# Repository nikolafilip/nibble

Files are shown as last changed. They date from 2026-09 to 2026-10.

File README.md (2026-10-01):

# Nibble

A 4-bit computer built from individual transistors, in public.

No integrated circuits anywhere. Transistors, resistors, diodes, capacitors,
LEDs, switches, connectors and wire. Every board is designed in KiCad,
simulated in ngspice, fabricated as a through-hole PCB and hand-soldered.

An AI (Claude) does the schematic generation, simulation and layout.
Nikola sets the constraints, reviews, orders, solders and measures.
The commit trailers say which is which.

## Layout

| Path | What |
|---|---|
| `docs/` | Architecture, instruction set, bus header, gate cell, build plan, decision ledger, known issues |
| `boards/00-origin-calculator/` | The hand-made 3-bit add/subtract calculator this started from, untouched |
| `boards/01-alu/` | 4-bit ALU: add, subtract, and, or, xor, increment, decrement, with flags |
| `boards/02-registers/` | A, B and OUT registers |
| `boards/03-sequencer/` | Step counter, instruction and operand registers, flags, decoders and the diode control matrix |
| `boards/04-program/` | Program memory: 16 words on DIP switches, one page of 256; build more for longer programs |
| `boards/05-clock/` | Clock with a speed knob, RUN/STEP, halt and power-on reset |
| `boards/06-panel/` | Front panel: switches for every line, LEDs on every line, the input port |
| `boards/07-hub/` | Bus hub: power, pull-ups, eight slots |
| `boards/08-memory/` | Data memory: 16 slots of 4 bits, every cell with an LED |
| `boards/09-counter/` | 8-bit program counter and return register |
| `coupon/` | Gate-cell test board: measure the real cell before trusting anything |
| `lib/` | Shared SPICE models and KiCad libraries |
| `sim/` | Generators, testbenches, the emulator and the whole-machine simulation |
| `experiments/muldiv/` | A multiplier/divider designed on the original RTL calculator. Simulated, not built |

## Start here

1. `docs/architecture.md` — what the machine is and how the boards fit together.
2. `docs/isa.md` — the instruction set (31 instructions in 16 opcodes) and a worked program.
3. `docs/bus-header.md` — the 64-pin ribbon header every board shares.
4. `docs/gate-cell.md` — the one logic cell everything is made of.
5. `docs/plan.md` — the gates every board passes before copper exists, and the whole-machine simulation.
6. `docs/cards.md` — the machine as 100 x 100 mm cards on one crimped ribbon (2026-09-10 evening), and the order of work from here.
7. `docs/mounting.md` — the panel it stands on.
8. `docs/DECISIONS.md` — why things are the way they are, in order.

## Status

See `docs/DECISIONS.md` for the latest entry and `docs/KNOWN-ISSUES.md` for what is wrong.

## Licence

CERN-OHL-P-2.0 for the hardware, MIT-equivalent terms for the scripts. See `LICENSE`.

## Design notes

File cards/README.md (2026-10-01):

# Cards

The machine as 100 x 100 mm boards on one crimped ribbon (docs/cards.md, D042
to D045). Every card has the 64-pin bus header along its top edge, soldered on the
back (D059; pin 1 top left as the front sees the holes, `docs/bus-header.md`),
two M3 holes mid-height on the sides, 100 nF + 10 uF at the top
right, and its logic on the dense tile: 7.68 mm columns, one TO-92 per 5.08
mm row, the pull-up lying along the row above its stack, GND and +5V rails
alternating between the columns on the back. Generated by `sim/build_*_card.py`
from the gate lists in `sim/`; laid out and routed by `sim/pcb.py`. Do not
hand-edit the schematics. Each card's `fab/` folder has the gerbers and their
zip, two renders, the assembly drawing (`<card>-assembly.svg`: which value
goes where, the boards print none) and the parts list. The Nibble logo
(`lib/logo/nibble.png` traced by `sim/logo.py`) is on the sequencer's
front silkscreen alone, one maker's mark on the machine; the cards carry
their name.

| Card | Directory | Transistors | Bus signals | Neighbour link |
|---|---|---|---|---|
| Register bit 0..3 | `reg0` .. `reg3` | 99 each | in: BUS<i>#, CLK, AI, AO, BI, BO, BA, AB, OI. out: A<i>, B<i>. BUS<i># driven open-drain when AO or BO | none |
| ALU bit 0..3 | `alu0` .. `alu3` | 66, 68, 68, 73 | in: A<i>, B<i>, SUB, ONE, F1, F0, EO. out: BUS<i># (open drain); bit 3 also CF, ZF | 2x3: carry C<i+1> and zero-so-far ZS<i> to bit i+1 |
| Counter bit 0..7 | `ctr0` .. `ctr7` | 62 (59 for bit 7) | in: PCL, CLK, RST (bit 0 also PCE). out: PC<i> | 2x3: count carry TC<i+1> to bit i+1; 2x6 chained ribbon from the sequencer: OPR<i>, PCR, RAI |
| Memory control | `memctl` | 57 | in: BUS3..0#, MAI, MI, MO, CLK | 2x6 chained ribbon to the slot cards: MAR3..0 and complements, MIN, MON |
| Memory slot pair | `memslot` (x8) | 91 | BUS3..0# in (MI) and out (MO, open drain) | the ribbon from memory control; jumpers A3 A2 A1 pick the pair |
| Program, four words | `prog` (one per four words) | 41 + 32 diodes | in: PC7..0. out: M7..0 through diodes | none; jumpers P7 P6 P5 P4 G3 G2 pick the addresses 4c..4c+3 |
| Clock | `clock` | 15 + the Schmitt pair | in: HLT. out: CLK, RST | none |
| Hub | `hub` | 0 | every line, on two headers | none |
| Panel A, B, C | `panela`, `panelb`, `panelc` | 28, 20, 32 | A: A3..B0, SUB..AB switched and shown, D3..0 CF ZF CLK RST shown. B: OI..MAI, MI..INP switched and shown, CLK and RST buttons. C: PC7..0, M7..0 shown, DATA switches driven onto BUS# while INP | none |
| Coupon | `coupon` | 57 | power only (a 2-pin header for the bench supply) | none |

## Register bit cards (`reg0` .. `reg3`)

Bit i of the three registers on the bus: A and B (the ALU's operands) and
OUT (the display), as three master-slave D flip-flops with their input muxes
(A takes the bus when AI, B when AB, else holds; B takes the bus when BI, A
when BA, else holds; OUT takes the bus when OI, else holds), the bus driver,
and the card's own two-phase clock (PH1, PH2 from CLK, D033) and hold
decoders. Four designs, the bit baked in, because a bit is three bus lines
and two cards jumpered alike would fight over them. `sim/registers.build_bit`
is the same logic as board 02 sliced per bit; the boards' testbench and the
machine deck take the four cards as the group `regc`.

Verification (2026-09-10), from the kicad-cli exports of the four routed cards
on one bus (`sim/tb_registers.py cards`), the 113-step register script: every
value through A and B, A and B driven back, MOV, XCH, OUT, holds:

| Netlist | Corner | Result |
|---|---|---|
| kicad-cli exports, four cards | TYP, LO, HI | 113 / 113 each |
| kicad-cli exports, four cards | MIX seeds 1, 2, 3 | 113 / 113 each |
| gate list (`cards@dev`) | TYP, LO, HI, MIX 1, 2, 3 | 113 / 113 each |

Machine gate (2026-09-11): `sim/gate.py --boards alu,hub,regc`, all twelve
programs at TYP with the four cards in the deck, 0 mismatches each (fib 127
ticks, calc 616, lfsr 1497, sort 974, mul 314, the rest between).

Layout: each card routes DRC-clean in one freerouting pass (0 unconnected),
ERC clean, 10.3 of 11 tile columns used.

Reproduce from `sim/`:

```
python3 build_reg_card.py 0                    # and 1, 2, 3
<kicad python> pcb.py ../cards/reg0 reg0
python3 tb_registers.py cards out/tb_regcards --corner MIX --seed 2
python3 machine.py programs/fib.asm --boards alu,hub,regc --corner TYP
```

## ALU bit cards (`alu0` .. `alu3`)

Bit i of the ALU: the full adder/subtractor bit (B xor SUB, carry in from
bit i-1), AND, OR, XOR selected by F1 F0, and the open-drain bus driver
while EO. Bit 0 starts the carry with SUB and the zero chain; bit 3 ends
them in CF and ZF on the bus. The carry and zero-so-far run over a 2x3 IDC
link between neighbouring cards (`frame.card_links`: IN at the bottom left,
OUT at the bottom right). `sim/alu.build_bit` is board 01 sliced per bit;
the group `aluc` stands for the four cards in the machine deck.

Verification, from the kicad-cli exports of the four routed cards chained by
their links (`sim/tb_alu.py cards --cases exhaustive`): every A, B, SUB, ONE,
F1 F0 combination, 2304 cases.

| Netlist | Corner | Result |
|---|---|---|
| kicad-cli exports, four cards | TYP | 2304 / 2304, worst settle 54 us |
| kicad-cli exports, four cards | LO | 2304 / 2304, worst settle 28 us |
| kicad-cli exports, four cards | HI | 2304 / 2304, worst settle 90 us |
| kicad-cli exports, four cards | MIX seed 1 | 2304 / 2304, worst settle 69 us |
| gate list (`cards@dev`) | TYP | 2304 / 2304 |

Layout: alu0 and alu3 route in one freerouting pass; alu1 and alu2 needed
the 300-pass cap and the 0.6 mm via (their last net drops from the bus
header into the first column). All four DRC clean, 0 unconnected.

## Counter bit cards (`ctr0` .. `ctr7`)

Bit i of the program counter (count when PCE, load the jump target OPR<i>
when PCL, load the return address RA<i> when PCR, clear on RST) and of the
return register RA (a transparent latch open while RAI and PH1). The count
carry TC<i+1> = TC<i> and PC<i> runs over the 2x3 links; the sequencer's
operand and load lines come down a chained 2x6 ribbon (`frame.card_ribbon`),
each card taking its own OPR line. Group `ctrc`.

Verification: `call.asm` on the eight cards from the gate lists, 0
mismatches; the exports carry every program of the step 9 gate
(`sim/results/gate25_*.md`).

## Memory control and slot cards (`memctl`, `memslot`)

Control: the four-bit address register MAR (transparent latches open while
MAI and MPH) and the write and read gates MIN (low while MI and MPH) and
MON (low while MO), sent to the slot cards over a chained 2x6 ribbon with
MAR and its complements. MPH is a pulse in the middle of the tick (D054):
CLKD is CLK through 100k into 2.2 nF on the sheet, and MPH = NOR(CLK, NOT
CLKD) is high from the falling edge of CLK until CLKD decays past a
threshold, 60 to 350 us, so the address latch closes and the write ends
hundreds of microseconds before the next rising edge. The first card gated
both with PH1, the low half of CLK, which ends at the rising edge: with the
clock card's 35 us edge and the threshold spread between cards, the
sequencer stepped and the next tick's data reached the bus 10 us before this
card saw the edge, and the address latch took the data as the address (gcd,
list and logic at mixed seed 2 wrote slots 12, 9 and 15 instead of 0). Slot pair:
two 4-bit slots (even: MAR0 = 0, odd: MAR0 = 1) of the pair the three
jumpers select (A3 A2 A1: the centre pin to '1' where the address bit is 1),
eight cross-coupled cells with their write and read pull-downs, and an LED
per cell. One design, eight cards, jumpered 0 to 7. Group `memc`.

The jumpers bring MAR1..3 (or their complements) onto the card, so in the
deck they are ports of the slot subcircuit (`machine.ports_of`); left
inside they float, and every read came from slot pair 7.

Verification, `sim/tb_memory.py cards`: three fills of all sixteen slots
and reads back, single writes between reads, bus noise while nothing loads,
217 steps. `--race` is the edge as the memory card saw it in the machine:
CLK rises over 35 us, the bus switches 10 us into the rise and the control
lines 100 us after it (they lag every edge by 60 to 170 us).

| Netlist | Corner | Result |
|---|---|---|
| PH1-gated card (before D054), gate list, `--race` | TYP, HI, MIX 1, MIX 2 | 121, 121, 121, 170 / 217 (`sim/out/tb_memory_oldD054_race.log`) |
| PH1-gated card (before D054), gate list, `--race` | LO | 217 / 217 (the card sees the edge at 0.8 V, before the bus moves) |
| D054 card, gate list (`dev`) | TYP, LO, HI, MIX 1..4 | 217 / 217 each (`sim/out/tbmem54_dev.log`, `tbmem54_mix.log`) |
| D054 card, gate list (`dev`), `--race` | TYP, LO, HI, MIX 1..4 | 217 / 217 each |
| D054 card, kicad-cli exports, control + eight slot cards | TYP; `--race` TYP, LO, HI, MIX 1, MIX 2 | 217 / 217 each (`sim/out/tbmem54_cards.log`) |

Layout: both cards route DRC clean in one pass, 0 unconnected.

## Program card (`prog`)

Four words of eight DIP switches; a closed switch pulls its M line high
through a diode while the word's row is selected (3.3k row pull-ups, so a
row of eight ones still reads 3.8 V against the hub's 220k, D048). Six 1x3 jumpers strap the
card to its addresses: P7..P4 the page (PC7..4), G3 G2 the word group
(PC3..2), the centre pin to '1' where the address bit is 1; PC1..0 pick the
word. A program of n words takes ceil(n/4) cards (`list` 6, `sort` 20). In
the deck (`progc`) one copy per four words is instantiated with its jumpers
and switches set from the assembled program; `prog.map.json` says which
diode is word w bit i.

Verification: `fib.asm` on the card gate lists with the ALU and hub, 0
mismatches; the exports carry every program of the step 9 gate
(`sim/results/gate25_*.md`).

## Clock card (`clock`)

Board 05's circuit on a card: the source-coupled Schmitt RC oscillator with
the speed pot and SLOW jumper, the RUN/STEP switch, the halt gate, the
power-on reset, and the hold-off (`sim/clock.py`, drawn by
`build_clock_card.py`). The hold-off (D064): a 2N7000 from the oscillator's
timing node X to ground through 100 ohm, its gate on the RST line. While
RST is high the timing capacitor is held empty, the Schmitt trigger reads
low and the clock gate holds CLK low; when RST lets go, the card's own
reset or the panel's button, X charges from 0 V and the first clock edge
comes 1.3 to 5.7 ms later at the fastest setting (`sim/results/reset_release.md`,
`starts_hold.md`), never in the 45 us in which the cards leave their
resets, which had started the machine wrong once in a hundred times
(`sweep_por.md`). HLT
reaches the halt gate through 100k into 2.2 nF (0.22 ms, D050), so the
clock pulse that started the halt step completes before the clock stops.
CLK's pull-up in RUN is 1k and RST comes from a 1k inverter stage (RD = NOT
PB) through 100 ohm and a diode, against the panel's 10k pull-downs (D053):
into the machine's 3 nF CLK rises 0.5 to 3.5 V in about 6 us (the first card
took 35 to 43 us, and the cards, each reading the edge with its own
transistors, saw it up to 25 us apart) and RST releases in 45 us (the first
card's drifted for 8 ms and more, so cards left reset on different edges).
`sim/tb_clock.py` measures both under that load and requires them
(TYP, LO, HI, MIX 1..2 pass: `sim/out/tb_clock_cards54_*.log`; the first
card under the same bench: CLK rise 43 us, RST never released cleanly,
`sim/out/tb_clock_cards_oldD053_TYP.log`).
Deck name `clkc`. The step 9 gate runs with this card driving CLK and RST
and no testbench clock or reset, every deck a power-up from 0 V: all
thirteen programs at TYP and the 24 corners, 0 mismatches
(`sim/results/gate25_TYP.md`, `gate25_corners.md`). The first card, in the
same deck, passed all thirteen at TYP and lost gcd, list and logic at MIX
seed 2 to the address-latch race its slow edge opened
(`sim/results/gate_clk_corners_oldclock.md`, D053, D054).

## Hub card (`hub`)

Two bus headers, one along the top edge and one along the bottom, one per
column face's ribbon (D043), the 64 lines routed between them. Ground is
wired, not poured: a ring above the top header's pads, down the right edge
and below the bottom header's, with bars for the capacitors, the LED and
the M pull-downs (the lines cut a pour to islands). The bench supply's
banana leads into two 4 mm sockets standing on the front face (Cal Test
CT3151V1, soldered in on four pins, D063), 19.05 mm apart so a dual plug
fits (no USB, D057), through a 1.5 A polyfuse (D052) and past a crowbar
(D061: above 6.3 to 7.8 V a zener fires an SCR that holds the rail near
1 V; a 3 A diode takes crossed leads; `sim/results/crowbar.md`), the four bus pull-ups, the eight M-line pull-downs (220k, D048:
with 1 Meg an M line released by a jump took 0.6 ms to fall), a power LED,
100 uF, test loops on BUS3..0, CLK and RST, and an empty spot (C-RST,
do not populate) for a 2.2 nF from RST to ground should the scope show
more pickup on RST than the simulation says (bring-up section 9). Deck
name `hubc`.

## Panel cards (`panela`, `panelb`, `panelc`)

A: DIP-8 level switches for A3..A0 B3..B0 and SUB EO AI AO BI BO BA AB
(10k to +5V: a switch left on never fights a card pulling low), LEDs for
those lines, for the bus data (an inverter per BUS<i>#), CF, ZF, CLK and
RST. B: switches and LEDs for OI IO II PCE PCL FI HLT MAI and MI MO WRL
WRH ONE F0 F1 INP, and the CLK and RST buttons with their RC debounce and
Schmitt triggers (the second inverter has a 1k pull-up and drives the line
through 100 ohm and a diode, D053). C, the operator's card: PC7..0 and M7..0
LEDs, the four DATA switches and the input port (driven onto BUS# while
INP). Every switched or observed line has a 1Meg pull-down on the tile
(`PD` cells) except M, pulled down on the hub, and CLK and RST, whose
pull-downs on card A are 10k (D053: they set the falling edges of both
lines, 30 us into 3 nF). The LEDs read row by row like the old
panel: a tile column holds one panel column (three LEDs on A, two on B and
C). Group `pnl`.

## Coupon card (`coupon`)

Every cell in copper, each with a test loop, powered from a 2-pin header
on the bench supply or from the bus header (D056, `sim/coupon.py`,
`sim/build_coupon_card.py`): the 5-inverter ring (a buffered loop and a raw
one on the ring node), fan-out 1 and 10, 3-input NAND and NOR, a bus driver
with the hub-style 10k pull-up, the clock card's oscillator (the Schmitt
pair and its 100k + 47 nF, drawn on the sheet as on `clock`), a master-slave
flip-flop wired as a toggle with its asynchronous reset (RST on the input
header), the D053 line driver (1k inverter, 100 ohm, diode, 10k pull-down;
the bench clips 3.3 nF on its loop), a diode-connected transistor on 4.7k
that reads its own threshold, a program row (3.3k, 1N4148, 220k), an LED.
Inputs IN, N1..N3, RST on a 1x6 header with 1 Meg pull-downs (PD tiles);
fifteen loops including GND and +5V. 57 transistors on six tile columns,
routed in one freerouting pass, DRC clean.

`sim/tb_coupon.py kicad` simulates the routed card's export at TYP, LO, HI
and MIX seeds 1..3 with a x10 probe on every loop and writes the bands
the bench must land in: `sim/results/coupon_expected.md` (ring 5.9 to
23.6 us, fan-out-10 rise 67 to 77 us, oscillator 1.64 to 2.55 ms, Q at
half that, DRV rise 6.6 us and fall 49 us into 3.3 nF, VTO 0.88 to 3.02 V,
5 to 14 mA). `dev` runs the gate list plus the sheet-drawn parts and gives
the same numbers at the uniform corners, so the sheet matches the design.
Two things the testbench found that the bench should know: with
low-threshold transistors the ring swings only to about 2 V and a
high-threshold buffer never switches (hence the raw RING0 loop), and while
RST holds the flip-flop a pulse of up to 4 V and 10 us can appear on Q at a
rising clock edge at some threshold mixes (the master's release racing the
slave's copy; the machine's masters are closed then, and every MIX run of
the machine gate passed with it). Its own testbench sheet is excluded from
the board.

Reproduce from `sim/`:

```
python3 build_coupon_card.py
<kicad python> pcb.py ../cards/coupon coupon
python3 tb_coupon.py kicad out/tb_coupon --all
```

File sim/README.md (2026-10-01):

# sim: generators and testbenches

| File | What |
|---|---|
| `nmos.py` | The cell family: INV/NAND/NOR/BUS/LED cells, XOR and D flip-flop macros, fan-out, floating-input and node-name checks, SPICE emitter |
| `ksch.py`, `frame.py`, `knet.py` | KiCad 10 schematic writer (gate lists as cells, header, decoupling, indicators, testbench sources), the common board frame, netlist parser |
| `bus.py` | The 64-pin header pinout (docs/bus-header.md): `PINS` is what the header's pins carry, soldered on the back (D059, D062); `HOLES` is the table the copper was routed to |
| `alu.py`, `build_alu.py`, `tb_alu.py` | Board 01: logic, generator for `boards/01-alu/`, testbench (demo or exhaustive cases, TYP/LO/HI/MIX corners, dev netlist or kicad-cli export) |
| `registers.py`, `build_registers.py`, `tb_registers.py` | Board 02: logic, generator, testbench (a clocked script through every register path; `cards` runs it on the four bit cards) |
| `build_reg_card.py` | Register bit cards `cards/reg<i>/` (docs/cards.md) from `registers.build_bit`, on the dense tile (`ksch.DenseWriter`) in the 100 x 100 card frame (`frame.card_frame`) |
| `panel.py`, `build_panel.py` | Board 06: switches, buttons, LEDs, input port |
| `build_hub.py`, `coupon.py`, `build_coupon.py` | Board 07 (hub) and the gate coupon (`build_coupon_card.py`, `tb_coupon.py`: the coupon card and its expected readings, D056) |
| `plots_alu.py` | Transient plots from a testbench run |
| `emu.py` | Tick-accurate ISA emulator; the reference for the whole-machine simulation |
| `asm.py` | Assembler; `programs/*.asm` are the reference programs, `test_emu.py` runs them on the emulator |
| `machine.py` | The whole-machine deck: every existing board's export plus emulator stand-ins for the rest, one program, compared tick for tick |
| `gate.py` | The machine gate: every program, every corner, one summary table (`out/gate_<boards>.md`) |
| `pcb.py` | Placement, power rails, freerouting, DRC, fab outputs (run with KiCad's python). On a routed board, in place and without a re-route: `--silk` (the labels again from the plan, then `place_logo` where the plan asks for the logo (the sequencer's): icon and word where 27 x 8 mm is free and the icon alone otherwise, nearest the board's name; then `fit_silk`: every label to 1.0 mm where it has room, off pads, vias, outlines and the logo, out from under the parts), `--patch`, `--back-header` (the bus headers onto the back in the holes they have) |
| `bom.py` | The order's tables (boards to have made, parts to need and to buy with the spares rule, the pilot's parts) from the routed boards; the schematics' count and the boards' count must agree; `--write` puts them into `docs/order-1.md`, `--check` fails when the document is stale |
| `sweep_por.py` | The reset-release sweep: fib for 12 ticks on the whole card deck with the clock card's power-on reset released at 13 phases against the clock (`POR_V0`, `RESET_S` in `machine.py`), TYP and MIX seeds 1, 2; writes `out/sweep_por.md` |
| `tb_reset_release.py` | The hold-off (D064) on the clock card alone: power-on and 20 presses of the panel's RST button walked across the clock period, at six corners and four speeds, with the two parts and without. `HOLD=1` puts the same two parts into the machine deck, `RST_PRESS=down,up` a finger on the panel's RST button |
| `starts_hold.py` | The machine's starts with the hold-off in the deck (`HOLD=1`): every start of the reset sweep again at the `POR_V0` it had, a start at four more corners, and the panel's RST button pressed while the machine runs (`RST_PRESS`). fib for 12 ticks each; `END_AFTER_RELEASE=1` ends such a run 47 ms after RST fell for the last time. Writes `results/starts_hold.md` |
| `mix_order.json` | The order in which each board's transistors draw their models at a mixed corner (`machine.py --mix-order` wrote it from the schematics of 2026-09-29): kicad-cli lists symbols in the order of their ids, the builders draw ids at random, so a card built again would otherwise get another threshold on every transistor |
| `assembly.py` | The assembly drawing, `cards/<card>/fab/<card>-assembly.svg`: the front as the silk shows it, every part that is not the card's commonest resistor or a 2N7000 coloured and labelled with its value (the cards print none); written by `pcb.py` with the fab outputs (plain python3) |
| `order_check.py` | The order gate on a board's committed files (the 25 cards and the sequencer): clean tree, routed rules in the project file, ERC, DRC with parity, JLCPCB minimums (`jlcpcb.kicad_dru`), fab files and zip equal the board, outline and holes, every part's pads and polarity, the silkscreen (nothing clipped, the bus header on the back and the back says so, the logo where the plan asks), the assembly drawing is the board's, no copper of another net where a socket's nut or a standoff clamps. `--machine`: every bus header against `bus.py` and every link against its far end, pin by pin. `--selftest`: the rules against faults planted on purpose (plain python3) |
| `board_diff.py` | What changed on a routed board since a commit, measured: netlist, tracks, vias, holes, and every copper and mask gerber as what it draws (`gerber_diff.py`). The proof that goes with a change made in place |
| `rebuild_check.py` | Runs every builder into a scratch directory and compares its plan and netlist with the committed ones: a change made in place must be in the builder too |
| `logo.py` | `lib/logo/nibble.png` traced into `lib/nibble.pretty/Logo_Nibble.kicad_mod` (icon and word, 27 x 8 mm) and `Logo_Nibble_Icon.kicad_mod` (8 x 8): filled silkscreen polygons, holes slit in; the ribbon's lines print 0.39 mm wide, 0.24 mm apart, over the fab's 0.15 mm minimum (plain python3 with Pillow, numpy and potracer) |
| `silk_proof.py` | The print as the fab gets it, pads, mask and silkscreen without the parts, front and back, to `out/proof/`: for the eyes |
| `tb_rst_neighbour.py`, `tb_crowbar.py` | Benches outside the machine's logic: the reset line beside BUS1# on the ribbon (D062); the hub's crowbar and reverse diode (D061, models in `lib/power.lib`). Each writes its table to `results/` |
| `spicedat.py` | Fast reader for ngspice `wrdata` files |
| `out/` | Scratch (ignored by git). `out/cell.cir` characterises one cell |

Needs ngspice (`brew install ngspice`), numpy, matplotlib, and KiCad 10 for
`kicad-cli` and the shared symbol libraries.

Rules that the generator enforces are in `docs/gate-cell.md`. ngspice node
names are case-insensitive, so never create two nets that differ only by case.

## PCB flow

`pcb.py` (run with KiCad's bundled python, see the docstring) takes a project's
schematic and its `<name>.plan.json` (placements, silkscreen labels, power
rails; written by the `build_*.py` generators) and produces the `.kicad_pcb`:
footprints placed, power pre-routed, signals routed by freerouting (headless,
retried until DRC reports zero unconnected), a ground pour on the back, DRC, and
`fab/` outputs (gerbers, drill, BOM, position file, renders).

    <kicad>/python3 pcb.py ../boards/01-alu alu

The `fab/` outputs (gerbers, drill, BOM, position file, renders) are committed with the board, as built.

## Whole-machine simulation

    python3 machine.py programs/fib.asm --boards alu,hub,reg,panel [--corner MIX --seed 2] [--ticks 40]
    python3 gate.py --boards alu,hub,reg,panel -j 2          # all programs, all corners (two decks at a time on a 36 GB machine)
    python3 gate.py --boards aluc,hubc,regc,seq,ctrc,memc,progc,pnl --corners TYP -j 2     # the machine as cards
    python3 gate.py --boards aluc,hubc,regc,seq,ctrc,memc,progc,pnl,clkc --corners TYP -j 2 --ticks 12     # the smoke gate: first twelve ticks of every program, about three hours; run it before every long queue and after every harness change
    python3 gate.py --boards aluc,hubc,regc,seq,ctrc,memc,progc,pnl,clkc --corners LO,HI,MIX --seeds 1,2 -j 2 --resume out/ledger.jsonl     # a long gate keeps a ledger of finished runs: cut short, the same line picks up at the first run without a passing row

Board names: the nine boards (`alu`, `hub`, `reg`, `seq`, `ctr`, `mem`,
`prog`, `panel`, `clk`) and the cards (`reg0..3` or the group `regc`,
`alu0..3` / `aluc`, `ctr0..7` / `ctrc`, `memctl` + `memslot` / `memc`
(eight slot copies with their jumpers), `progc` (one program card per
four words, jumpered and switched from the program), `panela..c` / `pnl`,
`clkc`, `hubc`). A board named `x@dev` is taken from its gate list instead
of the schematic export, for trying a design before drawing it. The deck runs the clock at
1 ms per tick; a 130-tick program with three boards takes two to three
minutes per corner. Registers that have no reset (A, B, OUT) are compared only
from the tick after the program first writes them.

Things ngspice taught us, so nobody learns them twice: `pwl()` in a B-source
extrapolates outside its points; a B-source with a `?:` step inside it fails
with "timestep too small" sooner or later, use the `SW` switch model for an
ideal driver; a net named `PWL` cannot be probed.

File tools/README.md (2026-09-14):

# tools

`freerouting-1.9.0.jar` (5 MB) is not in git. Download it from
https://github.com/freerouting/freerouting/releases/tag/v1.9.0 and run it
with Java 21 (it needs a display session even in batch mode; no `-Djava.awt.headless`):

    java -jar tools/freerouting-1.9.0.jar -de board.dsn -do board.ses -mp 40

`sim/pcb.py` calls it for the cards. `freerouting-2.1.0.jar` (also not in
git, same releases page) is what the sequencer board needs: on that board
1.9 takes hours for a single pass (a thread dump shows it deep in the maze
search), while 2.1.0 does a pass in five to ten minutes. Tested 2026-09-11:
2.1.0 honours `-mp N`, stops after N passes and writes the SES with what it
has, and logs the unrouted count after every pass. A plan picks it with
`extra.router.jar = "freerouting-2.1.0.jar"` (the sequencer's does).
Neither version logs an unrouted count when it gives up early in the way
1.9 does on the cards, so KiCad's DRC is the gate in `pcb.py`.

`freerouting-2.4.1.jar` (same releases page) is what the sequencer uses now
(2026-09-13), and the hub since D052 (1.9 dropped a via inside the bundle of
64 bus lines there and shorted three nets; 2.4.1 routes it clean). It needs Java 25 (`sdk install java 25-tem`); `sim/pcb.py` takes
the JVM from `NIBBLE_JAVA`. Headless it honours `-mp N` and stops on its own
when the score has not improved for ten passes. Its optimizer stage can start
from an older, worse snapshot than the router's last pass and save that, so set
`router.optimizer.max_passes` to 0 in
`~/Library/Application Support/freerouting/freerouting.json`. Findings that
`pcb.py` encodes (plan `extra.router`): a layer marked `(type power)` in the
DSN breaks routing altogether (the ground layer stays a signal layer);
`exclude_nets` takes the power nets out of the router's network and leaves their
pre-routed copper as obstacles; `layer_order` lists the DSN layers so that the
even-indexed ones are the vertical ones (freerouting prefers vertical on even
indexes, horizontal on odd); `route_in1` lets the router use the ground layer,
the pour fills the rest; `attempts` retries from the routed state. The
autoroute settings block freerouting's parser accepts stops 2.1.0 dead (score
NaN), so `pcb.py` writes none.

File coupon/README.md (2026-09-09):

# Gate coupon

26 transistors on a small board: the cell in copper, measured before any other
board is trusted. Power on J1 (5 V), inputs on J2, scope probes on the test loops.

| Test point | What it measures |
|---|---|
| TP_RING | 5-inverter ring oscillator, buffered. Gate delay = period / 10 (simulated period 14 µs) |
| TP_FO1 | Inverter output driving 1 gate. Rise time at fan-out 1 (simulated 4 µs to 2.5 V) |
| TP_FO10 | Inverter output driving 10 gates. Rise time at fan-out 10 (simulated 28 µs) |
| TP_NAND | 3-input NAND, three transistors in series. Output low with N1=N2=N3=1 (simulated 0.9 mV) |
| TP_NOR | 3-input NOR. Output low (simulated 0.1 mV) |
| TP_BUS | Open-drain driver on IN with the hub's 10k pull-up |

Also: supply current with everything low, and the LED cell on IN.
Fill the measured column in `docs/gate-cell.md`. Generated by `sim/build_coupon.py`.

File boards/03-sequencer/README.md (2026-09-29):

# Board 03: sequencer

The control unit: step counter, instruction and operand registers, flags, two
decoders and the diode control matrix. 592 transistors, 354 resistors, 87
matrix diodes on 1035 crossings, 19 LEDs (counted on the routed board). The
program counter and the return register are on the counter cards (D035).

| | |
|---|---|
| Bus signals used | in: M0..M7, CF, ZF, CLK, RST. out: II, PCE, SUB, EO, AI, AO, BI, BO, BA, AB, OI, IO, PCL, FI, HLT, MAI, MI, MO, ONE, F0, F1, INP |
| Bus driven | BUS0#..BUS3# open-drain with OPR3..0 while IO (LDI, LOAD n, STORE n) |
| Link header (2x6) | to board 09: OPR0..OPR7, PCR, RAI, GND, GND |

How it runs an instruction (docs/isa.md):

- **Steps** are a one-hot ring of five flip-flops with asynchronous reset. S0
  loads IR and the operand's low nibble (`II`); S1 counts (`PCE`); S2, only for
  a two-word instruction, loads the second word (`OPI`, `PCE`); S3 and S4 drive
  the matrix rows. The `DONE` column returns the ring to S0.
- **IR and OPR** are transparent latches open while their load line and PH1
  are both high: they follow the memory word during the low half of the clock
  and are closed before the rising edge on which everything else changes.
- **Decoders**: IR3..0 to OP0#..OP15#, OPR3..0 to F0#..F15#, each through a
  pair of 2-to-4 predecoders so no NAND has more than two transistors in series.
- **Rows**: `NOR(OPn#, T3N)` for every opcode, `NOR(OP0#, Fn#, T3N)` for every
  family member, an S4 row for the four memory accesses, and for JC and JZ a
  second row that includes the latched flag; JNZ and JNC the same. 45 rows,
  10k pull-ups.
- **The matrix**: a diode from a row to a column pulls that control line high
  while the row is active. 23 columns with 1 Meg pull-downs: 19 go to the bus
  header, `PCL` too, `PCR` and `RAI` to the link, `DONE` back to the step ring.
  New instructions are diodes; rows OP8..OP15 are free.
- **Flags**: CFQ and ZFQ latched from the ALU while `FI` and PH1.

## Files

- `sequencer.kicad_sch`: generated by `sim/build_sequencer.py` from `sim/sequencer.py`. Do not hand-edit.
- `fab/sequencer-assembly.svg`: which crossing takes a diode and which resistor is not 47k (`sim/assembly.py sequencer`). On the board a crossing that takes a diode has a printed circle; the other 948 are bare pads.
- `fab/sequencer-gerbers.zip`: the eleven files the fab takes (four copper layers). `python3 sim/order_check.py sequencer` is the gate.
- `sequencer.kicad_pcb`, `fab/`: layout by `sim/pcb.py`. The matrix is laid out transposed: rows are vertical tracks at 3.81 mm pitch on the back, columns horizontal tracks at 10.16 mm on the front, a diode standing on each populated crossing.

## Verification

The machine gate (`sim/gate.py`): the reference programs on the kicad-cli
exports of ALU, registers, sequencer and counter with the hub, compared tick
for tick with `sim/emu.py`. Results are recorded in the commit that adds the
routed board.

D041 proof (2026-09-11): list.asm on alu, hub, registers, sequencer, counter and memory at the MIX corner, seed 3, the run that failed before the column buffers: 210 ticks, 0 mismatches (`sim/out/d041_list_MIX3.log`). Seeds 1 and 2 and the other programs are in the card gate.

Layout (D051, 2026-09-11, amended 2026-09-13): 245 x 255 mm on four layers, the tiles at the card pitch; layer 2 is a ground pour with a few routed tracks, layer 3 a third routing layer (two layers left the router about 100 nets short at this pitch and about 70 at 10.16 mm, D049). Routed with freerouting 2.4.1 (Java 25) with the layers ordered so that layers 3 and 4 route vertically and 1 and 2 horizontally, the power nets out of its network (the rails, stubs and vias are fixed copper) and the optimizer off. The matrix rows and columns are hidden from the router on the outer layers and a keepout fences the matrix, but the matrix diodes stay in the DSN with their pins off the nets, so layer 3 threads between their pads across it. Each matrix column tail ends on a fixed via 4.5 mm before the keepout with a short stub on layer 3, where the router picks it up on its vertical layer. The 45 row drivers stand under their matrix columns (three per tile column, left to right). The left field, 12 columns, is split: its right five columns start one tile row lower, leaving an 8 mm strip under the header's right half for the fan-out to pins 42 to 64, and the output buffers stand in the column under their own header pin; the 23 column buffers fill the columns beside the matrix, where the tails come out. The +5V feed runs along the top edge and down the right side of the board, never through the corridor between the left field and the matrix.

Routed board (2026-09-14, route v9): 0 unconnected, 0 DRC errors on the rules it was routed with (0.2 mm track, 0.15 mm clearance). The 132 warnings, read one by one on 2026-09-28: 59 dangling fixed stubs, by design (the 45 matrix column tails and the In2 stubs of the row tails the router did not need); 67 silkscreen overlaps (the printed circles of diodes on neighbouring crossings touch at 2.54 mm; two LED names touch a transistor's outline); 6 LED names clipped by a pad's mask opening (OPR0, OPR1, OPR3, OPR5, OPR6, ZFQ), which move in the silkscreen pass. One hand patch after the router, recorded in the plan (`extra.patches`) and applied by `pcb.py`: freerouting had hooked ENF across CFQ_m1 on layer 3 beside Q380. The SPICE export of this schematic is line for line the one the machine gate ran (resistor pin order aside): the tile mirroring of the re-placement is the only difference. Gate results on the card deck with this sequencer: all twelve programs at TYP, 0 mismatches (lfsr 1497 ticks, rerun with the virtual reset fixed in machine.py, `sim/out/cards_lfsr_TYP.log`); fib, alu, gcd, list, logic, call at LO, HI, MIX1 and MIX2: 24 of 24 runs, 0 mismatches (`sim/out/gate_cards_corners.log`); fib, list, logic, calc at TYP and LO with 500 pF per bus line: 8 of 8; fib and call with the clock card driving CLK: 0 mismatches (docs/cards.md step 9).

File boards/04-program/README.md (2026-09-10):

# Board 04: program memory

16 words of 8 bits on DIP switches: one page of the 256-word program space.
112 transistors, 69 resistors, 17 LEDs, 16 DIP-8 switches, 128 diodes.

| | |
|---|---|
| Bus signals used | in: PC0..PC7. out: M0..M7 through diodes (the hub holds M low; several pages OR together) |
| Headers | two 64-way, wired pin for pin in parallel (D039): the hub's ribbon on the left one, the next page's on the right one. Every line is carried, not only PC and M |
| Size | 216 x 250 mm (12 mm wider than the switch array needs, so both shrouded headers and the corner hole fit along the top edge) |

- **Word select**: PC3..0 through a 4-to-16 decoder.
- **Page compare**: four jumpers, one per bit of PC7..4. Pins 1-2 mean "this
  page has a 1 in that bit", pins 2-3 a 0. All four on 2-3 is page 0
  (addresses 0 to 15). PAGE = all four match.
- **Rows**: ROWn = word n selected and PAGE, 10k pull-ups. An LED per row
  shows the word being fetched.
- **Switches**: word n's DIP-8 has the row on one side and a diode from each
  switch to its M line on the other. Closed = 1. Bit 7 is the top switch (the
  top bit of the opcode); blank memory reads 0000 0000 = NOP.

More program space is more copies of this board, each strapped to its page
(D019), daisy-chained with 10 cm ribbons from one page's right header to the
next page's left header; only the first page runs a cable to the hub (D039).
`python3 sim/asm.py programs/<name>.asm` prints the switch pattern per word.

Generated by `sim/build_program.py` from `sim/program.py`; it also writes
`program.map.json` (which diode is which word and bit) so the machine
simulation can close the switches for a program. Machine gate: every program,
with the behavioural memory model replaced by one copy of this board per page.

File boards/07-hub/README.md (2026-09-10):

# Board 07: bus hub

No logic. USB-B power entry through a 750 mA polyfuse, a power LED, bulk
capacitance, the four 10k pull-ups for BUS0#..BUS3# (the only pull-ups on the
bus in the whole machine), test loops on the bus, clock and reset lines, and
eight identical 64-pin headers. Every board plugs in with a straight 64-way
ribbon cable. The USB plug is the power switch.

Generated by `sim/build_hub.py`. ERC clean.

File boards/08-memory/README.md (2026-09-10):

# Board 08: data memory

16 slots of 4 bits with its own address register. 747 transistors, 287
resistors, 68 LEDs: one per cell, so the memory is visible.

| | |
|---|---|
| Bus signals used | in: BUS0#..BUS3# (an address while MAI, data while MI), MAI, MI, MO, CLK |
| Bus driven | BUS0#..BUS3# open-drain with the addressed slot while MO |

- **Address register**: four transparent latches open while `MAI` and PH1. A
  memory instruction puts the address on the bus for its whole S3 tick (B for
  `LOAD [B]`, the operand for `LOAD n`), so the latch closes on it before the
  edge.
- **Decoder**: MAR3..0 to W0#..W15# through 2-to-4 predecoders. Per slot a
  write line WR = slot and `MI` and PH1, a read line RD = slot and `MO`.
  The write is gated by PH1 so it ends at the clock edge, before `MI` and
  the bus change (D037): the first design let the write line outlast the
  data by a few microseconds, and at the mixed-threshold corner the write
  stacks flipped cells with the next tick's bus data. The shared MI line has
  a 4.7k pull-up so the sixteen write lines drop within microseconds.
- **Cell**: two cross-coupled inverters. While WR, the bus data forces it:
  D pulls QN low (a 1), BUS# itself pulls Q low (a 0). While RD and Q, a
  two-transistor stack pulls the bus line low (reads a 1). Eight transistors,
  two resistors, one LED per bit; 512 transistors in the array.
- **No reset**: memory keeps its contents through RST and powers up random.
  Programs write before they read.

Generated by `sim/build_memory.py` from `sim/memory.py`.

Schematic gate: `sim/tb_memory.py` writes every slot three times (slot
number, its complement, a scrambled pattern), reads everything back, and
interleaves single writes with reads of untouched slots: 217 steps, the bus
and the control lines changing at the same instant, which is the worst case
the machine only approaches at some corners. The kicad-cli export passes
217/217 at TYP, LO, HI and mixed-threshold seeds 1 to 3. The board as first
drawn failed 47 steps at every corner.

```
kicad-cli sch export netlist --format spice -o out/mem/memory_kicad.cir ../boards/08-memory/memory.kicad_sch
python3 tb_memory.py out/mem/memory_kicad.cir out/mem --corner MIX --seed 2
```

Machine gate: `list.asm`, `mul.asm`, `sort.asm`, `lfsr.asm`, `calc.asm`,
`logic.asm`, `call.asm` (see `sim/gate.py`).

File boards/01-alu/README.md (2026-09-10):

# Board 01: ALU

4-bit ALU: two's-complement adder/subtractor, AND, OR and XOR, with carry and
zero flags. The redesign of the origin calculator's arithmetic (issues #1 to
#4), extended for design v2 (D031) with ONE (B replaced by 0001 for INC and
DEC) and the function lines F1 F0.

| | |
|---|---|
| Transistors | 233 × 2N7000 |
| Resistors | 133 (127 × 47k pull-ups, 6 × 1k for LEDs) |
| LEDs | 6 (R3..R0, CF, ZF) |
| Other | 64-pin bus header, 100 nF + 10 µF decoupling, 4 × M3 holes |
| Bus signals used | in: A0..3, B0..3, SUB, ONE, F0, F1, EO. out: CF, ZF, BUS0#..BUS3# |

With F1 F0 = 00 the result is `R = A + (B xor SUB) + SUB` and `CF` is the carry
out of bit 3 (for a subtraction, 1 means no borrow). F1 F0 = 01, 10, 11 give
A and B, A or B, A xor B, with `CF` = 0. `ONE` replaces B by 0001 first. `ZF`
is 1 when the result is zero. When `EO` is 1 the result is pulled onto the bus
(active-low, open-drain). The logic functions fall out of the adder: the NAND
that makes the generate term is NOT(A and B), the propagate XOR is A xor B, and
A or B is one more NAND of those two.

## Files

- `alu.kicad_sch` — the board, generated by `sim/build_alu.py` from `sim/alu.py`. Do not hand-edit; change `alu.py` and regenerate.
- `alu-testbench.kicad_sch` — stimulus sources, 5 V supply and hub pull-ups so the KiCad simulator runs out of the box. Excluded from the board and BOM.
- `sim_results/` — proof, produced from the kicad-cli export of this exact schematic:
  - `tran_alu_demo.png` — 13 operations, every input and output.
  - `tran_alu_zoom.png` — the carry rippling through all four bits, and 7 − 5.
  - `kicad_exhaustive_{TYP,LO,HI,MIX1}.json` — all 2304 cases at typical, 0.8 V, 3.0 V and mixed threshold corners.
  - `alu_kicad.cir` — the exported netlist that was simulated.

## Verification (2026-09-10, design v2)

| Netlist | Cases | Corner | Result | Worst settle |
|---|---|---|---|---|
| kicad-cli export | 2304 | typical Vth 2.0 V | 2304 / 2304 | 54 µs |
| kicad-cli export | 2304 | Vth 0.8 V | 2304 / 2304 | 28 µs |
| kicad-cli export | 2304 | Vth 3.0 V | 2304 / 2304 | 89 µs |
| kicad-cli export | 2304 | MIX (random threshold per transistor, seed 1) | 2304 / 2304 | 67 µs |

The 2304 cases are every A, B, SUB and function (2048) plus every A with ONE
for both SUB values and all four functions with B = 0 and 15 (256). ERC: 0
violations. Logic levels: high 5.00 V, low under 1 mV on every output.
`sim_results/kicad_exhaustive_*.json` hold the runs; `alu_kicad.cir` is the
netlist that was simulated.

Reproduce from `sim/`:

```
python3 build_alu.py
kicad-cli sch export netlist --format spice -o out/alu_kicad.cir ../boards/01-alu/alu.kicad_sch
python3 tb_alu.py out/alu_kicad.cir out --cases exhaustive --corner HI
python3 tb_alu.py out/alu_kicad.cir out --cases exhaustive --corner MIX --seed 1
python3 tb_alu.py out/alu_kicad.cir out --cases demo && python3 plots_alu.py out/kicad_demo_TYP.dat ../boards/01-alu/sim_results
```

## Not yet done

- PCB re-route for the v2 schematic (the routed `alu.kicad_pcb` in this
  commit is the 137-transistor v1 board).

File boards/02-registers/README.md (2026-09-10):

# Board 02: registers

The three 4-bit registers on the bus: A and B (the ALU's operands) and OUT
(the display). 366 transistors, 198 resistors, 12 LEDs.

| | |
|---|---|
| Bus signals used | in: BUS0#..BUS3#, CLK, AI, AO, BI, BO, BA, AB, OI. out: A0..A3, B0..B3 (register contents, for the ALU and the panel) |
| Bus driven | BUS0#..BUS3# open-drain when AO (A) or BO (B) |

Every register is four master-slave D flip-flops. A two-phase non-overlapping
clock derived from CLK (D033) makes the masters transparent while CLK is low
and copies them to the slaves on the rising edge. In front of each bit an
AND-OR mux chooses what the flip-flop captures:

- A takes the bus when AI, B when AB, otherwise holds.
- B takes the bus when BI, A when BA, otherwise holds.
- OUT takes the bus when OI, otherwise holds.

AB and BA together exchange A and B in one clock (XCH): both masters capture
the old values before the edge, both slaves change after it. A, B and OUT are
not on the reset line; they power up in whatever state the latches fall into,
and programs must write a register before reading it.

## Files

- `registers.kicad_sch`: the board, generated by `sim/build_registers.py` from `sim/registers.py`. Do not hand-edit.
- `registers-testbench.kicad_sch`: clock, control stimulus, diode bus drivers, 5 V supply and hub pull-ups so the KiCad simulator runs out of the box. Excluded from the board and BOM.
- `registers.kicad_pcb`, `fab/`: layout by `sim/pcb.py`.

## Verification (2026-09-10)

Schematic gate: `sim/tb_registers.py` runs a 113-step clocked script on the
kicad-cli export: every value through A and B from the bus, A and B driven back
onto the bus, MOV, XCH, OUT, and holds while the bus changes.

| Netlist | Corner | Result |
|---|---|---|
| kicad-cli export | TYP, LO, HI | 113 / 113 each |
| gate list | MIX seeds 1, 2, 3 | 113 / 113 each |

Machine gate: `fib.asm` on ALU + hub + registers, 127 ticks, 0 mismatches at
TYP, LO, HI and MIX (see `sim/gate.py` output in the commit that added this board).

Reproduce from `sim/`:

```
python3 build_registers.py
kicad-cli sch export netlist --format spice -o out/reg/registers_kicad.cir ../boards/02-registers/registers.kicad_sch
python3 tb_registers.py out/reg/registers_kicad.cir out/reg --corner HI
python3 machine.py programs/fib.asm --boards alu,hub,reg --corner MIX --seed 2
```

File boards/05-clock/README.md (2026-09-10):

# Board 05: clock

The clock, the speed knob, the RUN/STEP switch, the halt gate and the
power-on reset. 14 transistors in cells plus the two of the Schmitt trigger,
one pot, one DIP switch, one jumper.

| | |
|---|---|
| Bus signals used | in: HLT. out: CLK, RST |

- **Oscillator**: a source-coupled Schmitt trigger (Q1 and Q2 share a 1k
  source resistor; Q2's 10k load and Q1's 47k load put the source at 0.45 V
  and 0.1 V) reads the RC node X and trips at Vth + 0.55 V going up, Vth +
  0.15 V going down. Both trip points move with the same transistor's
  threshold, so the hysteresis survives any threshold spread. Its output is
  Q2's drain, inverted by SA (4.7k pull-up), which charges X through 100k plus
  the 1M pot. 47 nF on X gives roughly 500 Hz down to 40 Hz; the SLOW jumper
  adds 2.2 uF for 10 Hz down to 0.8 Hz.
- **RUN**: the switch puts +5 V through a diode and 10k onto CLK, and the
  oscillator's transistor pulls CLK low for half of each cycle. **STEP**: the
  switch is open, the transistor is held off, and the panel's CLK button owns
  the line. The diode keeps the 10k from loading the button in STEP.
- **HLT** high holds CLK low.
- **Power-on reset**: 2.2 uF charging through 100k into a Schmitt trigger
  holds RST high for about a tenth of a second after power-up.

Three oscillators failed in simulation before this one (D036): two plain
inverters with an RC settle at a stable operating point; a MOSFET astable
falls into its both-on state; and reading the Schmitt trigger at the wrong
node let the outer loop settle half way. The mixed-threshold corner found
every one of them.

Generated by `sim/build_clock.py` from `sim/clock.py`; `sim/tb_clock.py`
measures period, duty, halt, step and the reset pulse at every corner.

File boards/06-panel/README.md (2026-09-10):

# Board 06: front panel

The test fixture and the face of the machine. 80 transistors, 56 LEDs, 72 resistors.

- **Level switches** (four DIP-8): A3..A0, B3..B0, and the 24 control lines. A closed switch connects the line to +5 V through 10k, so a switch left on can never fight a board that pulls the line low; it only supplies a 1 where nothing else drives.
- **Data switches** (DIP-4): the input port. A closed switch is a 1; while `INP` is high the four bits are driven onto the bus through the usual NAND and open-drain transistor, which is how the IN instruction reads them. To force the bus by hand, close the INP switch too.
- **CLK and RST buttons**: RC debounce, an NMOS Schmitt trigger (two inverters, 1 Meg feedback), 10k and a diode onto the line. One press = one clean edge at every threshold corner (simulated with contact bounce). The clock board can drive the same lines later.
- **1 Meg pull-down** on every switched or observed line, so a line reads 0 when no board drives it.
- **An LED on every line**: 52 bus lines directly, plus the four data bits through inverters so the LED shows the data, not the active-low wire.

First test with hub + panel + ALU: set A, B, SUB, EO on the switches; read the result on the data LEDs and CF/ZF.
Generated by `sim/build_panel.py`. ERC clean; export simulated (`sim/out/panel_sim.cir`).

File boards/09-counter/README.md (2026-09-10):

# Board 09: counter

The 8-bit program counter and the 8-bit return register. 416 transistors, 221
resistors, 16 LEDs. Split off the sequencer for board size (D035).

| | |
|---|---|
| Bus signals used | in: PCE, PCL, CLK, RST. out: PC0..PC7 |
| Link header (2x6) | from board 03: OPR0..OPR7 (jump target), PCR (load the return address), RAI (save the return address) |

- **PC**: eight master-slave flip-flops with asynchronous reset. Each bit's
  input is PC xor carry (count when `PCE`, hold otherwise), OPR when `PCL`
  (JMP, JC, JZ, CALL) or RA when `PCR` (RET). The count carry ripples through
  seven AND gates.
- **RA**: eight transparent latches open while `RAI` and PH1. CALL asserts
  `RAI` and `PCL` in the same tick: RA captures the old PC during the low half
  of the clock, PC loads the target on the rising edge that follows.

Generated by `sim/build_counter.py` from `sim/counter.py`; verified with the
machine gate together with board 03 (see its README).

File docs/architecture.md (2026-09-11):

# Architecture

Nibble is a 4-bit accumulator machine. It runs one loop forever: read the
instruction at the address held in the program counter, decode it, execute it,
add one to the program counter. Jumps overwrite the program counter instead.

## Parts, and the board each one becomes

| Part | What it does | Board |
|---|---|---|
| ALU | Adds or subtracts A and B in two's complement, or ands, ors, xors them; can use 1 in place of B. Produces a 4-bit result, a carry flag and a zero flag. | `01-alu` |
| Registers A, B, OUT | A is the accumulator: every result lands here. B is the second operand and can drive the bus (BO) so it can serve as a memory pointer. OUT drives the display LEDs. | `02-registers` |
| Program counter, return register | 8-bit counter, loaded from the operand register for jumps and calls, or from the 8-bit return register for RET. Takes the operand and its load lines from the sequencer over a 12-pin link cable (D035). | `09-counter` |
| Instruction register, operand register, control | Holds the current instruction and its 8-bit operand; a five-state step counter, two decoders (opcode, and the operand nibble for the 0000 family) and a diode matrix (45 rows: every instruction's first execute step, the second step of the four memory accesses and of the six free opcodes, the four conditional jumps) turn them into control-line pulses. New instructions are diodes. | `03-sequencer` |
| Program memory | 16 words of 8 bits per board as DIP switches with a diode per bit, selected by PC0..3; PC4..7 select the board (page jumpers). Build more copies for longer programs. | `04-program` |
| Data memory | 16 slots of 4 bits with its own address register (MAI) and MI/MO lines, addressed by an instruction operand or by B. Gives programs variables, lists and tables. | `08-memory` |
| Clock and reset | Schmitt-trigger RC oscillator with a speed pot, RUN/STEP switch, halt gate, power-on reset; single-step comes from the panel button. | `05-clock` |
| Front panel | Switches to force A, B and control lines by hand; LEDs on every bus line; the data switches double as the machine's input port (IN). Test fixture for every other board. | `06-panel` |
| Bus hub | Pull-ups for the bus, pull-downs for the M lines, power distribution, one 64-way header per board. | `07-hub` |

Boards connect to the hub with ribbon cables and sit in a rack. The hub is the
only place the bus pull-ups live, so a board can be unplugged without changing
the logic levels anywhere else.

## The bus

Four data lines, active-low, open-drain. Any board pulls a line low to put a
`1` on it; a resistor on the hub pulls it back to 5 V. Several sources may sit
on the bus at once because only the enabled one pulls. Sources: A (`AO`), B
(`BO`), the ALU result (`EO`), the instruction operand (`IO`), data memory
(`MO`), the panel switches (`INP`). Sinks: A (`AI`), B (`BI`), OUT (`OI`), the data memory address register
(`MAI`), data memory (`MI`), writable program memory (`WRL`, `WRH`). The
program counter loads from the operand register directly, not from the bus.

A and B also cross the header as plain 4-bit values, because the ALU reads them
continuously, and because `XCH` needs both registers to read each other in the
same clock without going through the bus.

## Levels and speed

Logic 0 is below 0.5 V, logic 1 is above 4 V, supply is 5 V. A gate output
rises through its pull-up resistor and falls through its transistor, so rising
edges are slow (microseconds) and falling edges are fast. The clock is expected
to run up to a few hundred hertz and be watched at a few hertz. The gate coupon
board measures the real numbers before anything else is ordered.

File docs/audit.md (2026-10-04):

# Audit of every board (2026-09-28)

Until this date the order gate had run on the three pilot cards only. This
is the record of running every check on all 26 designs (25 cards and the
sequencer), what each check can and cannot see, what was found, and what is
still open. Nothing here has been built: every line is a check on files.

Commit checked: `5b2a0bd`. Since then the bus headers went to the back of
every board and the silkscreen was refitted (no track moved: `sim/board_diff.py`);
the findings' states below are as of that change.

## 1. What was run, on what

| Check | How | Boards | Result |
|---|---|---|---|
| The order gate, eleven checks per board (clean, rules, erc, drc, jlc, fab, zip, outline, pins, asm, clamp) | `python3 sim/order_check.py <26 names>`, log `sim/out/gate_all.log` | all 26 | 286 of 286 pass |
| What joins the boards: bus pins and link pins | `python3 sim/order_check.py --machine` | all 26 | 27 bus headers, 19 links: all pass |
| The checks themselves, against faults planted on purpose | `python3 sim/order_check.py --selftest` | | 17 of 17 part cases, 5 of 5 planted bus and link faults caught |
| Every DRC warning read | kicad-cli, by hand | the 5 boards that have any | section 3 |
| Every assembly drawing looked at | rendered with Chrome, one by one | all 26 | section 2, F2 |
| Other parts' leads under the bus header's body | script over the pads inside each header's courtyard | all 26 (27 headers) | none |
| Every footprint has a courtyard, and courtyard overlap is an error | project files and boards | all 26 | yes; 0 overlaps |
| Hole against lead, per footprint | section 4 | all 22 footprint types | fits on paper; three parts must be the exact family |
| Silkscreen text sizes | script | all 26 | 364 labels under 1.0 mm (F4); 2 after the refit |

## 1a. The header move and the machine gate (2026-09-29)

The machine gate simulated the boards as they were before the headers went
to the back. Two comparisons say its results stand for the boards as they
are now:

- every board's SPICE export is the same, element for element
  (`sim/board_diff.py 992a90f <26 boards>`: "no copper moved", and the
  netlist column);
- the whole-machine deck (fib, all cards, the clock card) written from the
  old tree and from the new one has the same 4957 elements on the same
  nets. The 54 cable capacitors are numbered in another order, one on each
  bus line as before.

One stage does not carry over: the crosstalk stage (`CROSS_PF=100`,
`sim/results/gate25_cross.md`) coupled the lines that were neighbours on
the ribbon then. The neighbours are other lines now (RST and BUS1#, BUS1#
and BUS0#, BUS0# and BUS3#, ...), so that stage is owed again on the new
order: six programs at TYP and HI. Paid 2026-09-30: `sim/results/gate26_cross.md`,
12 of 12 pass (with the clock card's hold-off, D064, in the deck; the card
with it on carries the same deck). The hold-off itself then went through the
whole gate again (gate 26, 2026-09-30 to 10-04): smoke, all programs at TYP,
the corners, nop, 500 pF at HI, 4.5 V, 4.25 V, MIX seeds 3 and 4, then 800 pF
at HI for the panel's ribbon; 91 of 91 pass, `sim/results/gate26_*.md`.

## 2. Findings

| # | Finding | Where | State |
|---|---|---|---|
| F1 | The gate's `pins` rule called four correct timing capacitors reversed and a potentiometer's mounting lugs unconnected | clock, panel B | Fixed in the rule (`5b2a0bd`); the rule now has a self-test |
| F2 | The assembly drawings hid what they were for on the cards with arrays: 32 diode labels covered the 32 diodes of a program card, the panels' switch names ran across the resistors beside them | prog, panel A, B, C, clock | Fixed (`5b2a0bd`), all 26 redrawn and looked at |
| F3 | The sequencer had never been through the gate, had no assembly drawing and no zip; its README gave the part counts of an older board | sequencer | Gate extended: passes. Drawing shows which 87 of the 1035 matrix crossings take a diode. README corrected |
| F4 | 364 silkscreen labels are 0.8 or 0.9 mm high; JLCPCB states 1.0 mm. 8 labels are clipped by a pad's mask opening | every board; the 8: panel B `INP`, panel C `PC0`, sequencer `OPR0 OPR1 OPR3 OPR5 OPR6 ZFQ` | Closed with the headers' move: `pcb.fit_silk` grows every label to 1.0 mm where it has room and moves it off pads, vias, outlines and out from under parts; none is clipped. Two labels stayed 0.8 mm at first (`WRH` on panel B, `RUN` on the clock): the fitter tried a label's own small size lying down before it tried 1.0 mm standing upright. It now tries every place at 1.0 mm first, and both stand upright beside their LEDs at 1.0 mm: no label on any board is under 1.0 mm. The sequencer's row names stand upright over their rows. The gate's `silk` check holds it; `sim/silk_proof.py` plots the print for the eyes |
| F5 | Nothing checked that the bus header of every board has every signal on the same pin. The simulation joins the cards by net name, so a header wired to the wrong pin passes every deck | all | Closed: `--machine` compares every pad of all 27 headers with `sim/bus.py`. They agree |
| F6 | The link ribbons between neighbours have the fault the bus ribbon had: the headers lie along the bottom edge, so a ribbon leaves them up or down, never sideways to the neighbour | ALU, counter, memory cards, sequencer (30 link headers) | Open, section 5. No board changes; it is a matter of where the cards stand and how each ribbon is folded |
| F7 | A ribbon that goes down one column and up the next arrives mirrored (pin 1 where pin 64 should be) unless it is folded an odd number of times on the way. Pins 1 and 64 are +5V and GND | the bus ribbon behind the cards (D059) | Open, section 5: goes into the mounting document with a continuity test before first power |
| F8 | The schematic calls the level switches "switch up = 1". The switches lie on their side: the sliders move left and right. The boards print nothing about it | panel A, B, C, prog, clock | Closed: the boards print `ON >` at every switch, the assembly drawings and `bring-up.md` say closed (ON, to the right) is 1 |
| F9 | The sequencer's bus header is 12.5 mm left of the header line of the card column below it (the board is centred on the face) | mounting | Open, section 5: the rails are slotted, the board can stand 12.5 mm to the right |

## 3. The DRC warnings, all of them

| Board | Warnings | What they are |
|---|---|---|
| prog | 28 | The printed circles of upright diodes 2.54 mm apart touch each other. Print only |
| panel B, panel C | 1 each | A name clipped by a pad (F4) |
| coupon | 1 | The known 0.5 mm stub at the end of the +5V trunk |
| sequencer | 132 | 59 fixed stubs the router did not need, by design; 67 printed circles and outlines touching; 6 names clipped (F4) |
| the other 21 | 0 | |

## 4. Does the part fit the hole

From the boards' drill sizes and the parts' usual drawings. "Usual" is not
"measured": the coupon is the card that finds out, which is why it is
ordered first. The counts are the whole machine's: 52 boards, 7129 parts.

| Part | Footprint: hole, pitch | The part must be | Risk |
|---|---|---|---|
| 2N7000 (3516) | 0.8 mm, three holes 2.54 mm apart | TO-92; leads 0.4 to 0.55 mm | A straight TO-92 has its leads 1.27 mm apart: every one is spread by hand, or bought with formed leads. Which order code is formed to 2.54 mm has not been read from a datasheet yet |
| Resistor, upright (2138) | 0.8 mm, 5.08 mm | 1/4 W axial, body to 6.3 x 2.5 mm, lead 0.6 mm | none |
| 1N4148, upright (727) | 0.8 mm, 2.54 mm | DO-35 glass, body under 2 mm across | At 2.54 mm between neighbours two 1.85 mm bodies leave 0.7 mm |
| LED (281) | 0.9 mm, 2.54 mm | 3 mm round | none |
| Electrolytic (56) | 0.8 mm, 2.0 mm | 5 mm can. 10 uF, 2.2 uF, 1 uF, and 100 uF 16 V on the hub | A 100 uF 25 V can is 6.3 mm: buy 16 V |
| Ceramic capacitor (56) | 0.8 mm, 2.5 mm | 2.5 mm lead pitch, not 5 mm | none |
| Box header 2x32 (53), 2x6 (18), 2x3 (20) | 1.0 mm | 0.64 mm square pins | none |
| Pin header 1x3 (144), 1x2 (2), 1x6 (1) | 1.0 mm | 0.64 mm square pins, a jumper cap on each 1x3 and on the clock's 1x2 | none |
| DIP switch 8-way (84), 4-way (1), 1-way (1) | 0.8 mm, 7.62 mm rows | the common slide type, 9.8 mm wide | none |
| Push button (2) | 1.1 mm, 6.5 x 4.5 mm | 6 mm tactile switch; fits two ways round, both right | none |
| Potentiometer (1) | 1.0 mm pins 2.5 mm apart, two 2.2 mm leg holes 8.8 mm apart, 7.0 mm from the pins | Bourns PTV09A-4, 9 mm, 1 M linear (`lib/nibble.pretty`, from the maker's layout) | Another maker's 9 mm pot only after its drawing has been laid on these numbers; the Alpha RD901F-40 the card was first drawn for has slotted lugs 9.6 mm apart and does not fit |
| Polyfuse (1) | 1.0 mm, 10.2 mm with a 1.9 mm offset | Bel 0ZRE0150FF | The offset is this family's kinked leads |
| Test loop (21) | 1.0 mm | the miniature size | The larger sizes want 1.6 mm |
| Banana socket (2) | four 1.6 mm holes on a 4.76 mm diamond | Cal Test CT3151V1 (D063); footprint drawn from the maker's drawing, `lib/nibble.pretty` | It stands on four solder joints without the panel its drawing has in front of it |
| Crowbar: SCR, zener, 3 A diode (1 each) | TO-220 1.1 mm holes; DO-41 1.1 mm, 10.16 mm; DO-201AD 1.6 mm, 15.24 mm | BT151-500R (pin 1 cathode, 2 anode, 3 gate: read in its datasheet), 1N4735A, 1N5408 | none |

## 5. Open: how the ribbons run

(2026-10-01: settled in `docs/mounting.md` and drawn in `docs/mounting/panel.html`,
D065: the two-sided panel, the slot plan, the routes and lengths of every
ribbon. The 800 pF run is paid, 2026-10-04 (`sim/results/gate26_800pF_HI.md`,
6 of 6). Open: the standoff length, measured on the pilot.
The points below are kept as the reasoning.)

An IDC socket lies across its ribbon. Every header on every board lies
along a top or bottom edge, so every ribbon leaves its header upward or
downward. D059 settled the bus ribbon (headers on the back, the ribbon down
each column behind the cards). What follows from that and is not yet
written into `mounting.md` or drawn in the model:

1. **Turning the bus ribbon.** The ribbon goes down one column and must come
   up the next. Two 45 degree folds turn it round and leave it mirrored:
   pin 1 of the sockets would meet pin 64 of the headers. A third fold (the
   ribbon doubled back on itself once) puts it right. The same rule holds
   for every turn: a ribbon that reverses direction needs an odd number of
   folds. Before first power every socket is tested for continuity from its
   pin 1 to the hub's pin 1.
2. **Link ribbons, 6-way (ALU and counter chains).** `OUT` is at x = 80 and
   `IN` at x = 14 on the bottom edge; between two cards side by side they
   are 44 mm apart. The ribbon leaves `OUT` downward into the 10 mm gap
   under the row, folds toward the neighbour, folds down, and doubles back
   up into `IN`: three folds, 6-way ribbon, about 80 mm.
3. **Link ribbons, 12-way, chained (sequencer to eight counter cards, memory
   control to eight slots).** Every card has the header at the same place
   (x = 40, bottom edge), so the ribbon that needs no folds runs straight
   down a column of cards, over their fronts, 15 mm wide, across the
   transistors between x = 32 and 48 (no LED stands there). Along a row it
   needs four folds per card. This decides where the counter and memory
   cards stand: in columns, not in rows as `mounting.md` has them.
4. **The sequencer** stands 12.5 mm to the right of centre so that its bus
   header is in line with the column under it. Its link header is on its
   top edge, the counter cards are below it: that ribbon goes over the top
   of the board and down behind it, or the counter cards' chain starts at
   the far end.
5. **Behind the card.** A box header is 9 mm high and the socket on it
   reaches about 15 mm; the rail is 12 mm behind the card, 40 mm below the
   header. The ribbon leaves the socket 13 mm behind the card and has to
   come forward to pass between card and rail. On the sequencer the top
   rail's edge is 0.6 mm from the socket's. Both want drawing to scale
   before the frame is bought.

## 6. What no file can show

| Risk | Why it is open | What settles it |
|---|---|---|
| A part that does not match its usual drawing | section 4 is from drawings | the coupon and register card of the pilot, built |
| Supply drop and ground offset along 7 m of ribbon (about 0.2 to 0.4 V at the far card with every LED lit) | the decks pass at 4.5 and 4.25 V on every card alike; they have never run with the ribbon's resistance between the cards | a deck with the ribbon's resistance in its supply lines; queued behind the reset sweep |
| Pushing a 64-way socket onto a card held by two screws on its mid-line (60 to 100 N) | mechanical | a hand behind the card; goes into `bring-up.md` |
| Static on the bus lines, which go straight to gates | no protection on any card | handling; goes into `bring-up.md` |
| Over-voltage and reversed leads at the bench supply | the crowbar is decided (D061), not built | the hub, with a test bench that chooses its values |

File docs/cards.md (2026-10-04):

# Cards: the machine as 100 x 100 mm boards on one ribbon

Decided 2026-09-10 evening (D042 to D045) after the first fab quotes: nine
boards of nine sizes came to about $1,300 for a machine we need one of. This
page is the plan that replaces the board list in `plan.md` step 1 to 7; the
three gates in `plan.md` still apply to every card.

## Why

JLCPCB (and every cheap fab) sells five of a design, and prices a board over
100 x 100 mm at three to six times more per square metre than the promo tier
under it ($2 to $4 for five). Cutting the boards along the bit and slot
structure the gate lists already have does two things at once: every card
lands on the cheap tier, and five-of stops being waste because a five-pack
is the four register bits plus a spare.

| | Nine boards (quoted) | Cards (estimated) |
|---|---|---|
| Boards | ~$700 for five of each | 12 designs on the promo tier plus the sequencer: $60 to $80 |
| Shipping | ~$300 in separate boxes | one package, $40 to $60 |
| Parts, cables, frame | ~$315 | ~$315 |
| **Machine** | **~$1,300** | **$400 to $450** |

## The cards

100 x 100 x 1.6 mm, 2-layer, one 2 x 32 shrouded header along the top edge,
soldered on the back of the card (D059, D062: the ribbon runs behind the cards)
(the header is 91 mm long, so the two M3 holes sit mid-height on the left and
right edges). LEDs on the front. Below the header and its two power trunks
there is room for 11 tile columns of 82 mm (`sim/frame.py`, `ksch.DenseWriter`).

The dense tile (D045): a column is 7.68 mm wide and holds one TO-92 per 5.08 mm
row; the pull-up lies along the row above its stack, one pad on the source
column and one on the drain column. A gate of n transistors is 3.175 + 5.08 n
mm tall (8.3, 13.3, 18.4 mm for one, two, three), an LED cell 15.2 mm. The
power rails run on the back between the columns, alternately GND and +5V, each
shared by the two columns beside it (odd columns are mirrored so their sources
face the GND rail). The register bit card, 99 transistors and 54 pull-ups,
fills 10.3 of the 11 columns: about 66 mm2 per transistor all in, and
freerouting closes it in one pass with DRC zero.

| Card | Count | Designs | Transistors | Neighbour link | Notes |
|---|---|---|---|---|---|
| Register bit i: A, B, OUT flip-flops and muxes for one bit | 4 | 4 (bit baked in) | 99 (89 for the bit, 10 for the card's clock phases and hold decoders) | none | LEDs A, B, OUT |
| ALU bit i | 4 | 4 | 66 to 73 (bit 3 adds CF and ZF) | carry and zero-so-far to bit i+1 (2 x 3) | bit 3 carries CF and ZF to the bus |
| Counter bit i: PC bit and RA bit | 8 | 8 | 62 (59 for bit 7, no carry out) | count carry to bit i+1 (2 x 3); OPR i from the sequencer's link ribbon (2 x 6, chained) | |
| Memory control: MAR, write gate, PH1 | 1 | 1 | 59 | MAR0..3 and WR/RD to the slot cards (2 x 6, chained) | |
| Memory slots: two 4-bit slots with their decode | 8 | 1, slot pair by jumper | 91 | from memory control | 8 cell LEDs |
| Program: four words, page and word-group jumpers | one per four words | 1 | 41 + 32 diodes | none | 4 DIP-8, six 1x3 jumpers (PC7..2); `list` takes 6 cards, `sort` 20 |
| Panel | 3 | 3 | 28 + 20 + 32 | none | A: A/B and SUB..AB switches, their LEDs, data, CF, ZF, CLK, RST LEDs. B: OI..INP switches and LEDs, CLK and RST buttons. C: PC and M LEDs, DATA switches and input port |
| Clock | 1 | 1 | 15 + the Schmitt pair | none | the clock board's circuit on a card; HLT delayed 0.22 ms into the halt gate (D050); the hold-off keeps the clock still while RST is high (D064) |
| Hub: two 4 mm banana sockets for the bench supply (D063; no USB, D057), 1.5 A polyfuse (D052), crowbar and reverse diode (D061), bus pull-ups, M pull-downs (220k, D048), test loops | 1 | 1 | 0 | none | two bus headers, top and bottom edge, one per face's ribbon; ground wired as a ring and bars, no pour |
| Coupon | 1 | 1 | 26 | | powered from the bus header; inputs on a 1x4 header, test loops |
| **Sequencer** | 1 | 1 | 592 + 87 diodes | link ribbon out to the counter cards | **the one big board, 245 x 255 mm, four layers (D051)** |

Why the bit cards are separate designs rather than one design with jumpers:
a bit is three lines (BUSi#, Ai, Bi), so selecting it is three 1 x 4 jumper
headers on a full card, and two cards jumpered alike fight over a bus line.
Four designs cost $6 more. Jumpers stay where the builder configures anyway:
memory slot pairs and program pages.

## The ribbon (D043)

One 64-way ribbon per column face, IDC sockets crimped along it every 110 mm,
one per card, all facing the same way, folded twice at each row end to run
back along the next row. Four cards per 460 mm row, seven rows per face. The
hub card joins the faces. About 6 m of ribbon and 45 sockets for the machine,
crimped in a bench vice. Pin 1 is the ribbon's red edge on every socket.

The links between neighbours (ALU carry, counter carry, memory address, the
sequencer's operand lines) are 6 cm pieces of 6-way or 12-way ribbon with
their own small IDC sockets, the same idiom as today's sequencer-counter link.

The machine deck carries 300 pF per bus line; rerun at 500 pF for margin
before the order (done, step 9: 8 of 8).

## The sequencer (D040, D041, D044, D045)

Stays one board because 45 rows and 23 columns would otherwise cross card
boundaries. Diodes standing up on a 2.54 x 5.08 mm grid make the matrix
114 x 117 mm with a pad pair at every crossing; the 600 transistors of steps,
registers, decoders, rows and column buffers around it at the card pitch on four layers (D051: on two layers the router
plateaued near 100 open nets at the card pitch and near 70 at a 10.16 mm pitch; layer 2 is a ground plane, layer 3 a
third routing layer). Two new gated rows for JNZ and JNC. 245 x 255 mm, about $65 for five.

## Order of work

Each step is a commit or a few; each card passes the three gates of
`plan.md` (ERC and exhaustive or scripted sim of the export at TYP/LO/HI/MIX;
routed with DRC zero; machine gate with the emulator) before the next.

1. **Card frame and dense tile.** Done: `frame.card_frame` (100 x 100 outline, header at the top, holes mid-side, decoupling), `ksch.DenseWriter` (the tile above), `build_reg_card.py`. Proved on `cards/reg0`: 99 transistors, routed DRC-clean in one freerouting pass, ERC clean. The rule stands for every later card: if one does not close, it is the tile pitch that moves, not the card size (a 100 x 150 card is $11.20 instead of $2).
2. **Register bit cards** (4). Done: `cards/reg0..3`, routed DRC-clean; `tb_registers.py cards` 113/113 at TYP, LO, HI, MIX 1..3 on the exports; machine gate with the four cards, all twelve programs at TYP.
3. **ISA: JNZ, JNC.** Done: `isa.md`, `emu.py` (the assembler follows it), `sequencer.py` (two more flag-gated rows, 45 rows and 87 diodes), `programs/loops.asm`; `test_emu.py` passes all twelve programs.
4. **Sequencer at the new pitch**: vertical diodes in `ksch.matrix`, dense tiles, JNZ/JNC rows (done: `boards/03-sequencer`, 245 x 255 on four layers at the card pitch, D051, ERC clean, the matrix hidden from the router), routed 2026-09-14 with freerouting 2.4.1 on the ninth attempt (0 unconnected, 0 DRC errors; the route rules are in D051's amendment and the board README), machine gate on its export: 24 of 24 corner runs and the TYP programs pass. Open item to close first: `sim/out/d041_list_MIX3.log`, list.asm at MIX seed 3 on the buffered sequencer, must show 0 mismatches. Closed 2026-09-11: 210 ticks, 0 mismatches (two earlier runs stalled in ngspice at tick 82 with "timestep too small"; the third retry option, gmin and more transient iterations, got through).
5. **ALU bit cards** (4) with the carry and zero chain. Done: `cards/alu0..3` routed DRC-clean; `tb_alu.py cards` exhaustive 2304/2304 at TYP, LO, HI on the exports (MIX running); machine gate with step 9.
6. **Counter bit cards** (8) with the count carry and the chained link ribbon. Built: `cards/ctr0..7` routed DRC-clean; call.asm on the gate lists 0 mismatches; the exports are proven by the step 9 gate.
7. **Memory control and slot cards** (1 + 8). Built: `cards/memctl`, `cards/memslot` routed DRC-clean; `tb_memory.py cards@dev` 217/217 (the slot jumpers make MAR1..3 ports of the slot subcircuit; left inside they floated and every read came from pair 7); the exports at four corners run in step 9's queue. Rebuilt 2026-09-23 (D054): the address latch and the write windows come from a mid-tick pulse (CLK through 100k into 2.2 nF, MPH = NOR(CLK, NOT CLKD)) instead of PH1, after gcd, list and logic at mixed seed 2 with the clock card in the deck wrote to the wrong slot (the sequencer stepped and the data reached the bus before this card had seen the 35 us edge, and the address latch took the data as the address); routed again DRC-clean, `tb_memory.py --race` (a 35 us CLK ramp, bus and controls switching 10 us into it) on the gate list and on the card export, see `cards/README.md`.
8. **Program cards** (one per four words), **panel cards** (3), **clock**, **hub**, **coupon** as cards. Built 2026-09-11: `cards/prog` (six jumpers PC7..2; fib on the gate lists 0 mismatches), `cards/clock`, `cards/hub` (two headers, the 64 lines pre-routed), `cards/panela..c` (a tile column is a panel column, so the LEDs read row by row), `cards/coupon`; all ERC clean and placement DRC clean, routes in progress. 2026-09-23 (D053): the clock card drives CLK through 1k and RST from a new 1k stage, and the panel's CLK and RST pull-downs are 10k with the buttons driven from 1k pull-ups (value changes on `panela`, `panelb`; the clock card re-routed with the extra inverter): CLK rises in 6 us instead of 35, RST releases in 45 us instead of 8 ms, `tb_clock` measures and requires both. 2026-09-28 (D056): the coupon respun before the pilot order with every cell on it (the oscillator, a flip-flop with reset, the D053 driver, a threshold fixture, a program row; 57 transistors, 15 loops, a bench-supply header), routed DRC clean; `sim/tb_coupon.py` on its export at TYP, LO, HI and MIX 1..3 writes the bands the bench must land in, `sim/results/coupon_expected.md`.
9. **Machine deck** instantiating cards with their links; the machine gate over all thirteen programs at TYP, then LO/HI/MIX on fib, alu, gcd, list, logic, call, with the clock card driving the machine; 500 pF rerun. **Closed 2026-09-26** on the whole card deck as it will be built (`aluc,hubc,regc,seq,ctrc,memc,progc,pnl,clkc`: the D053 clock card runs the clock and the reset, the D054 memory control card, the panel's switches worked by the machine's own IN instructions, every deck a power-up from 0 V, `.tran ... uic`, with the card's own power-on reset and no testbench reset or clock): the first 12 ticks of all thirteen programs at TYP (`sim/results/gate25_smoke_t12.md`); all thirteen programs to their halt at TYP, 0 mismatches (fib 127 ticks, calc 616, lfsr 1497, sort 974, logic 986, count 444, mul 314; `sim/results/gate25_TYP.md`); fib, alu, gcd, list, logic, call at LO, HI, MIX seed 1 and MIX seed 2: 24 of 24, 0 mismatches (`sim/results/gate25_corners.md`). Two earlier closings stand behind it. 2026-09-14, the testbench driving CLK and RST (`sim/out/gate_cards_TYP.log`, `gate_cards_corners.log`): twelve programs at TYP and the same 24 corners, 0 mismatches; 500 pF per bus line on fib, list, logic, calc at TYP and LO: 8 of 8 (`sim/out/gate_cards_500pF.log`; logic at LO aborted three times in ngspice with "timestep too small" inside an ALU transistor and passed on a fourth solver rung: a solver artefact, the circuit is the same one that passes at 300 pF); on the way this gate found D048 and D050 (calc ended one count short) and the lfsr reset bug in the testbench. Then the first clock card in the deck, 2026-09-21/23: all thirteen at TYP passed, but the corner gate failed gcd, list and logic at MIX seed 2 (`sim/results/gate_clk_corners_oldclock.md`): the card's 35 us clock edge, read by every card with its own transistors, reached the sequencer up to 25 us before the memory card, whose PH1 address latch then took the next word's data as an address. That is D053 (the edge, 6 us) and D054 (the mid-tick memory pulse), steps 7 and 8, and the gate above is the rerun on the rebuilt cards. Rerun once more as gate 26, 2026-09-30 to 10-04, on the clock card with the hold-off (D064): the same eight stages on the whole card deck, 85 of 85, 0 mismatches (`sim/results/gate26_smoke.md`, `_TYP`, `_corners`, `_nop`, `_500pF_HI`, `_vdd45`, `_vdd425`, `_mix34`; the crosstalk stage `_cross`), then the panel's ribbon length as a ninth stage, 800 pF per bus line at HI, 2026-10-04: 6 of 6, 0 mismatches (`_800pF_HI`); 91 of 91. The harness grew on the way: the switch counter (XSPICE digital, one input per IN), the power-up start, the halt stop, a ledger so a killed gate resumes, per-process card exports (two decks built at once had read each other's half-written netlist).
10. **Mounting**: `mounting.md` and the model redrawn for the cards. Done 2026-09-14 as a 4 x 7 grid per face of the column (28 slots per face); redrawn 2026-10-01 as the two-sided panel (D065, `docs/mounting/panel.html`: five columns by seven rows a face, the sequencer bottom left of the front, the ribbons behind the cards, the chained links down the columns). The 800 pF run is paid (step 9, `sim/results/gate26_800pF_HI.md`, 2026-10-04). Open: the standoff length (the pilot).
11. **Docs and order**: `bring-up.md` per card, `order-1.md` with the quotes from the calculator, `bom.py` over the cards, renders; then the order. Status 2026-09-14: `bring-up.md`, `order-1.md` and the parts table from `bom.py` over the routed cards are written, every card's `fab/` holds its gerbers and renders, and the gate of step 9 is closed. 2026-09-26: step 9 closed again on the rebuilt clock and memory control cards (D053, D054). 2026-09-28: the added corners on that deck are green, 47 of 47 runs, 0 mismatches: nop at LO and HI (`sim/results/gate25_nop.md`); the six corner programs at HI with 500 pF on every bus line (`gate25_500pF_HI.md`), at TYP and HI with the supply at 4.5 V (`gate25_vdd45.md`), at TYP and HI with 100 pF between neighbouring bus lines (`gate25_cross.md`), at MIX seeds 3 and 4 (`gate25_mix34.md`); fib, logic and call at HI with the supply at 4.25 V (`gate25_vdd425.md`). The 4.25 V stage failed once on the harness, not the machine: the scorer read CLK against a fixed 3.5 V and the card's CLK high is (VDD − a diode) × 10/11, 3.38 V at 4.25 V; every scorer and bridge level is a fraction of VDD since 1480db7 and the stage was rerun. Nothing found in the hardware. 2026-09-28: the coupon respun (D056) and its expected readings written (`sim/results/coupon_expected.md`, `bring-up.md` section 1), the pilot parts table regenerated (320 parts). Left: the board quotes read from JLCPCB's calculator with the actual gerbers (a cart, not a commit), then the order, the coupon, `reg0` and the hub first.

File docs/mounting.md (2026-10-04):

# Mounting: the two-sided panel

Redrawn 2026-10-01 (D065), replacing the four-faced column of D038. The
column's size came from the nine boards of nine sizes; the cards (D042)
are all 100 x 100 mm and the sequencer is the one exception, so the
machine fits on the two faces of one flat panel of aluminium extrusion
standing on a table. It lives in a New York apartment: 58 cm wide, 82 cm
tall, 30 cm of feet front to back, and you walk round it.

`docs/mounting/panel.html` is the model: open it in a browser (it loads
three.js from a CDN), drag to walk round it, slide the program-card count
to see the back fill. `docs/mounting/panel.js` holds the slot plan, the
rails and the ribbons' routes; the page draws from it and `node panel.js`
prints the numbers quoted here, so the document and the model agree.

## The frame

2020 aluminium extrusion, the 3D-printer profile. Two 800 mm uprights
580 mm apart outside to outside, each standing on a 300 mm foot of the
same extrusion laid flat across the panel. Fourteen 580 mm rails lie
across the uprights' faces, seven on the front face and seven on the
back, one corner bracket at each end. Nothing is drilled: an M3 T-nut
slides into a rail's slot, a standoff screws into the T-nut, the card
screws onto the standoff. About 13 cm deep with both faces' cards on.

## The grid

Both faces are five columns of cards at a 110 mm pitch (100 mm card,
10 mm gap), 20 mm inside the uprights' outer edges: columns at 20, 130,
240, 350 and 460 mm from the panel's left edge, as the face is seen. A
card's two M3 holes are mid-height on its left and right edges
(`cards.md`), so one rail per row carries every card of that row.

The front has four rows at the pitch and then a band of three rows for
the sequencer: the sequencer (245 x 255, four corner holes, the upper
pair 20 mm below its top edge, the pairs 231 mm apart) stands on two
rails of its own, 231 mm apart, with its left edge on column 1 so that
its bus header is in line with column 1's ribbon; a third rail between
them carries a row of cards beside it. The back has seven rows at the
pitch. Rail heights, table top to rail centre:

| Row | Front | Back |
|---|---|---|
| 1 | 760 | 760 |
| 2 | 650 | 650 |
| 3 | 540 | 540 |
| 4 | 430 | 430 |
| 5 | 320 (the sequencer's upper rail) | 320 |
| 6 | 210 | 210 |
| 7 | 89 (the sequencer's lower rail) | 100 |

The lowest cards' bottom edges are 4 cm above the table.

## The slots

Front, as the front sees it, left to right; the chains of neighbours run
down the columns (see the links below):

| Row | Column 1 | 2 | 3 | 4 | 5 |
|---|---|---|---|---|---|
| 1 | ALU bit 0 | counter bit 0 | counter bit 7 | register bit 0 | register bit 1 |
| 2 | ALU bit 1 | counter bit 1 | counter bit 6 | register bit 2 | register bit 3 |
| 3 | ALU bit 2 | counter bit 2 | counter bit 5 | – | – |
| 4 | ALU bit 3 | counter bit 3 | counter bit 4 | – | – |
| 5 | sequencer | (sequencer) | (sequencer) | clock | – |
| 6 | (sequencer) | (sequencer) | (sequencer) | panel A | panel B |
| 7 | (sequencer) | (sequencer) | (sequencer) | panel C | hub |

Back, as the back sees it (its column 1 stands behind the front's
column 5, so the hub is right behind it):

| Row | Column 1 | 2 | 3 | 4 | 5 |
|---|---|---|---|---|---|
| 1 | memory control | program 1 | program 12 | program 13 | – |
| 2 | memory slots 0 | program 2 | program 11 | program 14 | – |
| 3 | memory slots 1 | program 3 | program 10 | program 15 | – |
| 4 | memory slots 2 | program 4 | program 9 | program 16 | – |
| 5 | memory slots 3 | program 5 | program 8 | program 17 | – |
| 6 | memory slots 4 | memory slots 7 | program 7 | program 18 | – |
| 7 | memory slots 5 | memory slots 6 | program 6 | program 19 | program 20 |

The program cards are numbered along ribbon B, so a longer program is
more cards at the ribbon's end, up the back's column 5: 26 program cards
fit (104 words; `sort` takes 20). Which program card holds which page is its
jumpers, not its slot. 61 card slots in all (26 on the front beside the
sequencer, 35 on the back), 50 cards in them, 11 free.

The panel's switches and buttons are 4 to 26 cm above the table, the
hub's banana sockets about 9 cm, bottom right of the front. The memory's 64
cell LEDs and the program are on the back.

## The ribbons

An IDC socket lies across its ribbon and every bus header lies along its
card's top edge, on the back of the card (D059), so the bus ribbon runs
down a column of cards behind them, a socket every 110 mm, never along a
row. It is 81 mm wide (64 conductors at 1.27 mm) and passes between a
card's two standoffs, which are 92 mm apart, through the gap between card
and rail.

Every header sits the same way round (notch toward the card's top edge,
pin 1 at the top left as the front of the card sees the holes), so every
socket must arrive with conductor 1 (the red edge) on the left as that
face is seen. A 45 degree fold turns the ribbon by 90 degrees and moves
conductor 1 from one edge to the other; two of them making a U-turn leave
it mirrored (pin 1 would meet pin 64). **A turn is three folds**: a 45
degree fold sideways, a 45 degree fold back to the column's direction
(the sideways step), and one straight fold back on itself. The same three
folds serve at the top of a column, at the bottom, and where ribbon B
comes up the back after passing under the panel: there it arrives
mirrored because the back's viewer has turned round, and the three folds
put conductor 1 back on the left. The sideways band of a turn starts
just past the last socket and lies back over the column, behind the
cards. `bring-up.md` has the continuity test every ribbon gets before it
sees power.

Ribbon A, from the hub's top header: up column 5, down 4, up 3, down 2,
a sideways step over the sequencer's top edge, down column 1 through the
sequencer's socket, a straight fold, and back up column 1. 22 sockets,
four turns, 3.74 m with 300 mm of slack.

Ribbon B, from the hub's bottom header (along the hub's bottom edge, on
its back): down behind the hub, under the panel between the feet, up the
back's column 1, down 2, up 3, down 4, up 5 as far as the program goes.
30 sockets, five turns, 3.65 m with 300 mm of slack.

7.4 m of 64-way ribbon end to end; buy 10 m, the 6-way and 12-way pieces
are torn off the rest along a groove. The bus sees it all: a line's
capacitance is the whole 7.4 m. Flat ribbon is about 50 pF per metre
between neighbouring conductors and the bus pinout puts signal beside
signal, so a line sees 400 to 800 pF depending on what its neighbours
are doing. The machine deck is proven at 300, 500 and 800 pF per line
(`cards.md` step 9; the 800 pF run: `sim/results/gate26_800pF_HI.md`,
2026-10-04, six programs at HI, 6 of 6 pass).

### The links between neighbours

The link headers are on the front of the cards along the bottom edge:
`IN` at x = 14, `OUT` at x = 80, the chained 12-way `LINK` at x = 40.
Their ribbon leaves downward.

- **12-way chains, over the fronts.** Every counter card and every memory
  card has its `LINK` header at the same place, so a 12-way ribbon with a
  socket crimped on every 110 mm runs straight down a column of them,
  15 mm wide, over the transistors between x = 32 and 48 where no LED
  stands. That is why the counter stands in two columns and the memory in
  one: the sequencer's link header (on its top edge, x = 115 of the
  board, in column 2's width) sends its ribbon up column 2 over counter
  bits 3, 2, 1, 0, a U-turn in the top margin, and down column 3 over
  bits 7, 6, 5, 4: 9 sockets, about 1.0 m. Memory control at the top of
  the back's column 1 sends its ribbon down over slots 0 to 5, a U-turn
  under row 7, and up column 2 over slots 6 and 7: 9 sockets, about
  1.0 m. Visible wiring, by design.
- **6-way carry links.** `OUT` of one card to `IN` of the next. Side by
  side (counter bit 3 to bit 4, the only pair in a row) the ribbon leaves
  `OUT` downward into the gap under the row, a U with a half twist back
  up into `IN`: about 80 mm. One above the other (the three ALU pairs and
  the six other counter pairs) the ribbon leaves `OUT` into the gap under
  the card, runs to the column gap on the card's right, along it to the
  gap under the next card and back in to `IN`: about 230 mm, never over
  a card's face. Ten cables, 2.2 m of 6-way.

## Open until the pilot

- **The standoffs.** A box header is 9 mm high and the socket on it
  reaches about 15 mm behind the card; the rail is 40 mm below the
  header, so on a card the socket sits above its rail and 12 mm standoffs
  may do. On the sequencer the upper rail runs 12 mm below its header and
  the socket sits in front of the rail: its four standoffs must be longer
  than the socket is thick. Measure the pilot's hub with a socket crimped
  on, then buy.

## Parts

From `node panel.js`:

| Part | Qty | Note |
|---|---|---|
| 2020 extrusion, 800 mm | 2 | the uprights |
| 2020 extrusion, 580 mm | 14 | 7 rails on the front face, 7 on the back; 8.1 m |
| 2020 extrusion, 300 mm | 2 | the feet, flat under the uprights, across the panel |
| 2020 corner brackets with their screws and T-nuts | 32 | one at each rail end, two per foot |
| M3 T-nuts for the 6 mm slot | 114 | two per card, four for the sequencer, ten over |
| M3 male-female standoffs, 12 mm or what the pilot says | 114 | brass; the sequencer's may be longer |
| M3 x 6 mm screws | 228 | card to standoff, standoff to T-nut; no washers: the cards' mounting pads are 6.4 mm and tracks pass 0.2 mm outside them (the order gate holds copper of other nets 3.3 mm from the hole's centre, the reach of a hex standoff's corners) |
| Rubber feet, self-adhesive | 4 | under the feet |

About 10 m of extrusion, all stock lengths. Bought after the pilot's
standoff measurement, with the ribbon.

## What it does not do

It has a back: the memory and the program are behind what you stand in
front of, so it wants a table you can walk round, or it turns on its
feet. The 12-way chains lie over the fronts of the counter and memory
cards. A program longer than 104 words is more than the back holds; the
counter allows 256.

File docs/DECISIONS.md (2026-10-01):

# Decision ledger

Append-only. One row per decision, newest at the bottom. `Story` says what it
changes for the public log (the X account brain lives in a separate repo and
reads this file). IDs never change; a reversed decision gets a new row.

| ID | Date | Decision | Why | Story |
|---|---|---|---|---|
| D001 | 2026-08-17 | Hand-build a 3-bit sign-magnitude add/subtract calculator in RTL (2N3904, 10k/22k/4.7k) as a learning exercise. | Relearning electronics from nothing. | The origin. Posted as-is, bugs and all. |
| D002 | 2026-09-09 | Extend the calculator with a sequential multiplier/divider, simulation only. | Test whether an AI can work at schematic level. | 480 extra transistors, 256/256 exhaustive pass. Not built. See `experiments/muldiv/`. |
| D003 | 2026-09-09 | The goal is a 4-bit CPU, built as separate boards, in public. Multiply/divide dropped from the roadmap. | 4-bit CPUs multiply in software; the experiment served its purpose. | "Nibble". |
| D004 | 2026-09-09 | Logic family: NMOS with 2N7000 and one pull-up resistor per gate. The 2N3904 RTL cell is retired. | MOSFET gates draw no current: fan-out limited only by speed, no base resistors, 20x less supply current, rail-to-rail levels. RTL was limited to 3 loads and sagged to 1.2 V on the memory bits. | The 419-transistor count restarts. "I threw away 419 bipolar transistors" is the post. |
| D005 | 2026-09-09 | Through-hole parts, hand-soldered, board size unconstrained. | Nikola wants to solder every joint. | Joint count is a recurring number. |
| D006 | 2026-09-09 | Number representation: 4-bit two's complement. The sign-magnitude converter is gone. | Subtraction becomes "invert B, add 1". Both known bugs of the origin lived in the converter. | Educational post: why computers use two's complement. |
| D007 | 2026-09-09 | Accumulator architecture: registers A, B, OUT, IR, PC; flags C and Z; ten instructions (see `isa.md`). Program memory is 16 words of 8 bits. | Smallest design that can loop and branch. Same shape as SAP-1, scaled to 4 bits. | The Fibonacci program is the first-program milestone. |
| D008 | 2026-09-09 | Program memory is a grid of DIP switches with one diode per bit. The CPU cannot write it. | Zero transistors instead of about 1,500 for flip-flop RAM. Reprogrammed by flipping switches. Filmable. | Altair-style front panel. |
| D009 | 2026-09-09 | Boards connect with 50-way ribbon cables to a bus hub board and sit in a rack, not stacked on headers. | A stack of pass-through headers gets wobbly past 4 boards; a rack looks better on camera. | The rack shot. |
| D010 | 2026-09-09 | Bus lines are open-drain, active-low, pulled up on the hub. | NMOS gives a shared bus for free; no tri-state logic needed. | One sentence on wired-OR buses. |
| D011 | 2026-09-09 | Fab order 1 = gate coupon + ALU board + front panel board. Nothing is ordered before the whole board passes an exhaustive ngspice sweep at both 2N7000 threshold corners. | The coupon measures the cell; the front panel tests every later board too. | Two cliffhangers: order and power-on. |
| D012 | 2026-09-09 | Decision ledger lives here. The X repo's own ledger points at IDs from this table. | One source of truth for engineering; the story repo reads, never rewrites. | |
| D013 | 2026-09-09 | Fab order 1 grows to four boards: coupon, ALU, front panel, bus hub. | The ALU and panel need the hub's power entry and bus pull-ups; the hub is the cheapest board. | Four boards in one order. |
| D014 | 2026-09-09 | Panel switches drive lines through 10k to +5 V; buttons through a diode; every line has a 1 Meg pull-down. | A switch left on can never fight a board that pulls low (NMOS pulls low through a few ohms). No "manual mode" switch needed. | One sentence on wired-OR. |
| D015 | 2026-09-09 | No power switch on the hub; the USB plug is the switch. | No suitable through-hole switch in the standard library; fewer parts. | |
| D016 | 2026-09-09 | PCB style: one tile per cell (pull-up on top, transistors in a column), 10.16 to 15.24 mm column pitch, power pre-routed as rails on the back, signals autorouted (freerouting), ground pour on the back. Two layers, hand-soldering rules (0.25 mm tracks, 0.2 mm clearance). | Regular tiles make routing and soldering predictable; the board reads like the schematic. | The board renders. |
| D017 | 2026-09-10 | Bus header is 2x32 (64 pins). Adds PC4..7, BO, MAI, MI, MO, PWL, PWH and four spares over the 50-pin version. All boards regenerate before anything is ordered. | The header is the contract; every later board plugs into pins named now. Reversing it after hand-soldering is a respin of every board. | "The header is the contract" post. |
| D018 | 2026-09-10 | Program counter is 8 bits; jumps are two-word instructions (opcode word, then an 8-bit address word); an 8-bit operand register on the sequencer. | 4-bit data does not mean 4-bit addresses (the 4004 had 12-bit ones). 16 words is a demo ceiling; 256 words costs about 160 transistors once. | Educational post: data width vs address width. |
| D019 | 2026-09-10 | Program memory boards are pageable: PC0..3 select the row, PC4..7 are compared with four jumpers, M0..7 are diode-OR across boards. More program space = more copies of the same board. | The fab ships five copies of every board anyway. One design, 16 to 64 words. | The stack of switch boards. |
| D020 | 2026-09-10 | Data memory (scratch RAM) is a separate future board: 16 slots x 4 bits, its own address register loaded from the bus (MAI), MI/MO lines. Opcodes 1011 LOAD n and 1100 STORE n reserved. | The address coming from the bus lets a loop use B as a pointer (needs BO) so programs can walk lists. Fixed-address LOAD cannot. | Multiply, divide, sort become programs, not boards. |
| D021 | 2026-09-10 | Control board is a diode matrix: 16 opcodes x 2 execute steps = 32 rows, one column per control line plus DONE, 1 Meg pull-downs, holes at every crossing, ten instructions populated at assembly. | Adding an instruction is soldering diodes, not a new board. The instruction set is readable off the board. Same technology as the program memory. | The microcode-as-diodes post. |
| D022 | 2026-09-10 | Sequencer has five states (fetch, increment, optional second fetch, execute 1, execute 2) with early DONE. One-word instructions stay at 3 ticks. | Memory access needs two execute ticks; two-word jumps need a second fetch. | |
| D023 | 2026-09-10 | B register gets a bus output (BO). | Memory pointer for loops. Four transistors. | |
| D024 | 2026-09-10 | Whole-machine simulation against a Python emulator is the acceptance test for every board, before and after fab. Boards for order 2 are designed and pass it before order 1 is placed. | So that order 1 cannot be invalidated by something learned while designing the sequencer. | The "it ran Fibonacci in ngspice before copper existed" post. |
| D025 | 2026-09-10 | Parts are bought once, in whole-machine quantities, from LCSC (about 87 USD for 2,000 transistors and everything else) rather than per order from DigiKey (218 USD for one board set). Ribbon cables from Amazon. | Same parts on every board; bulk pricing; the user does not mind the wait. | The parts-cost post. |
| D026 | 2026-09-10 | Nothing is committed to this repo without Nikola's say-so. Drafts live in the working tree. | The public history is curated. | |
| D027 | 2026-09-10 | Design work is committed as it is built, in coherent units; shopping lists, vendor carts and their revisions are never committed (supersedes D026). | The git log feeds the public story; carts are noise in it. | |
| D028 | 2026-09-10 | Header pins 57/58 are named WRL/WRH, not PWL/PWH. | `pwl` is an ngspice keyword; a net called PWL cannot be probed in the machine simulation. Found the first time the whole-machine deck ran. | First bug found by the machine deck, before a single board existed. |
| D029 | 2026-09-10 | The sequencer's registers: IR holds the 4-bit opcode; an 8-bit operand register takes M3..0 at II and all of M at OPI; only ADD and SUB latch the flags; one-word instructions skip S2. | Writing the emulator forced the choices the ISA text left open. Fewer flip-flops than an 8-bit IR plus an 8-bit operand register. | "The emulator is the spec" post. |
| D030 | 2026-09-10 | Design v2, instruction set: opcode 0000 is a family whose operand nibble selects among 16 operand-free instructions (NOP, MOV, XCH, ADD, SUB, OUT, HLT, DEC, INC, LOAD [B], STORE [B], IN, RET, AND, OR, XOR); LDI, JMP, JC, JZ, LOAD n, STORE n, CALL keep their own opcodes; eight opcodes free. | Seven of the sixteen opcodes were spent on instructions that ignore their operand. The family costs one more 4-to-16 decoder and gives indirect memory access (what makes BO and the memory board worth building), loops that do not clobber B, an input port, one-level subroutines and bit operations. | "How 16 opcodes became 31" post. |
| D031 | 2026-09-10 | The four spare header pins become ONE (ALU uses 1 for B), F0/F1 (ALU function: add, and, or, xor) and INP (panel switches drive the bus). No spares remain. | Everything the ISA can ever ask of the ALU and the panel has to cross the header now; those two boards are not respun. | |
| D032 | 2026-09-10 | One fab order for every board, after all of them pass the machine gate; no separate order 1 and 2, and the data memory board is designed now, not after a working machine. | Nikola: nothing forces a two-stage build; the machine simulation is the gate, not a first fab. The coupon ships in the same order, so its measurements confirm rather than precede. | |
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

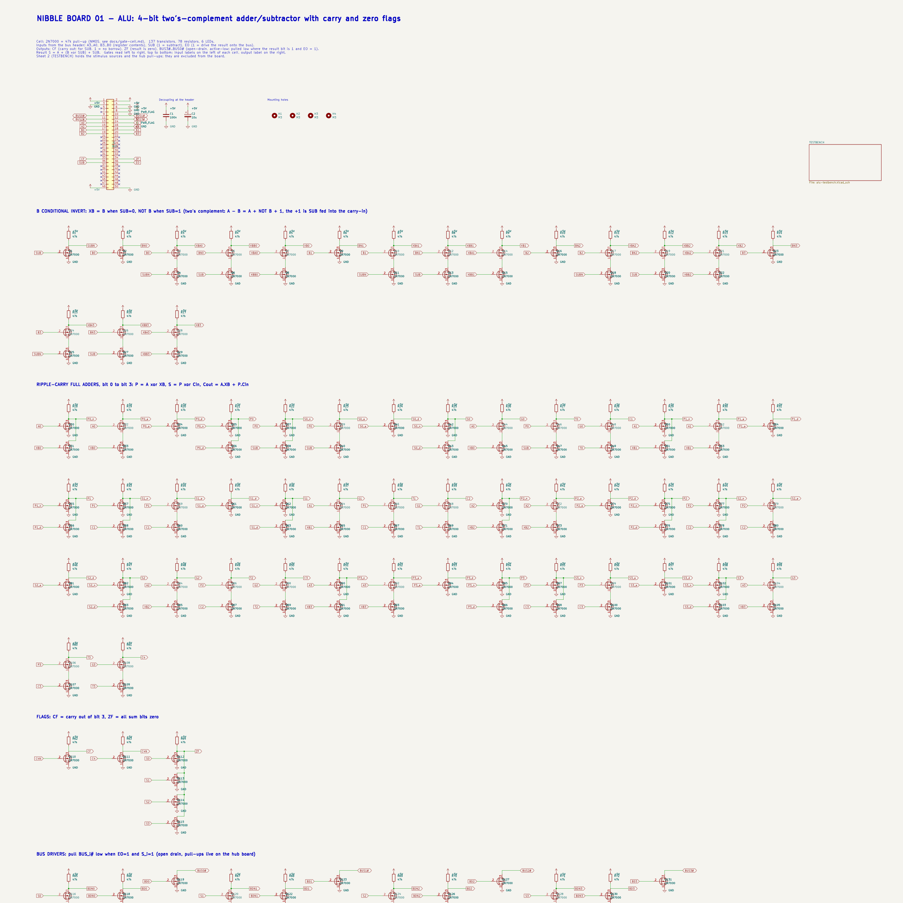
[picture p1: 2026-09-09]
boards/01-alu/sim_results/alu_schematic.png

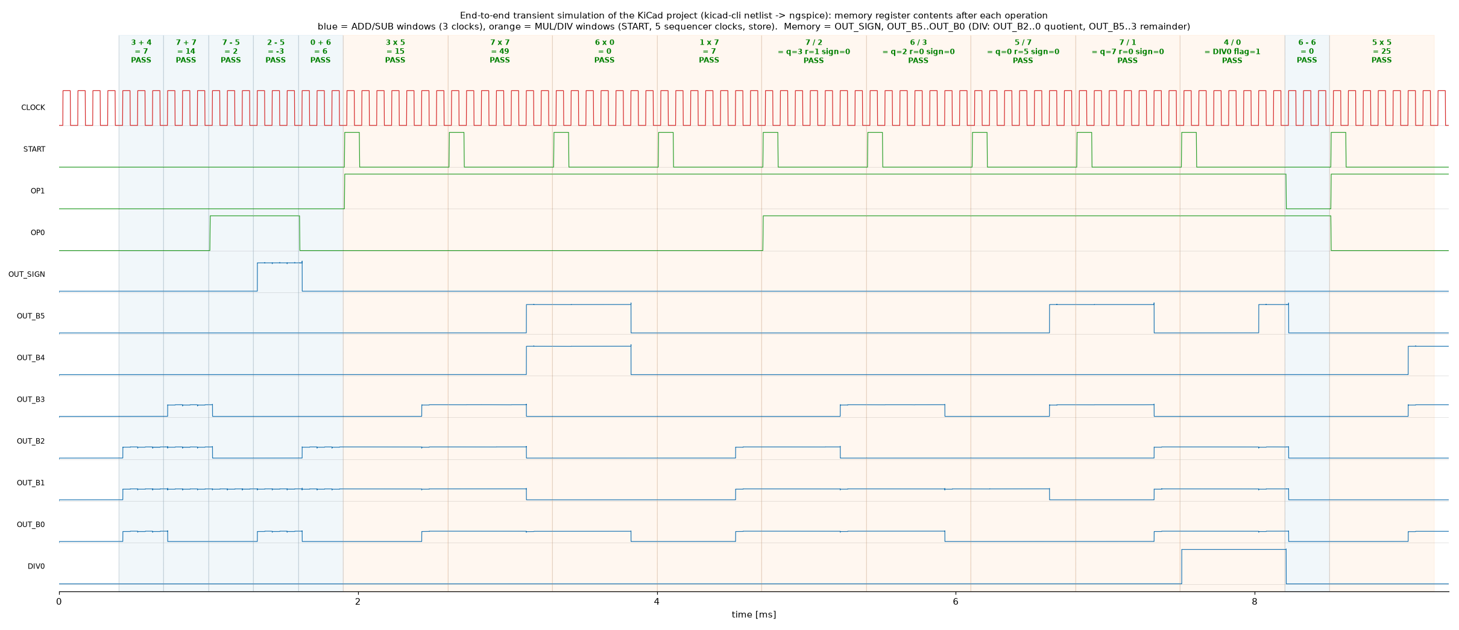
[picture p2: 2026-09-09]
experiments/muldiv/sim_results/tran_overview.png

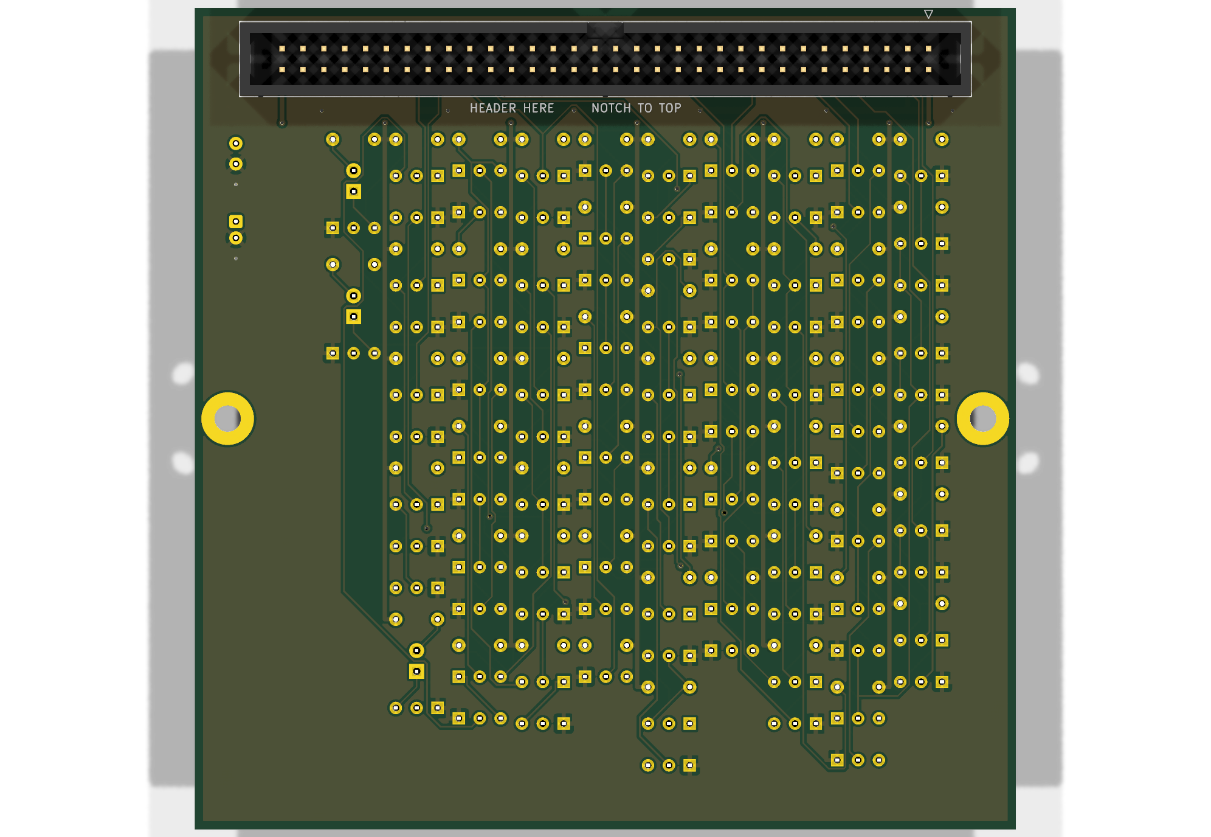
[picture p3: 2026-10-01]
cards/reg1/fab/reg1-bottom.png

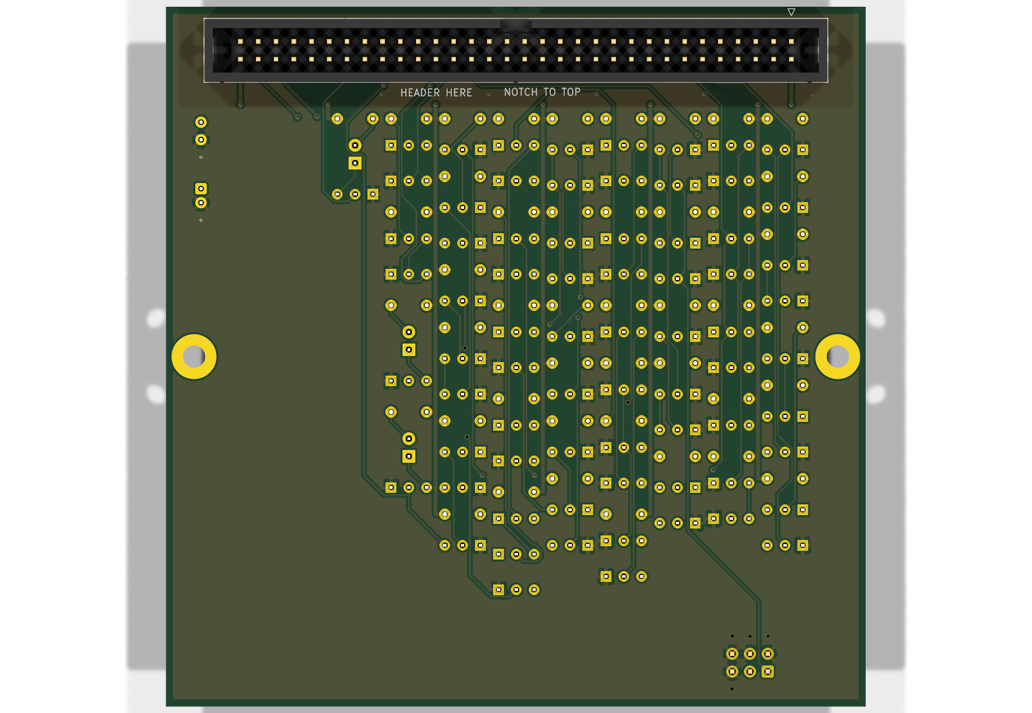
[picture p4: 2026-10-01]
cards/alu3/fab/alu3-bottom.png

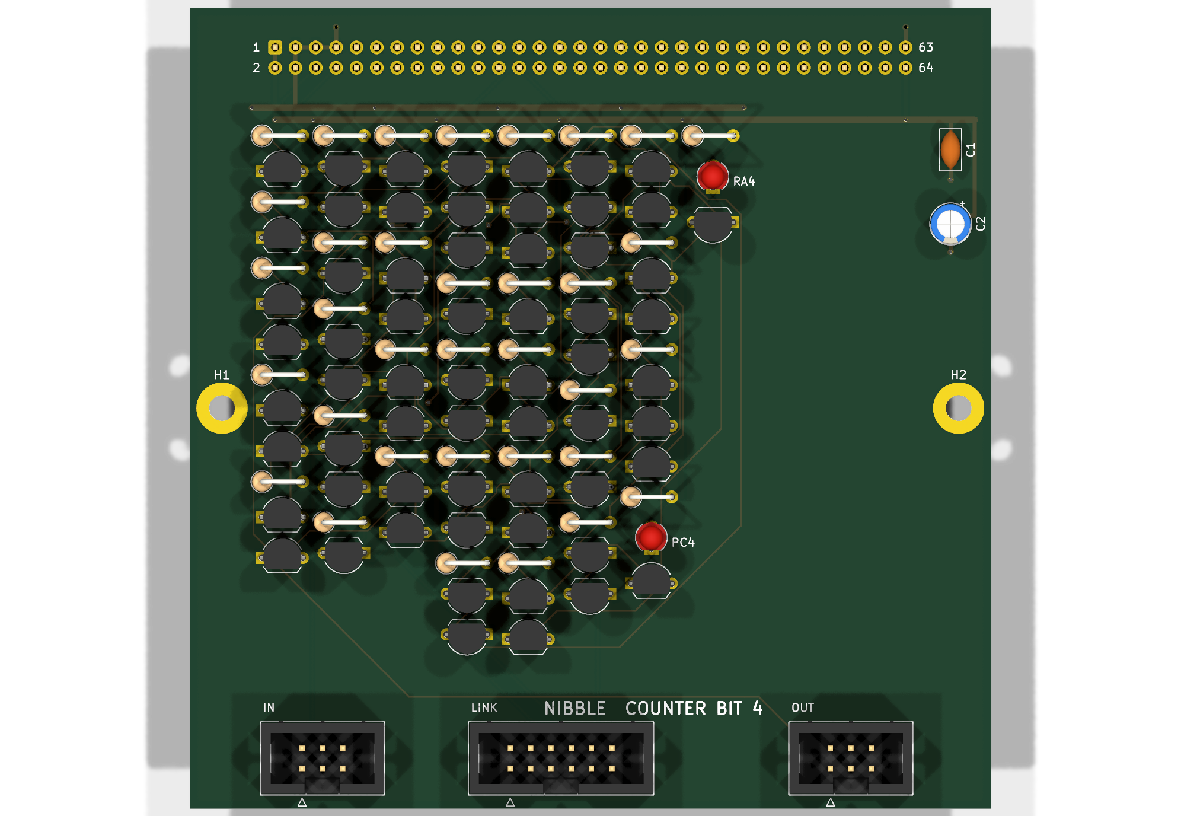
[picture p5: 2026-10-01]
cards/ctr4/fab/ctr4-top.png

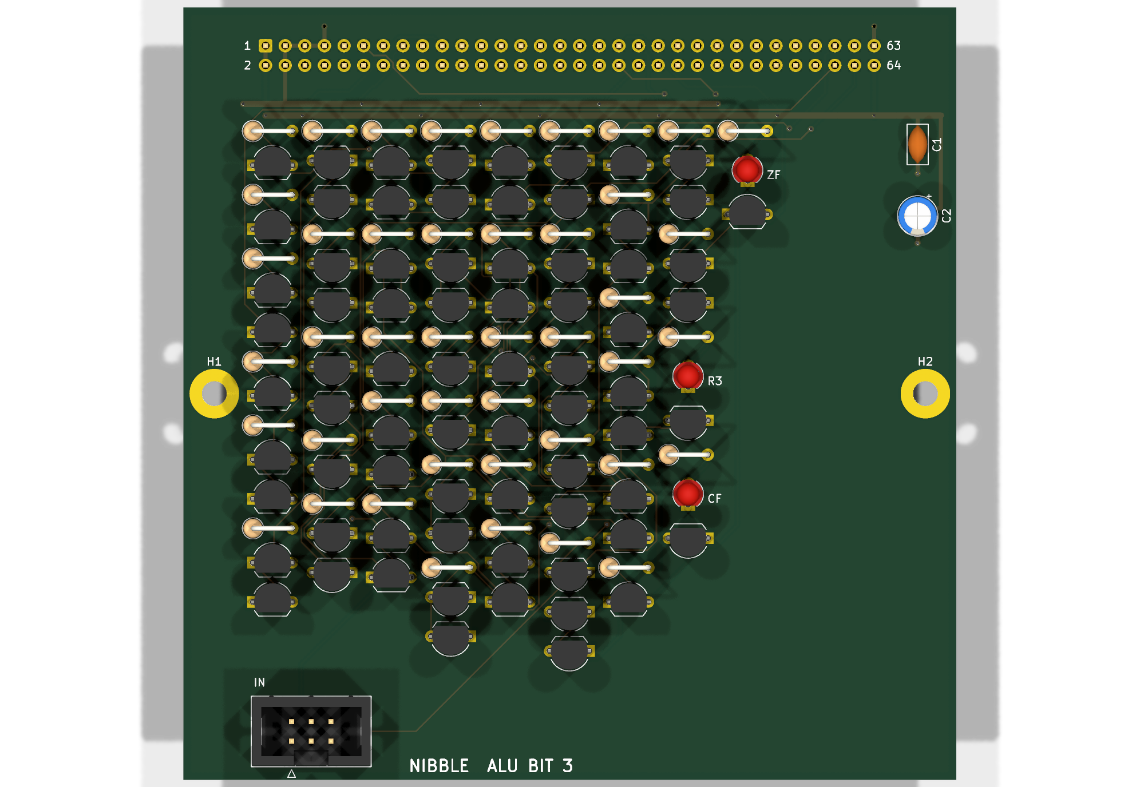
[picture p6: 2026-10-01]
cards/alu3/fab/alu3-top.png

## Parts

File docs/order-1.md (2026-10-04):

# The order: boards, parts, cables, frame

Rewritten 2026-09-29. The three tables between the `bom.py` markers are
written by `python3 sim/bom.py --write` from the routed boards and are not
edited by hand; `python3 sim/bom.py --check` fails when they are stale or
when the schematics and the boards disagree about a part. How this
document got here is in `docs/order-log.md`.

Two words, used strictly: a **design** is a set of files, a **board** is a
piece of fibreglass that is built. The machine is 26 designs and 52 boards.

## 1. What can be ordered today

| | State |
|---|---|
| Coupon, register bit 0, hub (the pilot) | Ready. `ORDER GATE: all pass` on all 26 boards at commit `3d7befc` (2026-10-01): the headers on the back, the hub with its sockets, its crowbar (D061, D063) and the empty C-RST spot, the front silk with the pin numbers only (the logo is on the sequencer alone). Every command of section 6 ended as written |
| Everything else | After the pilot is built and measured (D055) |
| Cables, frame | Drawn (`docs/mounting.md`, D065, 2026-10-01). Bought after the pilot's standoff measurement; the 800 pF run is paid (`sim/results/gate26_800pF_HI.md`, 2026-10-04) |

The pilot (D055) is the coupon, register bit 0 and the hub, five of each:
the fab, the parts and the hands are tried on three designs before thirty
are paid for. The coupon has every kind of cell with a test loop on it;
the register card is one full logic card; the hub is the power entry and
the first ribbon.

The three files to upload, as committed at `3d7befc` (the zip in each
design's `fab/` folder; the md5 is of that file):

| Zip | md5 |
|---|---|
| `cards/coupon/fab/coupon-gerbers.zip` | 80d2c4a4d107c5885c59909ef3b65807 |
| `cards/reg0/fab/reg0-gerbers.zip` | 95735a930bbdcb2e9361d42e02de0f2a |
| `cards/hub/fab/hub-gerbers.zip` | 40e0588b695449c76d9f7edc6b536248 |

In JLCPCB's preview: the outline is the square; the front has two rows of
32 holes along the top edge with 1, 2, 63, 64 at their corners; the back
has the header's outline there with HEADER HERE and NOTCH TO TOP. Leave
every option as it comes (2 layers, 1.6 mm, HASL, quantity 5).

## 2. Boards

<!-- bom.py: boards -->
| Design | Files | Boards built of each | Five-packs to order | Boards over |
|---|---|---|---|---|
| ALU bit | `cards/alu0` to `alu3`, 4 designs | 1 | 1 each | 4 each |
| clock | `cards/clock` | 1 | 1 | 4 |
| gate coupon (a test card, not in the machine) | `cards/coupon` | 1 | 1 | 4 |
| counter bit | `cards/ctr0` to `ctr7`, 8 designs | 1 | 1 each | 4 each |
| bus hub | `cards/hub` | 1 | 1 | 4 |
| memory control | `cards/memctl` | 1 | 1 | 4 |
| memory slots (one pair of slots a card) | `cards/memslot` | 8 | 2 | 2 |
| panel A | `cards/panela` | 1 | 1 | 4 |
| panel B | `cards/panelb` | 1 | 1 | 4 |
| panel C | `cards/panelc` | 1 | 1 | 4 |
| program (four words a card) | `cards/prog` | 20 | 5 | 5 |
| register bit | `cards/reg0` to `reg3`, 4 designs | 1 | 1 each | 4 each |
| sequencer (245 x 255 mm, four layers) | `boards/03-sequencer` | 1 | 1 | 4 |
| **26 designs** | | **52 boards** | **31 five-packs** | |
<!-- bom.py: end boards -->

The fab sells five of a design. "Boards over" are spares. Twenty program
cards are four five-packs to the last board, so a fifth is ordered (decided
2026-09-29): five over.

To order a design: upload `fab/<name>-gerbers.zip` from its folder at
JLCPCB's quote page, wait for the preview, leave the options as they come
(1.6 mm, HASL, any colour, quantity 5). The cards are two layers, 100 x
100 mm. The sequencer is four layers, 245 x 255 mm, and its zip has eleven
files (two inner layers). The price is what the calculator says for the
uploaded file; write it down here when it has been read. No price in this
document is a quote yet.

## 3. Parts for the pilot

One board of each of the three designs:

<!-- bom.py: pilot -->
| Part | coupon | reg0 | hub | Together |
|---|---|---|---|---|
| 2N7000 transistor, TO-92 | 57 | 99 |  | 156 |
| 1N4148 diode, DO-35 | 2 |  |  | 2 |
| Resistor 100 ohm, 1/4 W axial | 1 |  | 1 | 2 |
| Resistor 1 kohm, 1/4 W axial | 3 | 3 | 1 | 7 |
| Resistor 3.3 kohm, 1/4 W axial | 1 |  |  | 1 |
| Resistor 4.7 kohm, 1/4 W axial | 2 |  |  | 2 |
| Resistor 10 kohm, 1/4 W axial | 3 | 2 | 4 | 9 |
| Resistor 22 kohm, 1/4 W axial |  | 2 |  | 2 |
| Resistor 47 kohm, 1/4 W axial | 36 | 47 |  | 83 |
| Resistor 100 kohm, 1/4 W axial | 1 |  |  | 1 |
| Resistor 220 kohm, 1/4 W axial | 1 |  | 8 | 9 |
| Resistor 1 Mohm, 1/4 W axial | 5 |  |  | 5 |
| LED, 3 mm | 1 | 3 | 1 | 5 |
| Electrolytic capacitor 100 uF, 5 mm can, 2 mm pitch, 16 V or more |  |  | 1 | 1 |
| Electrolytic capacitor 10 uF, 5 mm can, 2 mm pitch, 16 V or more | 1 | 1 |  | 2 |
| Ceramic capacitor 100 nF, 2.5 mm pitch | 1 | 1 | 2 | 4 |
| Ceramic capacitor 47 nF, 2.5 mm pitch | 1 |  |  | 1 |
| Box header 2x32, 2.54 mm (the bus) | 1 | 1 | 2 | 4 |
| Pin header 1x2, 2.54 mm | 1 |  |  | 1 |
| Pin header 1x6, 2.54 mm | 1 |  |  | 1 |
| Test loop, 1.0 mm hole | 15 |  | 6 | 21 |
| SCR BT151-500R, TO-220 (the crowbar) |  |  | 1 | 1 |
| Zener diode 1N4735A, 6.2 V 1.3 W (the crowbar) |  |  | 1 | 1 |
| Rectifier diode 1N5408, 3 A (crossed leads) |  |  | 1 | 1 |
| Polyfuse 1.5 A (Bel 0ZRE0150FF) |  |  | 1 | 1 |
| Banana socket, 4 mm, for the board, upright: Cal Test CT3151V1-2 (red) and CT3151V1-0 (black), one of each |  |  | 2 | 2 |
| **325 parts on one board of each** | 134 | 159 | 32 | |
<!-- bom.py: end pilot -->

Every line here is a line of section 4, and section 4's Need counts
these three boards among its 52, so the machine's quantities cover the
pilot. The hub's empty C-RST spot (a 2.2 nF ceramic, fitted only if the
scope asks for it, `bring-up.md` section 9) is not in this table; section
4 has ten. The bench also wants: a 3.3 nF capacitor with clip leads and a
x10 scope probe for the coupon (`sim/results/coupon_expected.md`), a pair
of banana-to-banana leads, a short 64-way ribbon with three IDC sockets
crimped on (section 5), and a few jumper wires with a 1k resistor to
raise the register's control lines by hand (`bring-up.md`, top).

## 4. Parts for the machine

<!-- bom.py: parts -->
| Part | Need | Buy | Spares rule |
|---|---|---|---|
| 2N7000 transistor, TO-92 | 3516 | 3900 | a tenth over, to the next 100 |
| 1N4148 diode, DO-35 | 733 | 900 | a tenth over, to the next 100 |
| Resistor 100 ohm, 1/4 W axial | 6 | 100 | a tenth over, to the next 100 (they come in hundreds) |
| Resistor 1 kohm, 1/4 W axial | 288 | 400 | a tenth over, to the next 100 (they come in hundreds) |
| Resistor 3.3 kohm, 1/4 W axial | 81 | 100 | a tenth over, to the next 100 (they come in hundreds) |
| Resistor 4.7 kohm, 1/4 W axial | 4 | 100 | a tenth over, to the next 100 (they come in hundreds) |
| Resistor 10 kohm, 1/4 W axial | 133 | 200 | a tenth over, to the next 100 (they come in hundreds) |
| Resistor 22 kohm, 1/4 W axial | 87 | 100 | a tenth over, to the next 100 (they come in hundreds) |
| Resistor 47 kohm, 1/4 W axial | 1443 | 1600 | a tenth over, to the next 100 (they come in hundreds) |
| Resistor 100 kohm, 1/4 W axial | 8 | 100 | a tenth over, to the next 100 (they come in hundreds) |
| Resistor 220 kohm, 1/4 W axial | 11 | 100 | a tenth over, to the next 100 (they come in hundreds) |
| Resistor 1 Mohm, 1/4 W axial | 78 | 100 | a tenth over, to the next 100 (they come in hundreds) |
| LED, 3 mm | 281 | 350 | a tenth over, to the next 50 |
| Electrolytic capacitor 100 uF, 5 mm can, 2 mm pitch, 16 V or more | 1 | 10 | a tenth over, to the next 10 |
| Electrolytic capacitor 10 uF, 5 mm can, 2 mm pitch, 16 V or more | 51 | 60 | a tenth over, to the next 10 |
| Electrolytic capacitor 2.2 uF, 5 mm can, 2 mm pitch, 16 V or more | 2 | 10 | a tenth over, to the next 10 |
| Electrolytic capacitor 1 uF, 5 mm can, 2 mm pitch, 16 V or more | 2 | 10 | a tenth over, to the next 10 |
| Ceramic capacitor 100 nF, 2.5 mm pitch | 53 | 60 | a tenth over, to the next 10 |
| Ceramic capacitor 47 nF, 2.5 mm pitch | 2 | 10 | a tenth over, to the next 10 |
| Ceramic capacitor 2.2 nF, 2.5 mm pitch | 2 | 10 | a tenth over, to the next 10 |
| Box header 2x32, 2.54 mm (the bus) | 53 | 56 | a twentieth over, two at the least |
| Box header 2x6, 2.54 mm (link) | 18 | 20 | a twentieth over, two at the least |
| Box header 2x3, 2.54 mm (link) | 20 | 22 | a twentieth over, two at the least |
| Pin header 1x3, 2.54 mm (address jumper) | 144 | 152 | a twentieth over, two at the least |
| Pin header 1x2, 2.54 mm | 2 | 4 | a twentieth over, two at the least |
| Pin header 1x6, 2.54 mm | 1 | 3 | a twentieth over, two at the least |
| DIP switch, 8-way | 84 | 89 | a twentieth over, two at the least |
| Test loop, 1.0 mm hole | 21 | 23 | a twentieth over, two at the least |
| SCR BT151-500R, TO-220 (the crowbar) | 1 | 2 | one over |
| Zener diode 1N4735A, 6.2 V 1.3 W (the crowbar) | 1 | 2 | one over |
| Rectifier diode 1N5408, 3 A (crossed leads) | 1 | 2 | one over |
| DIP switch, 4-way | 1 | 2 | one over |
| DIP switch, 1-way | 1 | 2 | one over |
| Push button, 6 mm tactile | 2 | 3 | one over |
| Potentiometer 1 M linear, 9 mm upright (Bourns PTV09A-4) | 1 | 2 | one over |
| Polyfuse 1.5 A (Bel 0ZRE0150FF) | 1 | 2 | one over |
| Banana socket, 4 mm, for the board, upright: Cal Test CT3151V1-2 (red) and CT3151V1-0 (black), one of each | 2 | 2 | none over: two are fitted |
| Jumper cap, 2.54 mm (one on every 1x3 and 1x2 pin header, the coupon's supply inlet excepted) | 145 | 153 | a twentieth over, two at the least |
| **7136 parts soldered on 52 boards** | | | |
<!-- bom.py: end parts -->

Need is what the 52 boards carry. Buy is Need with spares by the rule in
the last column; the rules are `RULES` in `sim/bom.py`, to be changed
there.

What to look for when buying:

| Part | Look for | Why |
|---|---|---|
| 2N7000 | TO-92, from Onsemi or Diodes Inc. | The boards' holes are 2.54 mm apart; a straight TO-92 has its leads 1.27 mm apart and is spread by hand or on a jig. Anti-static bag until soldered |
| Resistors | 1/4 W, body no longer than 6.3 mm | They stand upright on 5.08 mm |
| Electrolytics | 5 mm can, 2 mm between the leads, 16 V or more | A 25 V 100 uF is a 6.3 mm can and does not fit; the crowbar lets the rail reach 8 V before it fires |
| Ceramic capacitors | 2.5 mm between the leads | Not the 5 mm kind |
| Box headers | Shrouded, straight, 2.54 mm (2x32: XFCN BH254V-64P, LCSC C48603668, or any) | They are soldered on the **back** of the boards (D059) |
| DIP switches | Slide type, 7.62 mm between the rows | |
| Potentiometer | Bourns PTV09A-4020F-B105 (1 M linear, 20 mm shaft) | The footprint is this family's: two 2.2 mm leg holes 8.8 mm apart, 7.0 mm from the pins; the PTV09A-1, -5 and -6 share them |
| Polyfuse | Bel 0ZRE0150FF | The footprint is this part's kinked leads: 10.2 mm with a 1.9 mm offset |
| LEDs | 3 mm, any colour; 2 mA types are bright behind 1 k | |
| Banana sockets | Cal Test CT3151V1-2 (red) and CT3151V1-0 (black), the V1 (upright, 19 mm) | The footprint is this part's four pins. The plain CT3151 lies on its side and does not fit |
| SCR, zener, large diode | BT151-500R (TO-220), 1N4735A (6.2 V, 1.3 W), 1N5408 | The crowbar's values are the bench's (`sim/results/crowbar.md`). A clip-on TO-220 heatsink if the supply's limit is ever above 1.5 A |

## 5. Cables and frame

Counted on the boards:

| Part | Need | Buy | Note |
|---|---|---|---|
| IDC socket 2x32 (ZHOURI FC-2.54-64P, LCSC C49261185, or any) | 53 | 60 | one for every bus header: 52 boards, the hub has two. A socket is crimped once |
| IDC socket 2x3 | 20 | 24 | the ALU's and the counter's chains |
| IDC socket 2x6 | 18 | 22 | the sequencer's operand link, the memory's address link |
| Ribbon, 64-way, 1.27 mm | 7.4 m | 10 m | the two bus ribbons, 3.74 and 3.65 m with slack (`docs/mounting.md`); the 6- and 12-way pieces come off the rest |
| Ribbon, 6-way and 12-way | 2.2 m, 2.0 m | | torn off the 64-way along a groove: ten 6-way carry links (80 or 230 mm), two 12-way chains of 9 sockets (about 1 m each) |

The frame's parts are in `docs/mounting.md` (two-sided panel, D065).
They are bought after the pilot's hub has been measured with a socket on
its header (the standoff length). The machine deck has been run at
800 pF per bus line (the 7.4 m of ribbon may put that much on a line):
6 of 6 pass, `sim/results/gate26_800pF_HI.md`, 2026-10-04.

## 6. Before pressing order

Run from `sim/`, on the commit that is ordered. Each must end as written.

| Command | Ends with |
|---|---|
| `python3 order_check.py <every design in the order>` | `ORDER GATE: all pass` |
| `python3 order_check.py --machine` | `all pass` (every bus header and every link, pin by pin) |
| `python3 order_check.py --selftest` | every planted fault caught |
| `python3 bom.py --check` | the tables are current and the two counts agree |
| `python3 rebuild_check.py` | `every builder writes what is committed` |
| `python3 silk_proof.py <every design in the order>` | the prints in `sim/out/proof/`, looked at: every name readable, none across a pad |

And by eye, in each design's `fab/` folder: the two renders and the
assembly drawing.

What the machine gate (`sim/gate.py`, `sim/results/`) proved is the
circuit; what the order gate proves is that the files are the circuit's.
What neither can show is in `docs/audit.md` section 6: a part that does
not match its usual drawing, the supply's drop along the ribbon, hands.
That is what the pilot is for.

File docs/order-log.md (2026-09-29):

# The order: how it got here

What `docs/order-1.md` said before it was rewritten on 2026-09-29, kept for
the record. Nothing here is current: the boards, the counts and the parts
to buy are in `docs/order-1.md`, generated from the routed boards.

## Why cards (2026-09-10, D042)

The machine was first drawn as nine large boards. JLCPCB's quotes for
those, 2-layer, five pieces each:

| Board as it was | Size (mm) | Quote |
|---|---|---|
| Sequencer | 449 x 470 | $258 + $93 shipping |
| Sequencer, matrix turned | 290 x 520 | $153 + $74 shipping |
| Memory | 368 x 377 | $135 + $74 shipping |
| Registers | 266 x 285 | $49 + $30 shipping |

About $1,300 for the machine at five of each. As 100 x 100 mm cards the
same machine is on the fab's cheapest tier, $2 to $4 for five, plus the
sequencer. These tier prices are not quotes: a quote is what the fab's
calculator says for the uploaded files.

## What went wrong with the first version of the order document

- It said "7129 parts on 26 boards". 7129 parts are right; 26 is the
  number of designs. 52 boards are built (eight memory slot cards and
  twenty program cards are one design each).
- It said "buy the buy column" and had no such column, and no spares.
- It said "45 to 50 sockets" for 53 headers, "about 6 m" of ribbon where
  `mounting.md` said 7 m per ribbon, and "four jumper caps per page" where
  a program card has six jumpers and a memory slot card three.
- It named a banana socket (Hirschmann BIL 20) whose drawing had not been
  read, and before that a Cliff S16, which is a different kind of part.
- Its checklist had grown into a wall of text with the history of each
  check in it. The history is here and in `docs/audit.md`.

## The checks, in the order they were learned (2026-09-28)

1. The coupon's project file had lost its design rules to a schematic
   rebuild; kicad-cli then judged the board by KiCad's defaults. Found only
   because the DRC was re-run on the committed board. Since then the order
   gate (`sim/order_check.py`) is run on the commit, not remembered.
2. The hub's first route put CLK 0.17 mm from the +5V socket's copper
   ring, under the socket's nut, with the DRC content at 0.15 mm. The gate's
   `clamp` check came of that: no copper of another net where hardware is
   clamped on the board.
3. The checks had run on the three pilot cards only. Since `5b2a0bd` every
   check runs on all 26 boards; `docs/audit.md` is the record.
4. The ribbon's route could not be built as drawn (an IDC socket lies
   across its ribbon). The headers went to the back of the boards (D059,
   D062) without a track moving; `sim/board_diff.py` is the proof.

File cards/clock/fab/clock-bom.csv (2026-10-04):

Reference | Value | Footprint | QUANTITY
C1 | 100n | Capacitor_THT:C_Disc_D5.0mm_W2.5mm_P2.50mm | 1
C2 | 10u | Capacitor_THT:CP_Radial_D5.0mm_P2.00mm | 1
C3 | 47n | Capacitor_THT:C_Disc_D5.0mm_W2.5mm_P2.50mm | 1
C4,C6 | 2.2u | Capacitor_THT:CP_Radial_D5.0mm_P2.00mm | 2
C5 | 2.2n | Capacitor_THT:C_Disc_D5.0mm_W2.5mm_P2.50mm | 1
D1,D2 | LED | LED_THT:LED_D3.0mm | 2
D3,D4 | 1N4148 | Diode_THT:D_DO-35_SOD27_P7.62mm_Horizontal | 2
J1 | BUS | Connector_IDC:IDC-Header_2x32_P2.54mm_Vertical | 1
J2 | SLOW | Connector_PinHeader_2.54mm:PinHeader_1x02_P2.54mm_Vertical | 1
Q1-Q18 | 2N7000 | Package_TO_SOT_THT:TO-92_Inline_Wide | 18
R1 | 4.7k | Resistor_THT:R_Axial_DIN0207_L6.3mm_D2.5mm_P5.08mm_Vertical | 1
R2-R9,R13 | 47k | Resistor_THT:R_Axial_DIN0207_L6.3mm_D2.5mm_P5.08mm_Vertical | 9
R10-R12,R15,R18 | 1k | Resistor_THT:R_Axial_DIN0207_L6.3mm_D2.5mm_P5.08mm_Vertical | 5
R14 | 10k | Resistor_THT:R_Axial_DIN0207_L6.3mm_D2.5mm_P5.08mm_Vertical | 1
R16,R19-R21 | 100k | Resistor_THT:R_Axial_DIN0207_L6.3mm_D2.5mm_P5.08mm_Vertical | 4
R17,R22 | 1Meg | Resistor_THT:R_Axial_DIN0207_L6.3mm_D2.5mm_P5.08mm_Vertical | 2
R23,R24 | 100 | Resistor_THT:R_Axial_DIN0207_L6.3mm_D2.5mm_P5.08mm_Vertical | 2
RV1 | 1M | nibble:Potentiometer_Bourns_PTV09A-4_Single_Vertical | 1
SW1 | RUN | Button_Switch_THT:SW_DIP_SPSTx01_Slide_9.78x4.72mm_W7.62mm_P2.54mm | 1

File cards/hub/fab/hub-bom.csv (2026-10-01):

Reference | Value | Footprint | QUANTITY
C1,C4 | 100n | Capacitor_THT:C_Disc_D5.0mm_W2.5mm_P2.50mm | 2
C2 | 100u | Capacitor_THT:CP_Radial_D5.0mm_P2.00mm | 1
D1 | LED | LED_THT:LED_D3.0mm | 1
D2 | 1N4735A | Diode_THT:D_DO-41_SOD81_P10.16mm_Horizontal | 1
D3 | 1N5408 | Diode_THT:D_DO-201AD_P15.24mm_Horizontal | 1
F1 | 1.5A | Fuse:Fuse_BelFuse_0ZRE0150FF_L23.4mm_W5.3mm | 1
J1 | BENCH +5V | nibble:Banana_CalTest_CT3151V1_Vertical | 1
J2 | BENCH GND | nibble:Banana_CalTest_CT3151V1_Vertical | 1
J3,J4 | BUS | Connector_IDC:IDC-Header_2x32_P2.54mm_Vertical | 2
Q1 | BT151-500R | Package_TO_SOT_THT:TO-220-3_Vertical | 1
R1 | 1k | Resistor_THT:R_Axial_DIN0207_L6.3mm_D2.5mm_P5.08mm_Vertical | 1
R2-R5 | 10k | Resistor_THT:R_Axial_DIN0207_L6.3mm_D2.5mm_P5.08mm_Vertical | 4
R6-R13 | 220k | Resistor_THT:R_Axial_DIN0207_L6.3mm_D2.5mm_P5.08mm_Vertical | 8
R14 | 100 | Resistor_THT:R_Axial_DIN0207_L6.3mm_D2.5mm_P5.08mm_Vertical | 1
TP1 | BUS0# | TestPoint:TestPoint_Loop_D2.50mm_Drill1.0mm | 1
TP2 | BUS1# | TestPoint:TestPoint_Loop_D2.50mm_Drill1.0mm | 1
TP3 | BUS2# | TestPoint:TestPoint_Loop_D2.50mm_Drill1.0mm | 1
TP4 | BUS3# | TestPoint:TestPoint_Loop_D2.50mm_Drill1.0mm | 1
TP5 | CLK | TestPoint:TestPoint_Loop_D2.50mm_Drill1.0mm | 1
TP6 | RST | TestPoint:TestPoint_Loop_D2.50mm_Drill1.0mm | 1

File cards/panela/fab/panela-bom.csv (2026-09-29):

Reference | Value | Footprint | QUANTITY
C1 | 100n | Capacitor_THT:C_Disc_D5.0mm_W2.5mm_P2.50mm | 1
C2 | 10u | Capacitor_THT:CP_Radial_D5.0mm_P2.00mm | 1
D1-D24 | LED | LED_THT:LED_D3.0mm | 24
J1 | BUS | Connector_IDC:IDC-Header_2x32_P2.54mm_Vertical | 1
Q1-Q28 | 2N7000 | Package_TO_SOT_THT:TO-92_Inline_Wide | 28
R1-R24 | 1k | Resistor_THT:R_Axial_DIN0207_L6.3mm_D2.5mm_P5.08mm_Vertical | 24
R25-R28 | 47k | Resistor_THT:R_Axial_DIN0207_L6.3mm_D2.5mm_P5.08mm_Vertical | 4
R29-R46 | 1Meg | Resistor_THT:R_Axial_DIN0207_L6.3mm_D2.5mm_P5.08mm_Vertical | 18
R47-R64 | 10k | Resistor_THT:R_Axial_DIN0207_L6.3mm_D2.5mm_P5.08mm_Vertical | 18
SW1 | A0 A1 A2 A3 B0 B1 B2 B3 (switch ON = 1) | Button_Switch_THT:SW_DIP_SPSTx08_Slide_9.78x22.5mm_W7.62mm_P2.54mm | 1
SW2 | SUB EO AI AO BI BO BA AB | Button_Switch_THT:SW_DIP_SPSTx08_Slide_9.78x22.5mm_W7.62mm_P2.54mm | 1

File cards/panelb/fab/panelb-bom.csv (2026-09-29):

Reference | Value | Footprint | QUANTITY
C1 | 100n | Capacitor_THT:C_Disc_D5.0mm_W2.5mm_P2.50mm | 1
C2 | 10u | Capacitor_THT:CP_Radial_D5.0mm_P2.00mm | 1
C3,C4 | 1u | Capacitor_THT:CP_Radial_D5.0mm_P2.00mm | 2
D1-D16 | LED | LED_THT:LED_D3.0mm | 16
D17,D18 | 1N4148 | Diode_THT:D_DO-35_SOD27_P7.62mm_Horizontal | 2
J1 | BUS | Connector_IDC:IDC-Header_2x32_P2.54mm_Vertical | 1
Q1-Q20 | 2N7000 | Package_TO_SOT_THT:TO-92_Inline_Wide | 20
R1-R16,R18,R20 | 1k | Resistor_THT:R_Axial_DIN0207_L6.3mm_D2.5mm_P5.08mm_Vertical | 18
R17,R19 | 47k | Resistor_THT:R_Axial_DIN0207_L6.3mm_D2.5mm_P5.08mm_Vertical | 2
R21-R36,R56,R61 | 1Meg | Resistor_THT:R_Axial_DIN0207_L6.3mm_D2.5mm_P5.08mm_Vertical | 18
R37-R53,R58 | 10k | Resistor_THT:R_Axial_DIN0207_L6.3mm_D2.5mm_P5.08mm_Vertical | 18
R54,R59 | 220k | Resistor_THT:R_Axial_DIN0207_L6.3mm_D2.5mm_P5.08mm_Vertical | 2
R55,R60 | 100k | Resistor_THT:R_Axial_DIN0207_L6.3mm_D2.5mm_P5.08mm_Vertical | 2
R57,R62 | 100 | Resistor_THT:R_Axial_DIN0207_L6.3mm_D2.5mm_P5.08mm_Vertical | 2
SW1 | OI IO II PCE PCL FI HLT MAI (switch ON = 1) | Button_Switch_THT:SW_DIP_SPSTx08_Slide_9.78x22.5mm_W7.62mm_P2.54mm | 1
SW2 | MI MO WRL WRH ONE F0 F1 INP | Button_Switch_THT:SW_DIP_SPSTx08_Slide_9.78x22.5mm_W7.62mm_P2.54mm | 1
SW3 | CLK | Button_Switch_THT:SW_PUSH_6mm | 1
SW4 | RST | Button_Switch_THT:SW_PUSH_6mm | 1

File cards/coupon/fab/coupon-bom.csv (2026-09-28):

Reference | Value | Footprint | QUANTITY
C1 | 100n | Capacitor_THT:C_Disc_D5.0mm_W2.5mm_P2.50mm | 1
C2 | 10u | Capacitor_THT:CP_Radial_D5.0mm_P2.00mm | 1
C3 | 47n | Capacitor_THT:C_Disc_D5.0mm_W2.5mm_P2.50mm | 1
D1 | LED | LED_THT:LED_D3.0mm | 1
D2,D3 | 1N4148 | Diode_THT:D_DO-35_SOD27_P7.62mm_Horizontal | 2
J1 | IN N1 N2 N3 RST GND | Connector_PinHeader_2.54mm:PinHeader_1x06_P2.54mm_Vertical | 1
J2 | +5V GND | Connector_PinHeader_2.54mm:PinHeader_1x02_P2.54mm_Vertical | 1
J3 | BUS | Connector_IDC:IDC-Header_2x32_P2.54mm_Vertical | 1
Q1-Q57 | 2N7000 | Package_TO_SOT_THT:TO-92_Inline_Wide | 57
R1,R48,R52 | 10k | Resistor_THT:R_Axial_DIN0207_L6.3mm_D2.5mm_P5.08mm_Vertical | 3
R2-R21,R23-R37,R47 | 47k | Resistor_THT:R_Axial_DIN0207_L6.3mm_D2.5mm_P5.08mm_Vertical | 36
R22,R39 | 4.7k | Resistor_THT:R_Axial_DIN0207_L6.3mm_D2.5mm_P5.08mm_Vertical | 2
R38,R41,R49 | 1k | Resistor_THT:R_Axial_DIN0207_L6.3mm_D2.5mm_P5.08mm_Vertical | 3
R40 | 3.3k | Resistor_THT:R_Axial_DIN0207_L6.3mm_D2.5mm_P5.08mm_Vertical | 1
R42-R46 | 1Meg | Resistor_THT:R_Axial_DIN0207_L6.3mm_D2.5mm_P5.08mm_Vertical | 5
R50 | 100k | Resistor_THT:R_Axial_DIN0207_L6.3mm_D2.5mm_P5.08mm_Vertical | 1
R51 | 100 | Resistor_THT:R_Axial_DIN0207_L6.3mm_D2.5mm_P5.08mm_Vertical | 1
R53 | 220k | Resistor_THT:R_Axial_DIN0207_L6.3mm_D2.5mm_P5.08mm_Vertical | 1
TP1 | TP_RING | TestPoint:TestPoint_Loop_D2.50mm_Drill1.0mm | 1
TP2 | RING0 | TestPoint:TestPoint_Loop_D2.50mm_Drill1.0mm | 1
TP3 | TP_FO1 | TestPoint:TestPoint_Loop_D2.50mm_Drill1.0mm | 1
TP4 | TP_FO10 | TestPoint:TestPoint_Loop_D2.50mm_Drill1.0mm | 1
TP5 | TP_NAND | TestPoint:TestPoint_Loop_D2.50mm_Drill1.0mm | 1
TP6 | TP_NOR | TestPoint:TestPoint_Loop_D2.50mm_Drill1.0mm | 1
TP7 | TP_BUS | TestPoint:TestPoint_Loop_D2.50mm_Drill1.0mm | 1
TP8 | TP_VTO | TestPoint:TestPoint_Loop_D2.50mm_Drill1.0mm | 1
TP9 | X | TestPoint:TestPoint_Loop_D2.50mm_Drill1.0mm | 1
TP10 | TP_OSC | TestPoint:TestPoint_Loop_D2.50mm_Drill1.0mm | 1
TP11 | TP_Q | TestPoint:TestPoint_Loop_D2.50mm_Drill1.0mm | 1
TP12 | TP_DRV | TestPoint:TestPoint_Loop_D2.50mm_Drill1.0mm | 1
TP13 | TP_ROM | TestPoint:TestPoint_Loop_D2.50mm_Drill1.0mm | 1
TP14 | GND | TestPoint:TestPoint_Loop_D2.50mm_Drill1.0mm | 1
TP15 | +5V | TestPoint:TestPoint_Loop_D2.50mm_Drill1.0mm | 1

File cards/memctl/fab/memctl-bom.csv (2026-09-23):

Reference | Value | Footprint | QUANTITY
C1 | 100n | Capacitor_THT:C_Disc_D5.0mm_W2.5mm_P2.50mm | 1
C2 | 10u | Capacitor_THT:CP_Radial_D5.0mm_P2.00mm | 1
C3 | 2.2n | Capacitor_THT:C_Disc_D5.0mm_W2.5mm_P2.50mm | 1
D1-D4 | LED | LED_THT:LED_D3.0mm | 4
J1 | BUS | Connector_IDC:IDC-Header_2x32_P2.54mm_Vertical | 1
J2 | LINK | Connector_IDC:IDC-Header_2x06_P2.54mm_Vertical | 1
Q1-Q57 | 2N7000 | Package_TO_SOT_THT:TO-92_Inline_Wide | 57
R1,R3-R11,R13-R16,R18-R21,R23-R26,R28 | 47k | Resistor_THT:R_Axial_DIN0207_L6.3mm_D2.5mm_P5.08mm_Vertical | 23
R2 | 10k | Resistor_THT:R_Axial_DIN0207_L6.3mm_D2.5mm_P5.08mm_Vertical | 1
R12,R17,R22,R27,R29-R32,R34 | 22k | Resistor_THT:R_Axial_DIN0207_L6.3mm_D2.5mm_P5.08mm_Vertical | 9
R33 | 4.7k | Resistor_THT:R_Axial_DIN0207_L6.3mm_D2.5mm_P5.08mm_Vertical | 1
R35-R38 | 1k | Resistor_THT:R_Axial_DIN0207_L6.3mm_D2.5mm_P5.08mm_Vertical | 4
R39 | 100k | Resistor_THT:R_Axial_DIN0207_L6.3mm_D2.5mm_P5.08mm_Vertical | 1

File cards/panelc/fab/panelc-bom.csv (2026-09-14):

Reference | Value | Footprint | QUANTITY
C1 | 100n | Capacitor_THT:C_Disc_D5.0mm_W2.5mm_P2.50mm | 1
C2 | 10u | Capacitor_THT:CP_Radial_D5.0mm_P2.00mm | 1
D1-D16 | LED | LED_THT:LED_D3.0mm | 16
J1 | BUS | Connector_IDC:IDC-Header_2x32_P2.54mm_Vertical | 1
Q1-Q32 | 2N7000 | Package_TO_SOT_THT:TO-92_Inline_Wide | 32
R1-R16 | 1k | Resistor_THT:R_Axial_DIN0207_L6.3mm_D2.5mm_P5.08mm_Vertical | 16
R17-R24 | 47k | Resistor_THT:R_Axial_DIN0207_L6.3mm_D2.5mm_P5.08mm_Vertical | 8
R25-R36 | 1Meg | Resistor_THT:R_Axial_DIN0207_L6.3mm_D2.5mm_P5.08mm_Vertical | 12
R37-R40 | 10k | Resistor_THT:R_Axial_DIN0207_L6.3mm_D2.5mm_P5.08mm_Vertical | 4
SW1 | DATA (input port, read by IN) | Button_Switch_THT:SW_DIP_SPSTx04_Slide_9.78x12.34mm_W7.62mm_P2.54mm | 1

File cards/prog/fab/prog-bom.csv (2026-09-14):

Reference | Value | Footprint | QUANTITY
C1 | 100n | Capacitor_THT:C_Disc_D5.0mm_W2.5mm_P2.50mm | 1
C2 | 10u | Capacitor_THT:CP_Radial_D5.0mm_P2.00mm | 1
D1-D5 | LED | LED_THT:LED_D3.0mm | 5
D6-D37 | 1N4148 | Diode_THT:D_DO-35_SOD27_P2.54mm_Vertical_AnodeUp | 32
J1 | BUS | Connector_IDC:IDC-Header_2x32_P2.54mm_Vertical | 1
J2 | P7 | Connector_PinHeader_2.54mm:PinHeader_1x03_P2.54mm_Vertical | 1
J3 | P6 | Connector_PinHeader_2.54mm:PinHeader_1x03_P2.54mm_Vertical | 1
J4 | P5 | Connector_PinHeader_2.54mm:PinHeader_1x03_P2.54mm_Vertical | 1
J5 | P4 | Connector_PinHeader_2.54mm:PinHeader_1x03_P2.54mm_Vertical | 1
J6 | G3 | Connector_PinHeader_2.54mm:PinHeader_1x03_P2.54mm_Vertical | 1
J7 | G2 | Connector_PinHeader_2.54mm:PinHeader_1x03_P2.54mm_Vertical | 1
Q1-Q41 | 2N7000 | Package_TO_SOT_THT:TO-92_Inline_Wide | 41
R1-R16,R18,R20,R22 | 47k | Resistor_THT:R_Axial_DIN0207_L6.3mm_D2.5mm_P5.08mm_Vertical | 19
R17,R19,R21,R23 | 3.3k | Resistor_THT:R_Axial_DIN0207_L6.3mm_D2.5mm_P5.08mm_Vertical | 4
R24-R28 | 1k | Resistor_THT:R_Axial_DIN0207_L6.3mm_D2.5mm_P5.08mm_Vertical | 5
SW1 | WORD 0 | Button_Switch_THT:SW_DIP_SPSTx08_Slide_9.78x22.5mm_W7.62mm_P2.54mm | 1
SW2 | WORD 1 | Button_Switch_THT:SW_DIP_SPSTx08_Slide_9.78x22.5mm_W7.62mm_P2.54mm | 1
SW3 | WORD 2 | Button_Switch_THT:SW_DIP_SPSTx08_Slide_9.78x22.5mm_W7.62mm_P2.54mm | 1
SW4 | WORD 3 | Button_Switch_THT:SW_DIP_SPSTx08_Slide_9.78x22.5mm_W7.62mm_P2.54mm | 1

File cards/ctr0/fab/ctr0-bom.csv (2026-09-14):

Reference | Value | Footprint | QUANTITY
C1 | 100n | Capacitor_THT:C_Disc_D5.0mm_W2.5mm_P2.50mm | 1
C2 | 10u | Capacitor_THT:CP_Radial_D5.0mm_P2.00mm | 1
D1,D2 | LED | LED_THT:LED_D3.0mm | 2
J1 | BUS | Connector_IDC:IDC-Header_2x32_P2.54mm_Vertical | 1
J2 | OUT | Connector_IDC:IDC-Header_2x03_P2.54mm_Vertical | 1
J3 | LINK | Connector_IDC:IDC-Header_2x06_P2.54mm_Vertical | 1
Q1-Q62 | 2N7000 | Package_TO_SOT_THT:TO-92_Inline_Wide | 62
R1,R6-R23,R25,R26,R28-R32 | 47k | Resistor_THT:R_Axial_DIN0207_L6.3mm_D2.5mm_P5.08mm_Vertical | 26
R2-R4 | 10k | Resistor_THT:R_Axial_DIN0207_L6.3mm_D2.5mm_P5.08mm_Vertical | 3
R5,R24,R27 | 22k | Resistor_THT:R_Axial_DIN0207_L6.3mm_D2.5mm_P5.08mm_Vertical | 3
R33,R34 | 1k | Resistor_THT:R_Axial_DIN0207_L6.3mm_D2.5mm_P5.08mm_Vertical | 2

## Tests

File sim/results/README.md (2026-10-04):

# Gate results kept on purpose

`sim/out/` is scratch and ignored by git; the tables that close a step of
`docs/cards.md` are copied here, unedited, from `out/gate_<boards>.md` as
`sim/gate.py` wrote them (the queue script copies each stage's table to
`out/<stage>.md`).

| File | What |
|---|---|
| `gate25_smoke_t12.md` | Step 9 smoke, 2026-09-23: the first 12 ticks of all thirteen programs at TYP on the whole card deck with the D053 clock card and the D054 memory control card, power-up start (`.tran ... uic`) |
| `gate25_TYP.md` | Step 9, 2026-09-23/24: all thirteen programs to their halt at TYP, same deck |
| `gate25_corners.md` | Step 9, 2026-09-24/26: fib, alu, gcd, list, logic, call at LO, HI, MIX seed 1 and MIX seed 2, same deck |
| `gate_clk_corners_oldclock.md` | The same corner gate on the cards before D053/D054, where gcd, list and logic failed at MIX seed 2 |
| `gate25_nop.md` | Added corners, 2026-09-26: nop at LO and HI, same deck |
| `gate25_500pF_HI.md` | Added corners, 2026-09-26: the six corner programs at HI with 500 pF on every bus line (`CABLE_PF=500`), same deck |
| `gate25_vdd45.md` | Added corners, 2026-09-26/27: the six corner programs at TYP and HI with the supply at 4.5 V (`VDD=4.5`), same deck |
| `gate25_cross.md` | Added corners, 2026-09-27: the six corner programs at TYP and HI with 100 pF between neighbouring bus lines (`CROSS_PF=100`), same deck |
| `gate25_vdd425.md` | Added corners, 2026-09-27: fib, logic and call at HI with the supply at 4.25 V (`VDD=4.25`), same deck. The first run of this stage failed fib on the scorer, not the machine: `machine.py` read CLK against a fixed 3.5 V and the card's CLK high is (VDD − a diode) × 10/11, 3.38 V at 4.25 V; every level in the scorer and the switch counter's bridges is a fraction of VDD since commit 1480db7, and the stage was rerun on the fixed scorer |
| `gate25_mix34.md` | Added corners, 2026-09-27/28: the six corner programs at MIX seeds 3 and 4, same deck |
| `coupon_expected.md` | The coupon card, 2026-09-28 (D056): what the bench should read at each test loop, from `tb_coupon.py kicad --all` on the routed card's export at TYP, LO, HI and MIX seeds 1..3 (written by the testbench, not by `gate.py`) |
| `sweep_por.md` | The reset-release sweep, 2026-09-28/29 (`sweep_por.py`): fib for 12 ticks on the whole card deck with the clock card's power-on reset released at 13 places against the clock edge, 10 us apart, at TYP and MIX seeds 1 and 2. 37 of 39 pass. The two that fail are the mixed corners with the clock edge 9 and 10 us after the release; the runs on either side of them, at 0 and 20 us, pass. Scored again from the saved data: at MIX1 the first opcode is not latched and the first instruction runs as another one; at MIX2 the step ring starts with two steps active and never recovers. At TYP every card lets go at the same voltage and nothing fails. MIX2 released 3.8 ms after power-on, a period and a half of its clock, not the 20 ms asked for: `sweep_por_mix2_late.md` is that corner again with a later release, and says the same |
| `sweep_por_mix2_late.md` | The MIX2 corner of the reset sweep again, 2026-09-29, with the release asked for at 35 ms (`sweep_por.py --corners MIX2 --early 35`): it came at 21 ms, eight and a half clock periods after power-on. 12 of 13 pass; the one that fails is the clock edge 9 us after the release, 64 mismatches, as in the first sweep, with the runs at 2 us before and 20 us after it passing. The early release of the first sweep changed nothing |
| `reset_release.md` | The hold-off on the clock card alone, 2026-09-29 (`tb_reset_release.py`, D064): 24 cases, 504 releases of RST. With the two parts CLK is low at every release and its first edge comes 1.3 ms or more after it, a whole pulse; without them an edge falls as near as 1 us. 24 of 24 pass. The two parts are in the deck, not on the card |
| `starts_hold.md` | The machine's starts with the hold-off in the deck, 2026-09-29 (`starts_hold.py`, `HOLD=1`, D064): fib for 12 ticks on the whole card deck. The 46 starts of the reset sweep again, each at the release it had (the three that failed pass); a start at LO, HI, MIX 3 and MIX 4; twelve presses of the panel's RST button while the machine runs. The first clock edge comes 1.40 to 5.74 ms after the release. 62 of 62 pass |
| `gate26_cross.md` | Gate 26 (the clock card with the hold-off, D064), crosstalk, 2026-09-29/30: the six corner programs at TYP and HI with 100 pF between the lines that are neighbours on the ribbon with the header on the back (`CROSS_PF=100`, D062), the two parts in the deck (`HOLD=1`; the deck of the card with them on it is the same element for element). 12 of 12 pass |
| `gate26_smoke.md` | Gate 26 (the clock card with the hold-off on it, D064, `e65ca46`), smoke, 2026-09-30: the first 12 ticks of all thirteen programs at TYP on the whole card deck, power-up start. 13 of 13 pass |
| `gate26_TYP.md` | Gate 26 (the clock card with the hold-off on it, D064, `e65ca46`), all programs at TYP, 2026-10-01: all thirteen programs to their halt on the whole card deck, power-up start. 13 of 13 pass, 0 mismatches |
| `gate26_corners.md` | Gate 26 (the clock card with the hold-off on it, D064, `e65ca46`), corners, 2026-10-01/02: the six corner programs (fib, alu, gcd, list, logic, call) to their halt at LO, HI, MIX 1 and MIX 2 on the whole card deck, power-up start. 24 of 24 pass, 0 mismatches; logic at MIX 8.6 h of ngspice |
| `gate26_nop.md` | Gate 26 (D064, `e65ca46`), nop, 2026-10-02: the nop program to its halt at LO and HI. 2 of 2 pass |
| `gate26_500pF_HI.md` | Gate 26 (D064, `e65ca46`), 500 pF cables at HI, 2026-10-02/03: the six corner programs to their halt at HI with 500 pF on every bus line (`CABLE_PF=500`, the ribbon's worst case before the 800 pF stage). 6 of 6 pass, 0 mismatches |
| `gate26_vdd45.md` | Gate 26 (D064, `e65ca46`), 4.5 V supply, 2026-10-03: the six corner programs to their halt at TYP and HI with the rail at 4.5 V (`VDD=4.5`). 12 of 12 pass, 0 mismatches |
| `gate26_vdd425.md` | Gate 26 (D064, `e65ca46`), 4.25 V supply, 2026-10-03: fib, logic and call to their halt at HI with the rail at 4.25 V (`VDD=4.25`). 3 of 3 pass, 0 mismatches |
| `gate26_mix34.md` | Gate 26 (D064, `e65ca46`), MIX 3 and 4, 2026-10-03/04: the six corner programs to their halt at MIX seeds 3 and 4. 12 of 12 pass, 0 mismatches. With this the eight stages of gate 26 are in: 85 of 85 |
| `gate26_800pF_HI.md` | Gate 26 (D064, `e65ca46`), 800 pF cables at HI, 2026-10-04: the six corner programs to their halt at HI with 800 pF on every bus line (`CABLE_PF=800`: the two-sided panel's 7.4 m of ribbon with signal beside signal, `docs/mounting.md`). 6 of 6 pass, 0 mismatches; logic 5.5 h of ngspice. Gate 26 in all: 91 of 91 |
| `rst_neighbour.md` | The reset line beside BUS1#, 2026-09-28 (D062): with the bus header on the back RST has one ground neighbour on the ribbon, not two; the bump it picks up when BUS1# is released, with every gate the routed boards hang on the two lines, against the coupling and a capacitor at the hub (written by `tb_rst_neighbour.py`) |
| `crowbar.md` | The hub's crowbar and reverse diode, 2026-09-28 (D061): the models against their datasheets, which zener and gate resistor, and the rail in every way the voltage can arrive (turned up, switched on at 30 V, plugged in live, leads crossed), with the heat in the SCR (written by `tb_crowbar.py`). The parts are not on the hub yet |

The four stages before `gate25_vdd425.md` ran on the scorer before 1480db7.
At 5 V its fixed levels were the same fractions of VDD, so the tables stand.
At 4.5 V the switch counter's reset bridge (3.5/4.0 V, against a reset high
of 3.7 V) never read high, so the counter was not cleared by the card's reset
and started from its flip-flops' initial state, 0, the same state; the switch
sequence those runs saw is the one they were scored against.

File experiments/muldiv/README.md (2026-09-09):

# Experiment: multiply and divide on the RTL calculator

Done on 2026-09-09 as a test of AI schematic-level design, before the CPU
direction was chosen. Not built, and not on the roadmap.

The origin sheet was extended with `muldiv.kicad_sch` (a 6-bit work register,
a five-state sequencer, shift-add multiply and restoring divide reusing the
origin's adder; 480 extra 2N3904s) and `testbench.kicad_sch` (clock, keypad and
op-code stimuli). The root sheet here is the origin sheet with the encoder
inverters moved, the register inputs muxed, and the two origin bugs fixed.

Proof: `sim_results/` holds the kicad-cli exported netlist, a 16-operation
transient test and an exhaustive 256-case sweep (all pass), the plots, and a
report. `tools/` regenerates everything from `logic.py`; read `tools/README.md`.

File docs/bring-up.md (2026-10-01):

# Bring-up: the whole machine, one card at a time

Rewritten 2026-09-11 for the cards (D042, `cards.md`). The order of testing
and the tests carry over from the nine-board plan: a register bit card is
tested the way the register board was, one bit at a time, and a machine
that already works gets one more card at each step, so a failure points at
one card.

The pilot order (docs/order-1.md, D055) brings the coupon, one register
bit card and the hub: sections 1, 2 and 4 below, with a short ribbon and
the bench supply in place of the panel. Without the panel nothing pulls
the control lines down (its 1 Meg pull-downs), so on the hub's second
header jumper the register's control lines and CLK and RST to ground, raise
one at a time through 1k from +5V, and read the bus bit and the A, B, OUT
LEDs; the card's currents are the table's. The
second order brings the sequencer board and the other cards: 25 designs,
most in fives. Solder and test them in the order below. The panel cards are the test fixture for every other card: a switch
on every control line, an LED on every bus line, buttons for CLK and RST.
Until the clock card is in, the CLK button is the clock. Until the
sequencer is in, the switches are the sequencer.

## Tools you need before the cards arrive

- Bench supply with current limit (5.0 V, limit 300 mA for the first power-on of each board; 1.5 A for the whole machine into the hub's banana sockets, D052, D058) with a pair of banana-to-banana leads. The machine has no other power entry (D057).
- Multimeter with a continuity beeper.
- 8-channel USB logic analyser (any Saleae-compatible clone) and Sigrok/PulseView, or a scope.
- Temperature-controlled iron, 0.6 mm solder, flux, brass wool, wick.
- Anti-static wrist strap: 2N7000 gates are static-sensitive until soldered, and the bus lines of a finished card go straight to gates: strap on whenever a card or a ribbon is handled.
- Flush cutters, tweezers, a board holder, a lead-bending jig for TO-92 (the footprint is the 2.54 mm wide inline one).
- The frame (docs/mounting.md) can wait; cards test fine flat on the bench on a short ribbon with a few sockets crimped on.

## Soldering, every card

Every card has a drawing, `fab/<card>-assembly.svg`: which resistor is not
the common value, which way round each diode, LED and capacitor goes. The
boards print no values.

Resistors first (all standing upright on 5.08 mm, the body on one pad, the
bare lead bent over to the other), then diodes, then capacitors, link
headers, jumpers and switches, then LEDs (the short leg, the cathode, in the
square pad), transistors last with the strap on.

**The 64-pin bus header goes on the back of the board** (D059), with its
notch toward the top edge (on the hub both headers, the lower one too): the
back has the header's outline with `HEADER HERE` and `NOTCH TO TOP`, the
front only the pin numbers. Its pins are soldered on the front. The link
headers (2x3, 2x6) and the jumpers stay on the front. A header on the wrong
face puts every signal on the wrong conductor of the ribbon. Before
the transistors go in, power the card and check that no pull-up is
shorted: with the resistors and LEDs only, the current is under 1 mA.
After the transistors: about 0.1 mA per gate that is on, so tens of mA for
a full card, never hundreds. If it is more than 30 mA above the number in
the table, power off and look for a bridge between the three TO-92 pads.

| Card | Transistors | Expected current (5 V) | Soldering time |
|---|---|---|---|
| coupon | 57 | 5 to 8 mA with IN low, 11 to 14 mA with IN high (the oscillator's 1k driver runs always; the LED and the row when IN is up) | 1.5 h |
| hub | 0 | under 6 mA (the LED, and half a milliamp in the crowbar's zener) | 1 h (the headers, the two sockets, the crowbar) |
| panel A, B, C | 28, 20, 32 | 5 to 40 mA depending on the LEDs lit; B 10 mA more, its two button drivers idle low through 1k (D053) | 2 h each |
| register bit | 99 | 5 to 12 mA | 2.5 h each |
| ALU bit | 66 to 73 | 4 to 9 mA | 2 h each |
| counter bit | 62 | 4 to 8 mA | 2 h each |
| memory control | 57 | 3 to 7 mA | 1.5 h |
| memory slots | 91 | 5 to 12 mA | 2.5 h each |
| program | 41 + 32 diodes | 3 to 6 mA | 1.5 h each |
| clock | 17 | 5 to 12 mA in RUN (the 1k CLK and RST drivers, D053) | 1 h |
| sequencer | 592 + 87 diodes | 30 to 70 mA | 12 h |

## 1. Coupon

Every cell the machine is built from, with a test loop on each (D056): it
measures the transistor and the cells in copper, which the simulation only
assumed. Power it from the bench supply on the 2-pin POWER header (5.00 V,
limit 300 mA), or from the bus header (pins 1-2 +5 V, 3-4 ground) once the
hub is trusted. Drive the inputs from the 6-pin INPUTS header: each has a
1 Meg pull-down, so an open pin is 0; a wire from the +5V loop is a 1. RST
open lets the flip-flop run. Clip a 3.3 nF capacitor from the DRV loop to
GND (the ribbon and seventeen cards' gates, as the clock card sees them)
and use a x10 probe: the expected numbers assume both.

The numbers to expect are in `sim/results/coupon_expected.md`, from
`sim/tb_coupon.py` on the routed card's own netlist at the model's three
threshold corners (0.8, 2.0, 3.0 V) and three mixed-threshold seeds; the
band is the lowest to the highest over those runs. What each loop stands
for and what a reading outside its band would mean:

| Measure | Loop | Expected (5 V, x10 probe) | What it stands for |
|---|---|---|---|
| Ring period | RING0 (the ring node), RING (buffered) | 6 to 24 us; a low-threshold ring swings only 1.6 to 3 V, and RING may then show nothing while RING0 runs | the gate delay of the 47k cell: the corner this batch of transistors sits at. Slower than the band: the cell is slower than any corner simulated |
| Rise 10-90 %, fan-out 1 and 10 | FO1, FO10 (IN toggled by hand or a 1 kHz square) | 10 to 12 us and 67 to 77 us | the pull-up against the gate capacitance with its Miller part: what every control line's rising edge costs. Slower than the band: the input capacitance is above the model's |
| Delay IN edge to FO1 / FO10 half way | FO1, FO10 | 5 to 6.5 us / 14 to 29 us | the same, as a delay |
| NAND and NOR output low, N1 N2 N3 = 111 | NAND, NOR | under 0.01 V | three transistors in series still pull low: every decoder's stack. Above 0.5 V: stop |
| Bus driver low, IN high | BUS | under 0.01 V (10k pull-up) | the register and ALU drivers against the hub's pull-up |
| Schmitt trip points | X | lower 0.8 to 3.0 V, upper 0.4 V above it | the clock card's Schmitt pair (the same parts): the hysteresis is 0.4 V whatever the threshold. No oscillation, or X stuck: the pair's dead point the design was meant to exclude |
| Oscillator period and duty | OSC | 1.6 to 2.6 ms, high 34 to 80 % | the clock card at its fastest setting (100k + 47 nF, the pot at zero) |
| Toggle flip-flop | Q with RST open | half the OSC rate, one Q edge per OSC rising edge | the master-slave cell of the counters and the sequencer, clocked by a real edge |
| Reset | Q with RST wired to +5V | 0 V between clock edges; at a rising clock edge a pulse of up to 4 V and 10 us can appear at some threshold mixes (the master's release racing the slave's copy; the machine's masters are closed at that moment) | the asynchronous reset of the counter and sequencer flops |
| Line driver edge into 3.3 nF | DRV (clip the capacitor on) | high 4.0 V (5 V less a diode, through 1.1k against 10k); rise 0.5 to 3.5 V in 6 to 8 us; fall 3.5 to 0.8 V in 45 to 55 us | the CLK edge every card sees and the RST release (D053); the capacitor's tolerance moves both by its own percentage |
| Threshold | VTO (a meter) | 0.9 to 3.0 V: about 0.1 V above this one transistor's threshold | Vgs(th) of one 2N7000 at 0.6 mA. Also measure twenty loose ones on a component tester or with a 4.7k and the meter: the spread of the batch is what MIX simulated |
| Program row | ROM | 4.5 V with IN low, 0 V with IN high | the M-line high through a row's diode into the hub's 220k (D048) |
| Supply current | the supply | 5 to 8 mA with IN low, 11 to 14 mA with IN high | about 0.1 mA per gate that is on, the oscillator's 1k driver half the time, the LED and the 3.3k row when IN is up |

A reading outside its band means the cell in copper is not the cell the
whole machine was simulated with. Stop there: the second order waits until
the model in `lib/2N7000.lib` is corrected to the measurement and the
machine gate (docs/cards.md step 9) is rerun on it. A low ring peak or a
blind RING loop is not a failure (read RING0); the reset pulse at a clock
edge is not a failure.

## 2. Hub

No logic. Check with the meter, nothing connected: no short between +5V
and ground on either header; every one of the 64 pins of the top header
beeps to the same pin of the bottom header; the four BUS pull-ups read 10k
to +5V; the eight M pull-downs read 220k to ground; the red banana
socket beeps to the fuse's first pad and, through the fuse, to header
pin 1; the black one to header pin 3. Plug the bench supply's leads into
the sockets (red +5V, black GND; 5.0 V, limit 300 mA): the power LED
lights, the current is under 6 mA. The sockets stand on four solder joints:
push a plug in with a finger behind the board.

The crowbar, once, before any card is on the ribbon: supply at 5.0 V, limit
at 0.5 A, nothing plugged into the hub's headers. Turn the voltage up
slowly. Somewhere between 6.3 and 7.8 V the supply drops into its current
limit and the rail reads about 0.8 V: the SCR has fired. Switch the output
off, set 5.0 V, switch on: 5 V again. If the rail follows the knob past
8 V, switch off: the zener or the SCR is in the wrong way round (the
assembly drawing has the square pads). With the machine running and the
limit at 1.5 A the supply cannot lift the rail above 7.5 V and the crowbar
may not fire at all: that is the limit doing the same job. Keep the limit
at 1.5 A; with it at 3 A or more a fired SCR overheats unless it has a
clip-on heatsink. Crimp the first ribbon: a short piece with three sockets for the
bench, then the two long ones for the panel (`mounting.md`: 3.7 m each).

Every ribbon, before it sees power: with nothing plugged into it but the
hub, beep each socket's pin 1 to the hub's pin 1 and its pin 64 to the
hub's pin 64, and check that pin 1 does not beep to pin 3. A socket
crimped the other way round, or a ribbon turned over at a fold, puts +5V
on a ground pin of every card after it (pins 1, 2 and 64 are +5V; 3, 4, 5,
7 and 63 ground, `bus-header.md`).

Plugging a 64-way socket takes 60 to 100 N and a card hangs on two screws
at mid-height: hold the card from the front, behind the header, with the
other hand. The same when pulling one off.

## 3. Panel A, B, C

Plug the three onto the ribbon with the hub. Every level switch that is ON
(slid to the right, toward its name; the boards print `ON >`) puts a 1 on
its line: the LED of that line lights on card A or B, and the meter reads
5 V on the header pin. Switch off: 0 V (the 1 Meg pull-down; 10k on CLK
and RST, D053). Card B: the CLK and RST buttons each give one clean
edge per press on the header (scope or logic analyser: no bounce after the
Schmitt trigger; the rise into the ribbon's few nF takes microseconds, the
fall through the 10k about 30 us); card C's DATA switches show on the
D3..D0 LEDs of card A only while INP is on (card B's switch): that is the
input port driving the bus. PC and M LEDs follow the PC and M lines, which
nothing drives yet.

## 4. Register bit cards

One card at a time, on the ribbon with the hub and the panel. The panel's
A and B switches sit on the registers' output lines, so leave them off
and drive the bus instead: DATA switch <i> on card C with INP on puts the
bit on the bus; raise AI, press CLK: the A<i> LED lights (the card's own
and panel A's). AO puts A back on the bus: the D<i> LED. Same
for B with BI, BO; BA copies A into B, AB copies B into A; OI loads OUT.
All four cards on the ribbon: any value through A and B, in both
directions. This is the register testbench's script done by hand; the
simulation ran it 113 steps at six corners.

## 5. ALU bit cards

The four cards side by side, the 2x3 links between them (IN of bit i+1 to
OUT of bit i), on the ribbon with the hub, panel and registers. Load A and
B through the panel, set F1 F0 (00 add, 01 and, 10 or, 11 xor), SUB, ONE;
raise EO: the result on the bus is on the D3..D0 LEDs, CF and ZF on card
A. Try 3 + 5, 9 + 9 (carry), 7 - 7 (zero), 0 - 1 (borrow, CF = 0). The
simulation did all 2304 cases at four corners.

## 6. Counter bit cards

Eight cards in a row, the 2x3 carry links between neighbours, the 2x6
ribbon from the sequencer's link header along all eight (not connected
yet: the sequencer is later). RST: all PC LEDs off. PCE on, press CLK: bit
0 lights; again: bit 1; the carry runs through the links. PCL with the
bus data switches (OPR comes from the sequencer later; for now the panel's
switches on the link ribbon's OPR lines): loads a jump target. RAI then
PCR: the return register. call.asm on the eight cards in the simulation
passed; the machine gate proves the rest.

## 7. Memory control and slot cards

Memory control on the ribbon, the 2x6 link ribbon from it along the eight
slot cards, each slot card's jumpers set to its pair (A3 A2 A1 = the
pair number 0..7 in binary, the centre pin to '1' where the bit is 1).
On the scope, probe CLKD (the top of the control card's 2.2 nF) and MPH
(the output of the NOR that reads CLK and CLKD): a pulse from each falling
edge of CLK, 60 to 350 us long (D054); the address latch and the write
happen inside it, in the middle of the tick, never at an edge. MAI with an address on the data
switches, then MI with a value: the cell LEDs of that slot show the value. Change the address, MO: the value comes
back on the bus. Fill all sixteen, read all sixteen (the testbench's
script). A slot that always reads another slot's value is a jumper on the
wrong side.

## 8. Program cards

Set a card's jumpers: P7..P4 the page, G3 G2 the word group, the centre pin
to '1' where the address bit is 1; card c holds words 4c..4c+3. Set the
switches of a short program (`sim/programs/count.asm` assembled by
`sim/emu.py` gives the words; a switch that is ON, to the right, is a 1,
bit 7 at the top). With the counter on the bus, PCE on and the CLK button:
each press moves PC by one, the card's R<n> LED shows the row, and the M
LEDs on panel C show the word. A blank word (all off) reads 0000 0000, NOP.

## 9. Clock card

RUN switch off, STEP: the panel's CLK button owns the line. RUN: the OSC
LED blinks and the CLK line runs at the pot's speed (500 Hz down to 40 Hz,
the SLOW jumper 10 Hz to 0.8 Hz); HLT high stops it a quarter of a
millisecond later, after the pulse in flight (D050). Power-on: RST high
for a tenth of a second, then low. On the scope, with the ribbon and the
cards on it (about 3 nF): CLK rises 0.5 to 3.5 V in under 10 us, RST falls
3.5 to 0.8 V in under 100 us (D053; the simulation says 6 and 45 us).
While RST is high the oscillator is held (D064: one transistor clamps its
timing capacitor), so CLK stays low through the release and its first
rising edge comes 1.3 to 5.7 ms after RST has fallen, at the fastest
setting; slower settings wait longer. On the scope: no CLK edge within a
millisecond of RST falling, after power-on and after the RST button. The
clock card reads the RST line, so the panel's button gets the same
hold-off. Without the hold-off the mixed-threshold corners started wrong
when an edge fell within 20 us of the release (`sim/results/sweep_por.md`);
with it every start passes (`sim/results/starts_hold.md`, 62 of 62). A
machine that still starts wrong is a card out of reset early: check the
RST pin of each card against the hub's.

With the whole machine running a program, RST on the scope at the far end
of the ribbon (its neighbour on the ribbon is BUS1# since the headers went
to the back, D062): bumps of up to half a volt each time the bus is
released are what the simulation says (0.28 to 0.43 V,
`sim/results/rst_neighbour.md`). Above 0.6 V, fit a 2.2 nF disc in the
hub's empty spot marked C-RST, beside the RST test loop (it halves the
bump, and RST then releases in 50 us instead of 20). Nothing goes there
otherwise.

## 10. Sequencer

The big board last, on the ribbon, its link ribbon to the counter cards.
Its own LEDs show the step and the instruction register. With the whole
machine on the bus and a program card set to count.asm, single-step with
the CLK button and compare every tick with the emulator's trace
(`python3 emu.py programs/count.asm --trace`): PC, the M word, the step,
the control lines on the panel B LEDs, A and B. Then RUN. Then every
program in `sim/programs`, which the machine gate ran at every corner
before the boards were ordered.

## When something is wrong

- A card draws too much: a bridge on a TO-92, or a transistor in
  backwards (the flat face is on the silk outline's flat side).
- A line reads 2 to 3 V: two cards driving it; one has a switch or a
  jumper wrong, or a link ribbon is one row off.
- A card works alone and fails on the ribbon: a socket crimped one row
  off, or pin 1 (the red edge) at the wrong end.
- The simulation numbers are the reference for every measurement here:
  `cards/README.md` says which run proved which card.

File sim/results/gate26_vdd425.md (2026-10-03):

# Machine gate: boards aluc,hubc,regc,seq,ctrc,memc,progc,pnl,clkc
Generated 2026-10-03 17:18 by sim/gate.py. Corners: HI; MIX seeds [1].

| program | corner | result | time |
|---|---|---|---|
| fib.asm | HI | pass: 127 ticks, 0 mismatches | 3358 s |
| logic.asm | HI | pass: 986 ticks, 0 mismatches | 20042 s |
| call.asm | HI | pass: 84 ticks, 0 mismatches | 2776 s |

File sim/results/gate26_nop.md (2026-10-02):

# Machine gate: boards aluc,hubc,regc,seq,ctrc,memc,progc,pnl,clkc
Generated 2026-10-02 16:43 by sim/gate.py. Corners: LO, HI; MIX seeds [1].

| program | corner | result | time |
|---|---|---|---|
| nop.asm | LO | pass: 33 ticks, 0 mismatches | 737 s |
| nop.asm | HI | pass: 33 ticks, 0 mismatches | 1299 s |

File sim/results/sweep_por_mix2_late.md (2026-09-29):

# Reset-release sweep: fib, 12 ticks, the whole card deck

Generated 2026-09-29 06:42 by sim/sweep_por.py. Boards aluc,hubc,regc,seq,ctrc,memc,progc,pnl,clkc. VDD 5 V.
The release is pulled to about 35 ms with POR_V0 (see the docstring); "edge" is where the nearest clock edge fell against the release as the scorer measured it,
positive after. The cards let go of their resets over the 45 us after the release, so an edge at 0 to +45 us is the straddle.

## MIX2: calibration release 22.325 ms, edge -1111 us, period 2.476 ms (pass); second calibration edge +327 us (pass), an asked shift arrives x1.1616

| wanted us | POR_V0 V | release ms | edge us | period ms | result | time |
|---|---|---|---|---|---|---|
| -40 | 3.0034 | 21.257 | -41 | 2.477 | pass: 12 ticks, 0 mismatches | 1078 s |
| -30 | 3.0034 | 21.247 | -31 | 2.476 | pass: 12 ticks, 0 mismatches | 1076 s |
| -20 | 3.0035 | 21.237 | -21 | 2.477 | pass: 12 ticks, 0 mismatches | 1076 s |
| -10 | 3.0036 | 21.228 | -12 | 2.477 | pass: 12 ticks, 0 mismatches | 1080 s |
| +0 | 3.0037 | 21.218 | -2 | 2.477 | pass: 12 ticks, 0 mismatches | 1073 s |
| +10 | 3.0038 | 21.207 | +9 | 2.477 | FAIL: 12 ticks, 64 mismatches | 1108 s |
| +20 | 3.0038 | 21.197 | +20 | 2.477 | pass: 12 ticks, 0 mismatches | 1080 s |
| +30 | 3.0039 | 21.186 | +29 | 2.477 | pass: 12 ticks, 0 mismatches | 1079 s |
| +40 | 3.0040 | 21.176 | +40 | 2.477 | pass: 12 ticks, 0 mismatches | 1090 s |
| +50 | 3.0041 | 21.167 | +49 | 2.477 | pass: 12 ticks, 0 mismatches | 1087 s |
| +60 | 3.0042 | 21.157 | +59 | 2.477 | pass: 12 ticks, 0 mismatches | 1076 s |
| +70 | 3.0042 | 21.147 | +70 | 2.477 | pass: 12 ticks, 0 mismatches | 1080 s |
| +80 | 3.0043 | 21.137 | +80 | 2.477 | pass: 12 ticks, 0 mismatches | 989 s |

12 of 13 sweep runs pass; calibrations 2 of 2.

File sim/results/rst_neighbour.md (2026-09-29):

# The reset line and its new neighbour on the ribbon

Generated by `sim/tb_rst_neighbour.py` (ngspice, the transistor models of `lib/2N7000.lib`). With the bus header on the back (D059) RST is pin 8, between ground (7) and BUS1# (9); on the front it had ground on both sides.

On the routed boards BUS1# has 27 gates and 20 drains, RST has 10 card inputs; the hub pulls BUS1# up with 10k, panel A pulls RST down with 10k; 500 pF of cable on each line.

| Coupling RST to BUS1# | Capacitor RST to GND at the hub | RST rises to | RST falls to | A card's reset input stage (Vto 0.8 V, 47k) dips to | BUS1# rises in | Reset releases in (3.5 V to 0.8 V) |
|---|---|---|---|---|---|---|
| 250 pF | none | 0.28 V | -1.21 V | 4.81 V of 5 | 167 us | 17 us |
| 250 pF | 1 nF | 0.18 V | -0.61 V | 4.91 V of 5 | 167 us | 32 us |
| 250 pF | 2.2 nF | 0.15 V | -0.39 V | 4.94 V of 5 | 167 us | 49 us |
| 250 pF | 4.7 nF | 0.12 V | -0.22 V | 4.97 V of 5 | 167 us | 86 us |
| 250 pF | 10 nF | 0.08 V | -0.11 V | 4.98 V of 5 | 167 us | 165 us |
| 350 pF | none | 0.35 V | -1.42 V | 4.78 V of 5 | 170 us | 20 us |
| 350 pF | 1 nF | 0.23 V | -0.78 V | 4.88 V of 5 | 169 us | 35 us |
| 350 pF | 2.2 nF | 0.20 V | -0.51 V | 4.92 V of 5 | 169 us | 52 us |
| 350 pF | 4.7 nF | 0.15 V | -0.29 V | 4.96 V of 5 | 169 us | 89 us |
| 350 pF | 10 nF | 0.11 V | -0.15 V | 4.98 V of 5 | 169 us | 168 us |
| 500 pF | none | 0.43 V | -1.63 V | 4.75 V of 5 | 173 us | 24 us |
| 500 pF | 1 nF | 0.31 V | -0.98 V | 4.85 V of 5 | 173 us | 39 us |
| 500 pF | 2.2 nF | 0.26 V | -0.67 V | 4.90 V of 5 | 173 us | 57 us |
| 500 pF | 4.7 nF | 0.21 V | -0.40 V | 4.94 V of 5 | 172 us | 94 us |
| 500 pF | 10 nF | 0.15 V | -0.21 V | 4.97 V of 5 | 172 us | 172 us |

The datasheet's lowest threshold is 0.8 V at 1 mA; the typical part is 2.1 V. A reset input stage that stays within a few tenths of the rail has not moved the logic behind it.

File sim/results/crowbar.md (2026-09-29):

# The hub's crowbar and reverse diode on the bench

Generated by `sim/tb_crowbar.py` (ngspice, the models of `lib/power.lib`). The five parts after the polyfuse (D061): a zener from the rail to an SCR's gate, a resistor and a capacitor from the gate to ground, the SCR across the rail, a 3 A diode across the rail the other way round.

## The models against their datasheets

| SCR model | Gate current to fire | Gate voltage | On-state at 1.5 A | 3 A | 10 A | 23 A | Holding current |
|---|---|---|---|---|---|---|---|
| typical | 2.0 mA | 0.62 V | 0.82 V | 0.88 V | 1.10 V | 1.48 V | 16 mA |
| hard | 14.2 mA | 1.43 V | 0.87 V | 0.95 V | 1.25 V | 1.76 V | 85 mA |
| easy | 0.3 mA | 0.61 V | 0.85 V | 0.90 V | 1.08 V | 1.39 V | 12 mA |
| BT151-500R datasheet, typical (maximum) | 2 (15) mA | 0.6 (1.5) V | | | | 1.4 (1.75) V | 7 (20) mA |

| Zener model, softest knee | At 5.25 V | At 5.5 V | 1 mA at | 8 mA at | Test current at |
|---|---|---|---|---|---|
| 1N4734A, 5.6 V | 3.84 mA | 18.80 mA | 5.01 V | 5.36 V | 5.67 V |
| 1N4735A, 6.2 V | 0.36 mA | 0.51 mA | 5.91 V | 6.10 V | 6.21 V |
| 1N4736A, 6.8 V | 0.15 mA | 0.22 mA | 6.41 V | 6.66 V | 6.83 V |

1N5408 model: 0.86 V at 1.5 A, 0.92 V at 3 A (datasheet: 1.2 V maximum), 1.11 V at 10 A.

## Which zener, which gate resistor

The machine idle. The supply at 5.0, 5.25 and 5.5 V; then turned from 5 V to 12 V in half a second behind a 1.5 A limit. Every corner of zener tolerance (-5 %, nominal, +5 %), SCR (typical, hard, easy) and polyfuse resistance (0.12, 0.32 ohm): 18 runs a row. "Fires at" is the rail at the moment the SCR takes a tenth of an amp, the lowest and the highest of the corners.

| Zener | RG | Zener current at 5.25 V | At 5.5 V | Gate at 5.5 V | Fires at | Verdict |
|---|---|---|---|---|---|---|
| 1N4734A, 5.6 V | 100 ohm | 5.30 mA | 8.83 mA | 0.71 V | 5.50 to 7.21 V | fires at or below 5.5 V |
| 1N4734A, 5.6 V | 220 ohm | 4.36 mA | 7.03 mA | 0.72 V | 5.36 to 7.15 V | fires at or below 5.5 V |
| 1N4735A, 6.2 V | 100 ohm | 0.55 mA | 0.77 mA | 0.07 V | 6.27 to 7.84 V | fits |
| 1N4735A, 6.2 V | 220 ohm | 0.54 mA | 0.76 mA | 0.13 V | 6.19 to 7.82 V | fits |
| 1N4736A, 6.8 V | 100 ohm | 0.25 mA | 0.36 mA | 0.03 V | 6.78 to 8.49 V | fits |
| 1N4736A, 6.8 V | 220 ohm | 0.25 mA | 0.36 mA | 0.06 V | 6.68 to 8.45 V | fits |

Chosen: **1N4735A (6.2 V) and 100 ohm**: of the combinations that fit, the one whose worst corner fires lowest, and of those the one whose gate is farthest from firing at 5.5 V.

## The chosen values, every way the voltage can arrive

The worst corner of each line: the zener at +5 % and the hard SCR for the highest rail, the polyfuse new (0.12 ohm) for the highest currents. "Without" is the same bench with the five parts left out.

| What happens | Machine | Supply's limit | Rail without | Rail's peak with | Rail after | SCR or diode, peak | Steady | Heat in it, steady | I2t (rating) |
|---|---|---|---|---|---|---|---|---|---|
| 5 V turned up to 12 V in half a second | running | 1.5 A | 7.5 V | 7.40 V | 7.40 V | not fired: the limit holds the rail | | | |
| 5 V turned up to 12 V in half a second | idle | 1.5 A | 12.0 V | 7.85 V | 0.87 V | SCR 58 A | 1.5 A | 1.3 W | 1.1 A2s (72) |
| 5 V turned up to 12 V in half a second | idle | 3 A | 12.0 V | 7.85 V | 0.95 V | SCR 58 A | 3.0 A | 2.8 W | 3.8 A2s (72) |
| 5 V turned up to 12 V in half a second | idle | 10 A | 12.0 V | 7.85 V | 1.25 V | SCR 58 A | 10.0 A | 12.4 W | 40.1 A2s (72) |
| output switched on with 30 V set | running | 1.5 A | 7.5 V | 7.40 V | 7.40 V | not fired: the limit holds the rail | | | |
| output switched on with 30 V set | idle | 1.5 A | 30.0 V | 7.86 V | 0.87 V | SCR 58 A | 1.5 A | 1.3 W | 0.9 A2s (72) |
| output switched on with 30 V set | idle | 10 A | 30.0 V | 7.87 V | 1.25 V | SCR 59 A | 10.0 A | 12.4 W | 28.2 A2s (72) |
| leads plugged in live at 30 V | idle, supply 470 uF | 1.5 A | 30.0 V | 8.24 V | 0.87 V | SCR 79 A | 1.5 A | 1.3 W | 0.8 A2s (72) |
| leads plugged in live at 30 V | idle, supply 470 uF | 10 A | 30.0 V | 8.25 V | 1.25 V | SCR 80 A | 10.0 A | 12.4 W | 10.6 A2s (72) |
| leads plugged in live at 30 V | idle, supply 2200 uF | 10 A | 30.0 V | 8.27 V | 1.25 V | SCR 90 A | 10.0 A | 12.4 W | 13.8 A2s (72) |
| leads crossed, 5 V | running | 1.5 A | -4.8 V | -0.85 V | -0.85 V | diode 1 A | 1.3 A | 1.1 W | 0.5 A2s (166) |
| leads crossed, 5 V | running | 10 A | -4.8 V | -1.10 V | -1.10 V | diode 10 A | 9.8 A | 10.8 W | 27.7 A2s (166) |
| leads crossed, plugged in live at 30 V | running, supply 470 uF | 1.5 A | -12.4 V | -2.79 V | -0.85 V | diode 90 A | 1.3 A | 1.1 W | 0.8 A2s (166) |
| leads crossed, plugged in live at 30 V | running, supply 2200 uF | 10 A | -28.8 V | -2.99 V | -1.10 V | diode 99 A | 9.8 A | 10.8 W | 13.6 A2s (166) |

The diode's I2t rating is its 200 A half-sine surge over 8.3 ms; the SCR's is the datasheet's, 10 ms. The SCR's peak is the machine's own capacitors emptying into it, over in a tenth of a millisecond; the datasheet's surge rating is 120 A for 10 ms.

## Heat: arithmetic on the datasheets, not simulation

The SCR stands in free air at 60 K/W (junction to ambient, datasheet), 125 degrees maximum. Room at 25 degrees. The polyfuse holds 1.5 A for ever, trips at 3 A in its own time, and at 7.5 A within 23 s (datasheet).

| Supply's limit | Heat in the SCR | Its junction in free air, left on | With a clip-on heatsink of 20 K/W | What ends it |
|---|---|---|---|---|
| 1.5 A | 1.3 W | 103 degrees | 54 degrees | nothing: the supply holds its limit for as long as it is left on |
| 3 A | 2.8 W | 195 degrees (over its 125) | 88 degrees | the polyfuse, if it trips: at 3 A it may hold for minutes |
| 10 A | 12.4 W | 772 degrees (over its 125) | 303 degrees (over its 125) | the polyfuse, within seconds (23 s at 7.5 A at the longest); a TO-220 without a heatsink warms about 15 degrees a second at this power |

So: with the supply's limit at 1.5 A, as `docs/bring-up.md` sets it, the SCR holds a fault for as long as it takes to notice, without a heatsink. With the limit left at 3 A or more the SCR in free air overheats before the polyfuse is sure to have tripped; an SCR that dies of heat dies shorted as a rule, which still holds the rail down, but it is then a part to replace. A clip-on TO-220 heatsink covers the 3 A case and the seconds of the 10 A case.

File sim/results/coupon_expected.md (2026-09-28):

# Coupon: what the bench should read

From `sim/tb_coupon.py kicad` on the card's netlist, 5.00 V, a x10 probe (15 pF) on the loop being read and 3.3 nF clipped on DRV;
LO, TYP, HI are the transistor model's threshold corners (0.8, 2.0, 3.0 V, `lib/2N7000.lib`), MIX gives every transistor its own.
The band is the lowest to the highest value over all the runs; a bench reading outside it means the cell in copper is not the modelled one (docs/bring-up.md section 1).

| Measurement | Unit | TYP | LO | HI | MIX1 | MIX2 | MIX3 | Band |
|---|---|---|---|---|---|---|---|---|
| Ring period at RING (buffered) | us | 14.6 | 5.9 | 23.6 | 11.2 | 7.2 | 17.3 | 5.9 to 23.6 |
| Ring period at RING0 (the ring node) | us | 14.6 | 5.9 | 23.6 | 11.2 | 7.2 | 17.3 | 5.9 to 23.6 |
| RING0 peak (the ring's swing) | V | 3.2 | 1.6 | 4.1 | 3.0 | 2.0 | 3.2 | 1.6 to 4.1 |
| Rise 10-90 %, fan-out 1 (FO1) | us | 10.70 | 10.31 | 11.55 | 10.69 | 10.70 | 10.31 | 10.31 to 11.55 |
| Rise 10-90 %, fan-out 10 (FO10) | us | 70.08 | 66.84 | 77.22 | 70.28 | 73.77 | 72.36 | 66.84 to 77.22 |
| Fall 90-10 %, fan-out 1 (FO1) | us | 0.06 | 0.06 | 0.06 | 0.06 | 0.06 | 0.06 | 0.06 to 0.06 |
| Fall 90-10 %, fan-out 10 (FO10) | us | 1.18 | 0.62 | 2.22 | 1.18 | 1.18 | 0.61 | 0.61 to 2.22 |
| Delay IN edge to FO1 half way (rising) | us | 6.34 | 5.89 | 4.75 | 6.34 | 6.41 | 5.96 | 4.75 to 6.41 |
| Delay IN edge to FO10 half way (rising) | us | 28.71 | 24.93 | 13.74 | 24.34 | 19.04 | 21.62 | 13.74 to 28.71 |
| NAND low, N1 N2 N3 = 111 | V | 0.001 | 0.001 | 0.001 | 0.001 | 0.001 | 0.001 | 0.001 to 0.001 |
| NOR low, N1 N2 N3 = 111 | V | 0.000 | 0.000 | 0.000 | 0.000 | 0.000 | 0.000 | 0.000 to 0.000 |
| BUS low, IN high (10k pull-up) | V | 0.001 | 0.001 | 0.002 | 0.001 | 0.001 | 0.001 | 0.001 to 0.002 |
| X lower trip point | V | 1.97 | 0.82 | 2.92 | 3.01 | 2.97 | 0.77 | 0.77 to 3.01 |
| X upper trip point | V | 2.39 | 1.23 | 3.34 | 3.43 | 3.39 | 1.19 | 1.19 to 3.43 |
| OSC period | ms | 1.64 | 2.48 | 1.72 | 1.79 | 1.77 | 2.55 | 1.64 to 2.55 |
| OSC duty (high fraction) |  | 0.55 | 0.79 | 0.36 | 0.34 | 0.35 | 0.80 | 0.34 to 0.80 |
| Q period | ms | 3.28 | 4.95 | 3.44 | 3.58 | 3.53 | 5.11 | 3.28 to 5.11 |
| Q edges per OSC rising edge |  | 1.00 | 1.00 | 1.00 | 1.00 | 1.00 | 1.00 | 1.00 to 1.00 |
| Q while RST is high, away from clock edges | V | 0.00 | 0.00 | 0.00 | 0.00 | 0.00 | 0.00 | 0.00 to 0.00 |
| Q pulse at a clock edge while RST is high: peak | V | 0.00 | 0.00 | 0.00 | 0.00 | 4.13 | 0.00 | 0.00 to 4.13 |
| That pulse: width above 1 V | us | 0 | 0 | 0 | 0 | 11 | 0 | 0 to 11 |
| DRV high (3.3 nF, 10k) | V | 4.02 | 4.02 | 4.02 | 4.02 | 4.02 | 4.02 | 4.02 to 4.02 |
| DRV rise 0.5 to 3.5 V | us | 6.6 | 6.6 | 6.6 | 6.6 | 6.6 | 6.6 | 6.6 to 6.6 |
| DRV fall 3.5 to 0.8 V | us | 49 | 49 | 49 | 49 | 49 | 49 | 49 to 49 |
| VTO | V | 2.05 | 0.88 | 3.02 | 3.02 | 2.05 | 0.88 | 0.88 to 3.02 |
| ROM high, IN low | V | 4.52 | 4.52 | 4.52 | 4.52 | 4.52 | 4.52 | 4.52 to 4.52 |
| ROM low, IN high | V | 0.000 | 0.000 | 0.000 | 0.000 | 0.000 | 0.000 | 0.000 to 0.000 |
| Supply current, IN low (meter average) | mA | 5.7 | 7.4 | 4.7 | 4.6 | 4.8 | 7.5 | 4.6 to 7.5 |
| Supply current, IN high (the LED, the row) | mA | 12.3 | 13.8 | 10.7 | 10.9 | 11.2 | 13.6 | 10.7 to 13.8 |
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

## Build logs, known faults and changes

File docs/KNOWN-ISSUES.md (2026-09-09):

# Known issues

Tracked as GitHub issues; this file is the index so it survives without GitHub.

## Origin calculator (`boards/00-origin-calculator/`)

These are in the hand-made design and are left there on purpose. They are
fixed by the two's-complement redesign of board one (D006), not by editing the origin.

| # | Issue | Symptom | Cause |
|---|---|---|---|
| 1 | Converter XOR keyed on SUB instead of the result sign | 7 - 5 stores 13; every subtraction with A >= B is wrong | The sign-magnitude converter inverts the sum whenever SUB is set, not when the result is negative |
| 2 | Adder carry-out leaks into result bit 3 in subtract mode | 6 - 6 stores 8 | Carry-out of the 3-bit adder feeds bit 3 of the register unmasked |
| 3 | Memory bits OUT_B0/OUT_B1 sit at 1.2 V high | Marginal decode; one bad transistor away from a wrong digit | Each drives 13 decoder inputs through a 4.7k pull-up; RTL fan-out is about 3 |
| 4 | Simulation clock is a 100 ns pulse | The sim stimulus is far faster than the gates can switch | Value chosen before gate delay was understood |

The fixed versions of 1 and 2 (and a 2.2k pull-up for 3) exist in
`experiments/muldiv/Untitled.kicad_sch`, which is the origin sheet as modified
during the multiply/divide experiment.

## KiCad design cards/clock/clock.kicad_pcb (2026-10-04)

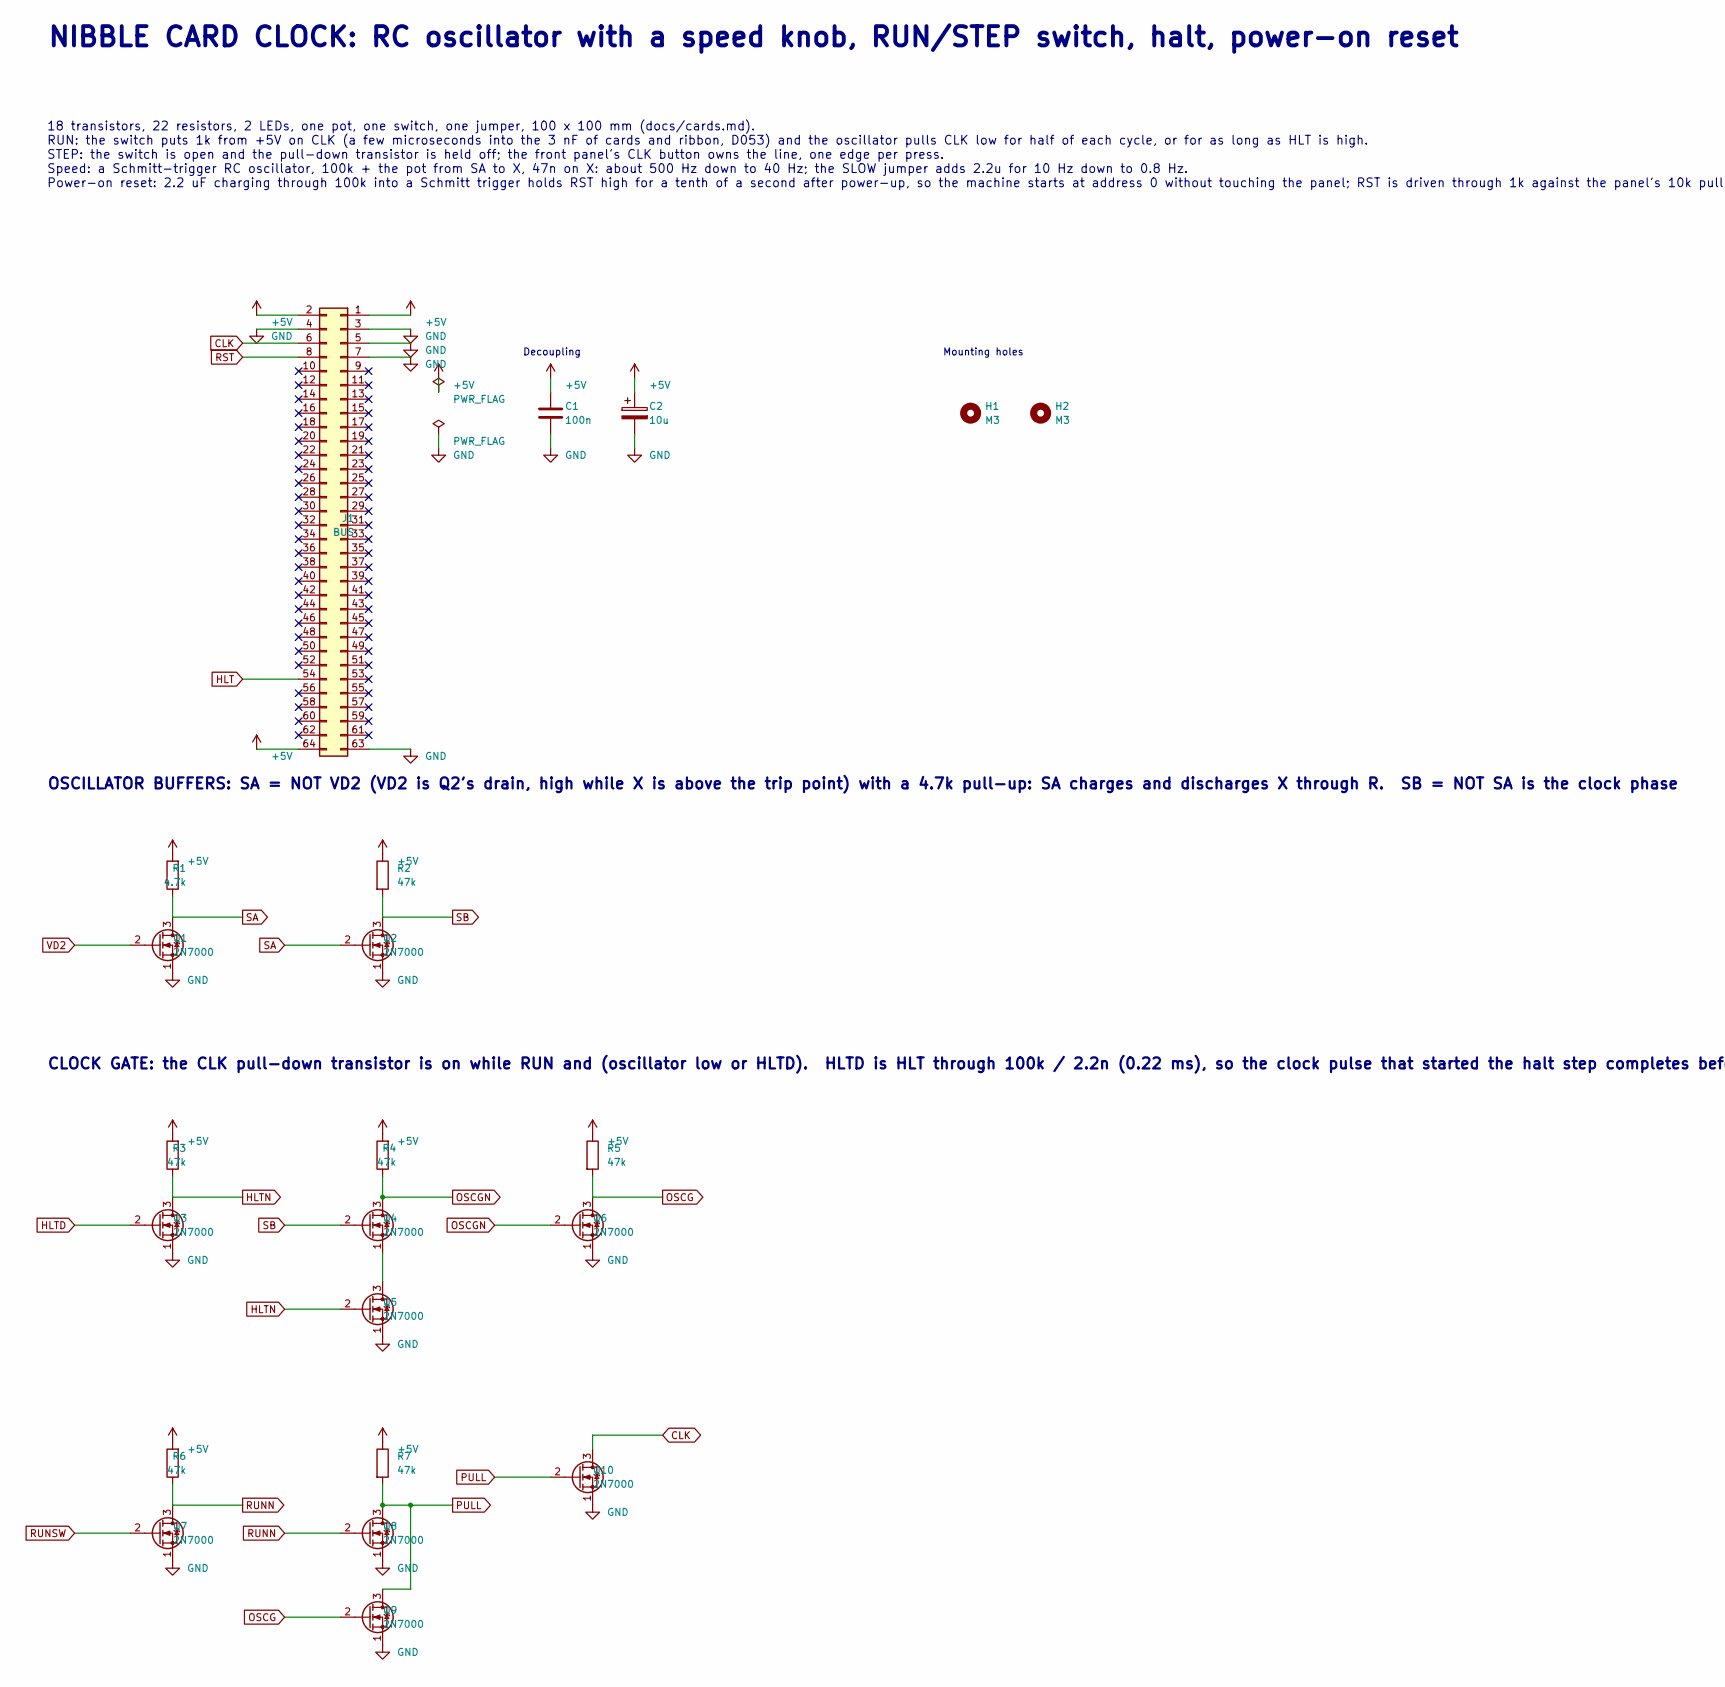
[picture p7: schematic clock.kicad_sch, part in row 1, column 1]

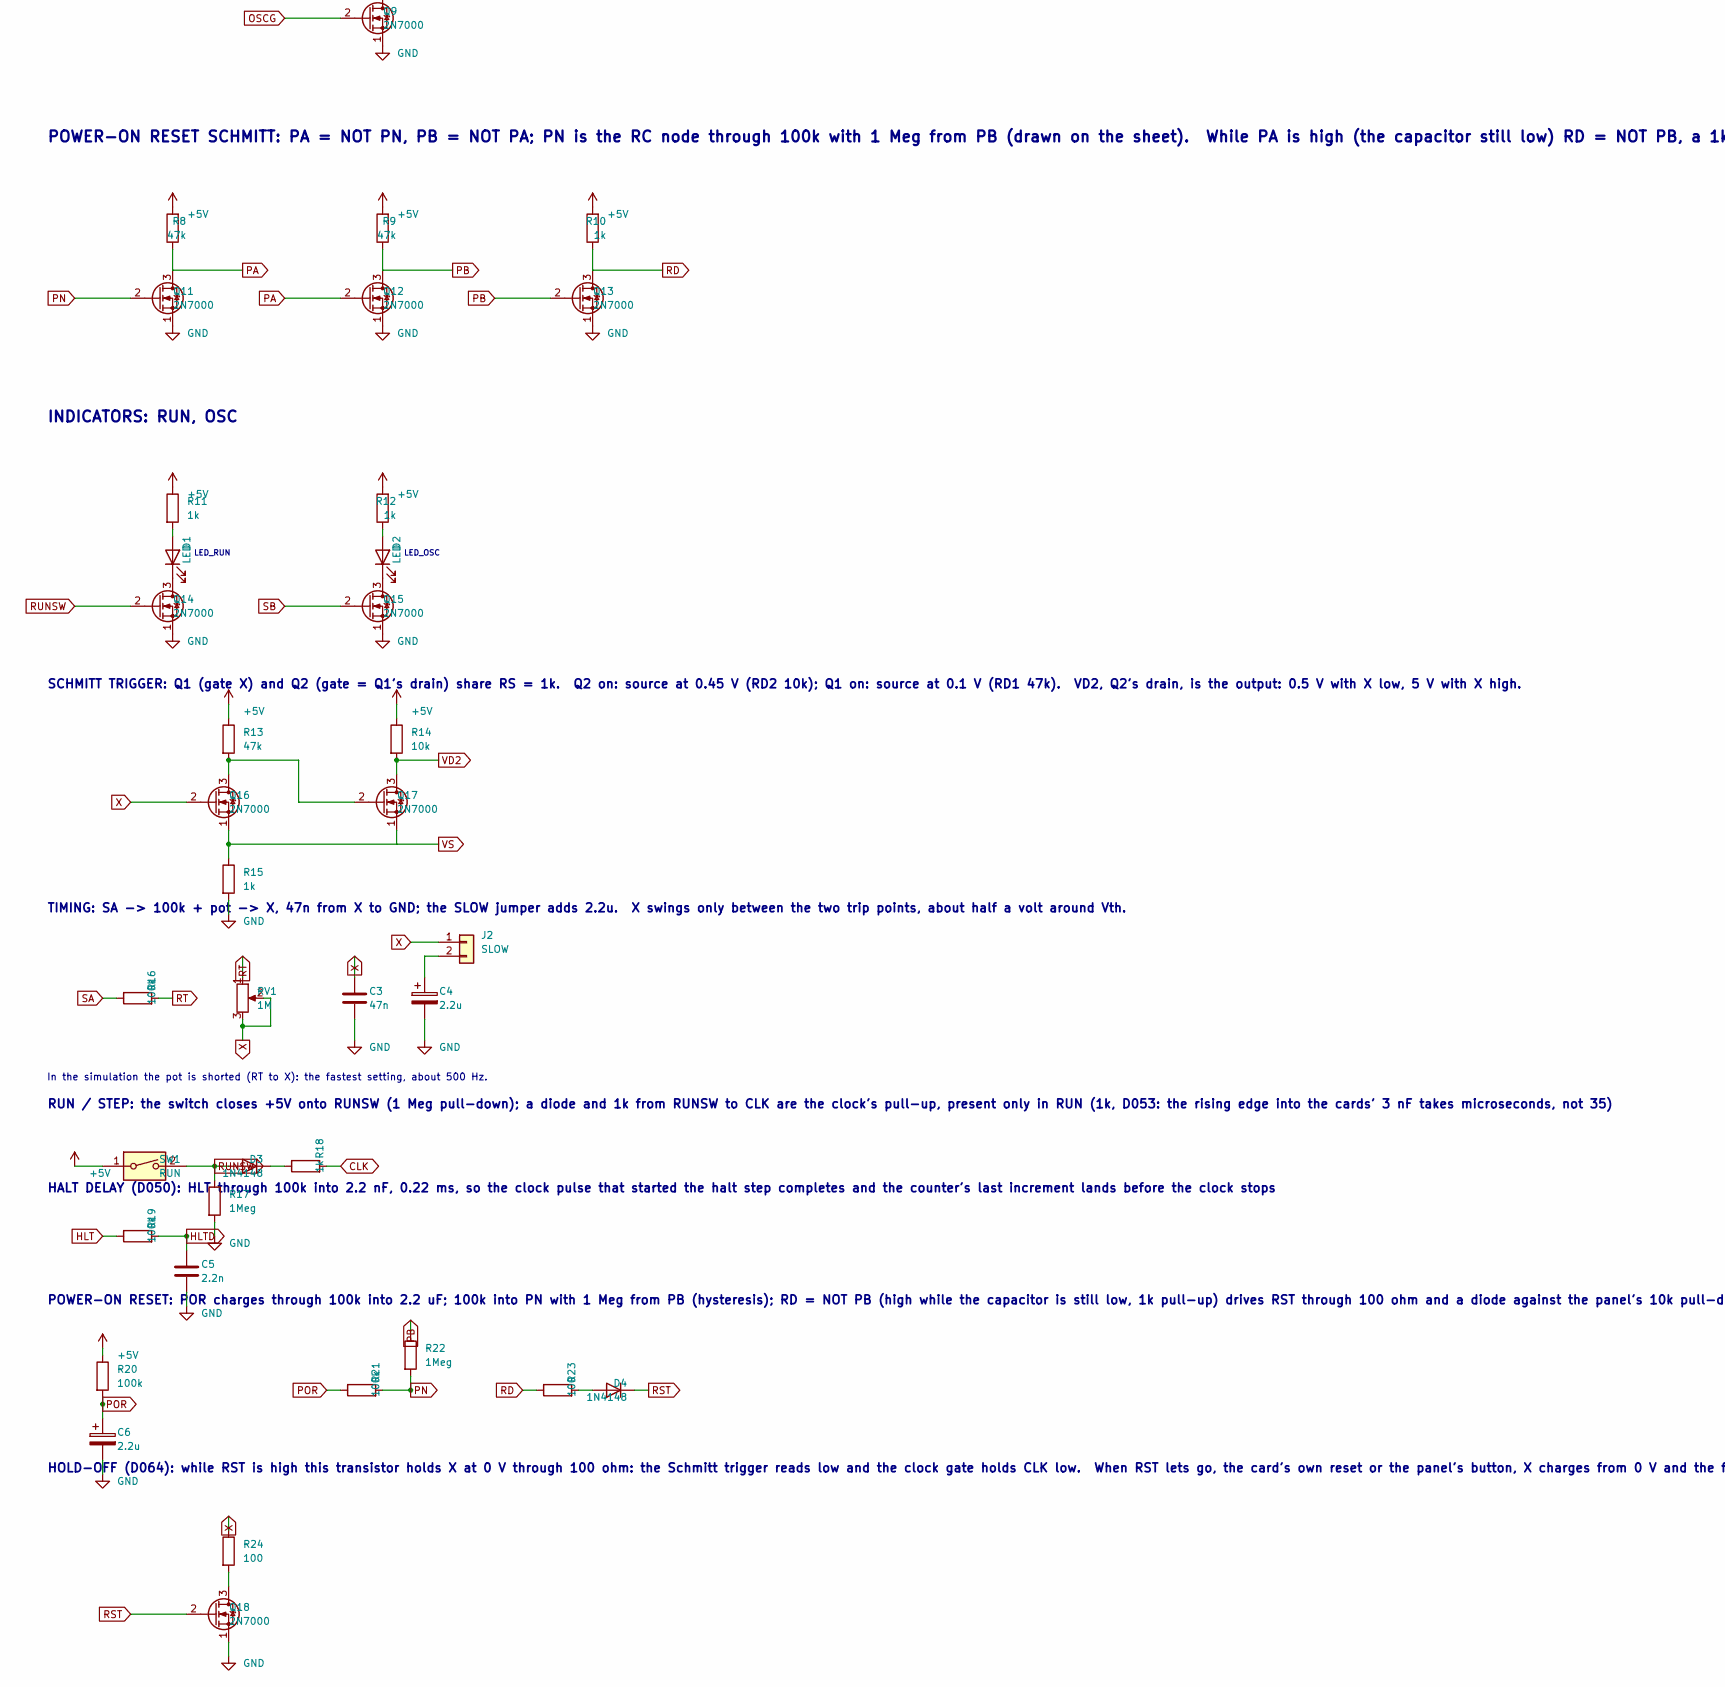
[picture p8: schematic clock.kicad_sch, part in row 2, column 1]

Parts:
C1: 100n; C_Disc_D5.0mm_W2.5mm_P2.50mm
C2: 10u; CP_Radial_D5.0mm_P2.00mm
C3: 47n; C_Disc_D5.0mm_W2.5mm_P2.50mm
C4, C6: 2.2u; CP_Radial_D5.0mm_P2.00mm
C5: 2.2n; C_Disc_D5.0mm_W2.5mm_P2.50mm
D1, D2: LED; LED_D3.0mm
D3, D4: 1N4148; D_DO-35_SOD27_P7.62mm_Horizontal
H1, H2: M3; MountingHole_3.2mm_M3_Pad
J1: BUS; IDC-Header_2x32_P2.54mm_Vertical
J2: SLOW; PinHeader_1x02_P2.54mm_Vertical
Q1, Q2, Q3, Q4, Q5, Q6, Q7, Q8, Q9, Q10, Q11, Q12, Q13, Q14, Q15, Q16, Q17, Q18: 2N7000; TO-92_Inline_Wide
R1: 4.7k; R_Axial_DIN0207_L6.3mm_D2.5mm_P5.08mm_Vertical
R2, R3, R4, R5, R6, R7, R8, R9, R13: 47k; R_Axial_DIN0207_L6.3mm_D2.5mm_P5.08mm_Vertical
R10, R11, R12, R15, R18: 1k; R_Axial_DIN0207_L6.3mm_D2.5mm_P5.08mm_Vertical
R14: 10k; R_Axial_DIN0207_L6.3mm_D2.5mm_P5.08mm_Vertical
R16, R19, R20, R21: 100k; R_Axial_DIN0207_L6.3mm_D2.5mm_P5.08mm_Vertical
R17, R22: 1Meg; R_Axial_DIN0207_L6.3mm_D2.5mm_P5.08mm_Vertical
R23, R24: 100; R_Axial_DIN0207_L6.3mm_D2.5mm_P5.08mm_Vertical
RV1: 1M; Potentiometer_Bourns_PTV09A-4_Single_Vertical
SW1: RUN; SW_DIP_SPSTx01_Slide_9.78x4.72mm_W7.62mm_P2.54mm

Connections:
+5V: C1.1, C2.1, J1.1, J1.2, J1.64, R1.2, R2.1, R3.2, R4.2, R5.1, R6.2, R7.1, R8.2, R9.2, R10.2, R11.1, R12.2, R13.1, R14.1, R20.1, SW1.1
CLK: J1.6, Q10.3 (D), R18.2
GND: C1.2, C2.2, C3.2, C4.2, C5.2, C6.2, J1.3, J1.4, J1.5, J1.7, J1.63, Q1.1 (S), Q2.1 (S), Q3.1 (S), Q5.1 (S), Q6.1 (S), Q7.1 (S), Q8.1 (S), Q9.1 (S), Q10.1 (S), Q11.1 (S), Q12.1 (S), Q13.1 (S), Q14.1 (S), Q15.1 (S), Q18.1 (S), R15.2, R17.2
HLT: J1.54, R19.1
HLTD: C5.1, Q3.2 (G), R19.2
HLTN: Q3.3 (D), Q5.2 (G), R3.1
unnamed: D1.2 (A), R11.2
unnamed: D1.1 (K), Q14.3 (D)
unnamed: D2.2 (A), R12.1
unnamed: D2.1 (K), Q15.3 (D)
unnamed: D3.1 (K), R18.1
unnamed: D4.2 (A), R23.2
unnamed: C4.1, J2.2
unnamed: Q4.1 (S), Q5.3 (D)
unnamed: Q16.3 (D), Q17.2 (G), R13.2
unnamed: Q18.3 (D), R24.2
OSCG: Q6.3 (D), Q9.2 (G), R5.2
OSCGN: Q4.3 (D), Q6.2 (G), R4.1
PA: Q11.3 (D), Q12.2 (G), R8.1
PB: Q12.3 (D), Q13.2 (G), R9.1, R22.1
PN: Q11.2 (G), R21.2, R22.2
POR: C6.1, R20.2, R21.1
PULL: Q8.3 (D), Q9.3 (D), Q10.2 (G), R7.2
RD: Q13.3 (D), R10.1, R23.1
RST: D4.1 (K), J1.8, Q18.2 (G)
RT: R16.2, RV1.1
RUNN: Q7.3 (D), Q8.2 (G), R6.1
RUNSW: D3.2 (A), Q7.2 (G), Q14.2 (G), R17.1, SW1.2
SA: Q1.3 (D), Q2.2 (G), R1.1, R16.1
SB: Q2.3 (D), Q4.2 (G), Q15.2 (G), R2.2
VD2: Q1.2 (G), Q17.3 (D), R14.2
VS: Q16.1 (S), Q17.1 (S), R15.1
X: C3.1, J2.1, Q16.2 (G), R24.1, RV1.2, RV1.3

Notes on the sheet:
NIBBLE CARD CLOCK: RC oscillator with a speed knob, RUN/STEP switch, halt, power-on reset
18 transistors, 22 resistors, 2 LEDs, one pot, one switch, one jumper, 100 x 100 mm (docs/cards.md). RUN: the switch puts 1k from +5V on CLK (a few microseconds into the 3 nF of cards and ribbon, D053) and the oscillator pulls CLK low for half of each cycle, or for as long as HLT is high. STEP: the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
OSCILLATOR BUFFERS: SA = NOT VD2 (VD2 is Q2's drain, high while X is above the trip point) with a 4.7k pull-up: SA charges and discharges X through R. SB = NOT SA is the clock phase
CLOCK GATE: the CLK pull-down transistor is on while RUN and (oscillator low or HLTD). HLTD is HLT through 100k / 2.2n (0.22 ms), so the clock pulse that started the halt step completes before the clock stops (D050)
POWER-ON RESET SCHMITT: PA = NOT PN, PB = NOT PA; PN is the RC node through 100k with 1 Meg from PB (drawn on the sheet). While PA is high (the capacitor still low) RD = NOT PB, a 1k pull-up, drives RST through 100 ohm and a diode; the panel's 10k pull-down releases it in tens of microseconds (D053)
INDICATORS: RUN, OSC
LED_RUN
LED_OSC
Decoupling
Mounting holes
SCHMITT TRIGGER: Q1 (gate X) and Q2 (gate = Q1's drain) share RS = 1k. Q2 on: source at 0.45 V (RD2 10k); Q1 on: source at 0.1 V (RD1 47k). VD2, Q2's drain, is the output: 0.5 V with X low, 5 V with X high.
TIMING: SA -> 100k + pot -> X, 47n from X to GND; the SLOW jumper adds 2.2u. X swings only between the two trip points, about half a volt around Vth.
In the simulation the pot is shorted (RT to X): the fastest setting, about 500 Hz.
RUN / STEP: the switch closes +5V onto RUNSW (1 Meg pull-down); a diode and 1k from RUNSW to CLK are the clock's pull-up, present only in RUN (1k, D053: the rising edge into the cards' 3 nF takes microseconds, not 35)
HALT DELAY (D050): HLT through 100k into 2.2 nF, 0.22 ms, so the clock pulse that started the halt step completes and the counter's last increment lands before the clock stops
POWER-ON RESET: POR charges through 100k into 2.2 uF; 100k into PN with 1 Meg from PB (hysteresis); RD = NOT PB (high while the capacitor is still low, 1k pull-up) drives RST through 100 ohm and a diode against the panel's 10k pull-down (D053)
HOLD-OFF (D064): while RST is high this transistor holds X at 0 V through 100 ohm: the Schmitt trigger reads low and the clock gate holds CLK low. When RST lets go, the card's own reset or the panel's button, X charges from 0 V and the first clock edge comes 1.3 to 5.4 ms later at the fastest setti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

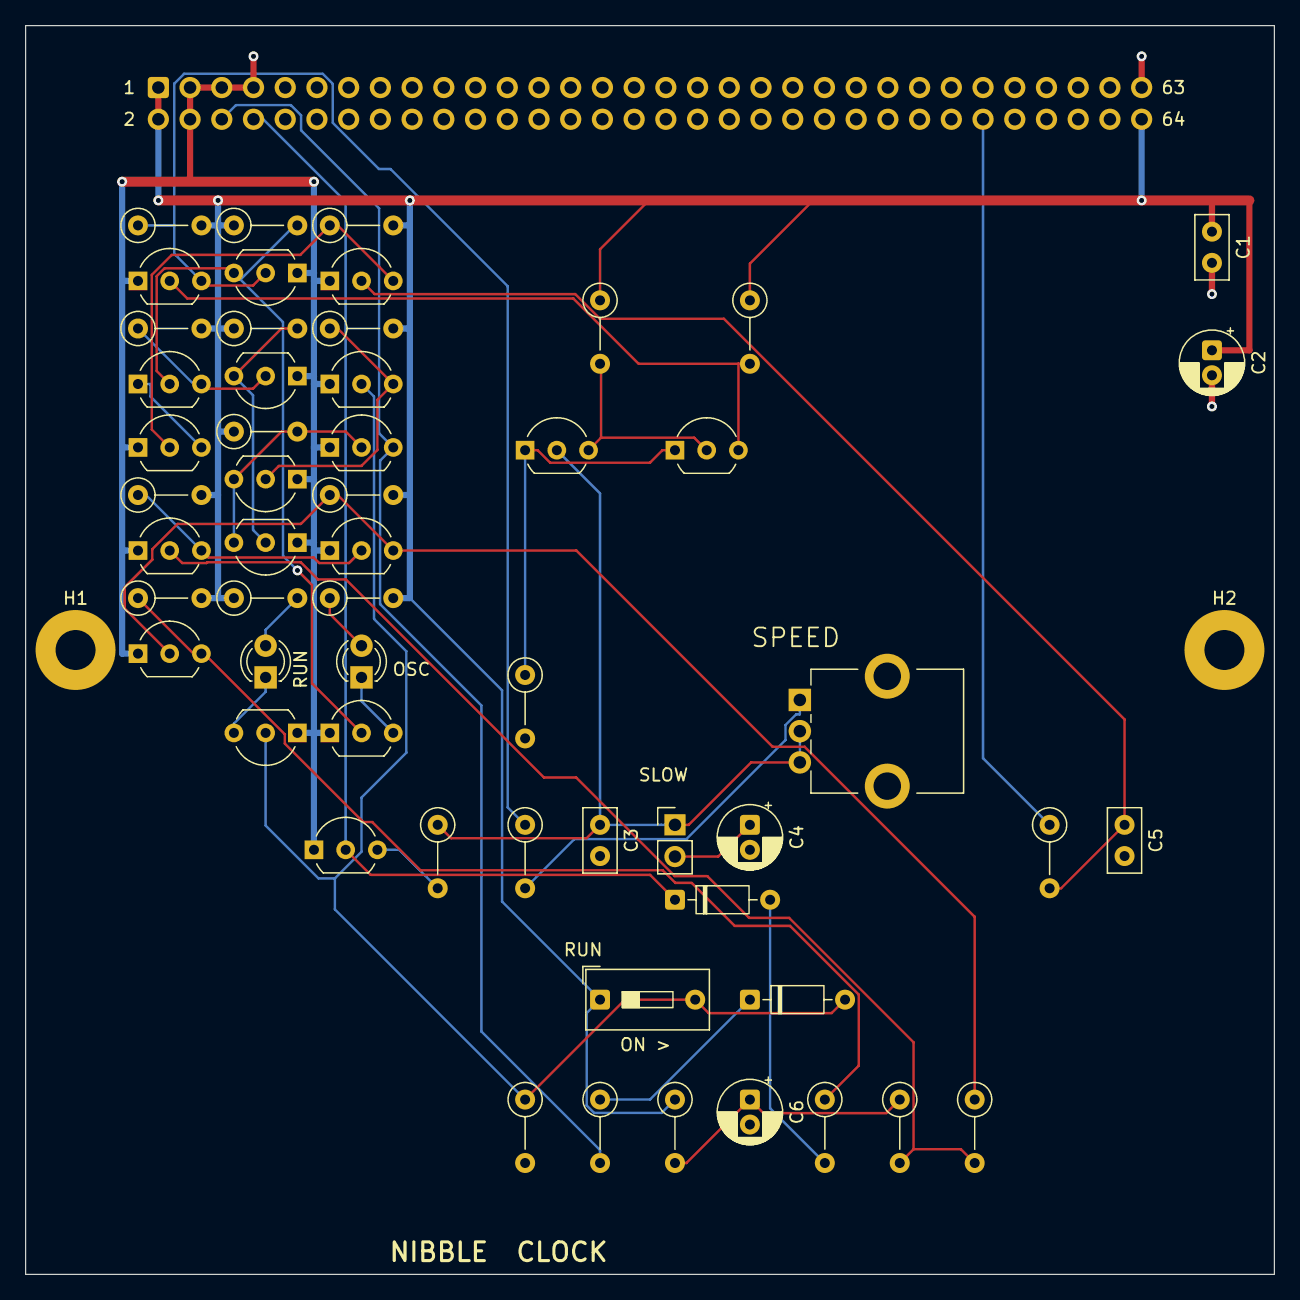
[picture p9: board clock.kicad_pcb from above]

Board: 2 copper layers, 100.0 x 100.0 mm, 58 parts (1 on the bottom side), 33 nets.

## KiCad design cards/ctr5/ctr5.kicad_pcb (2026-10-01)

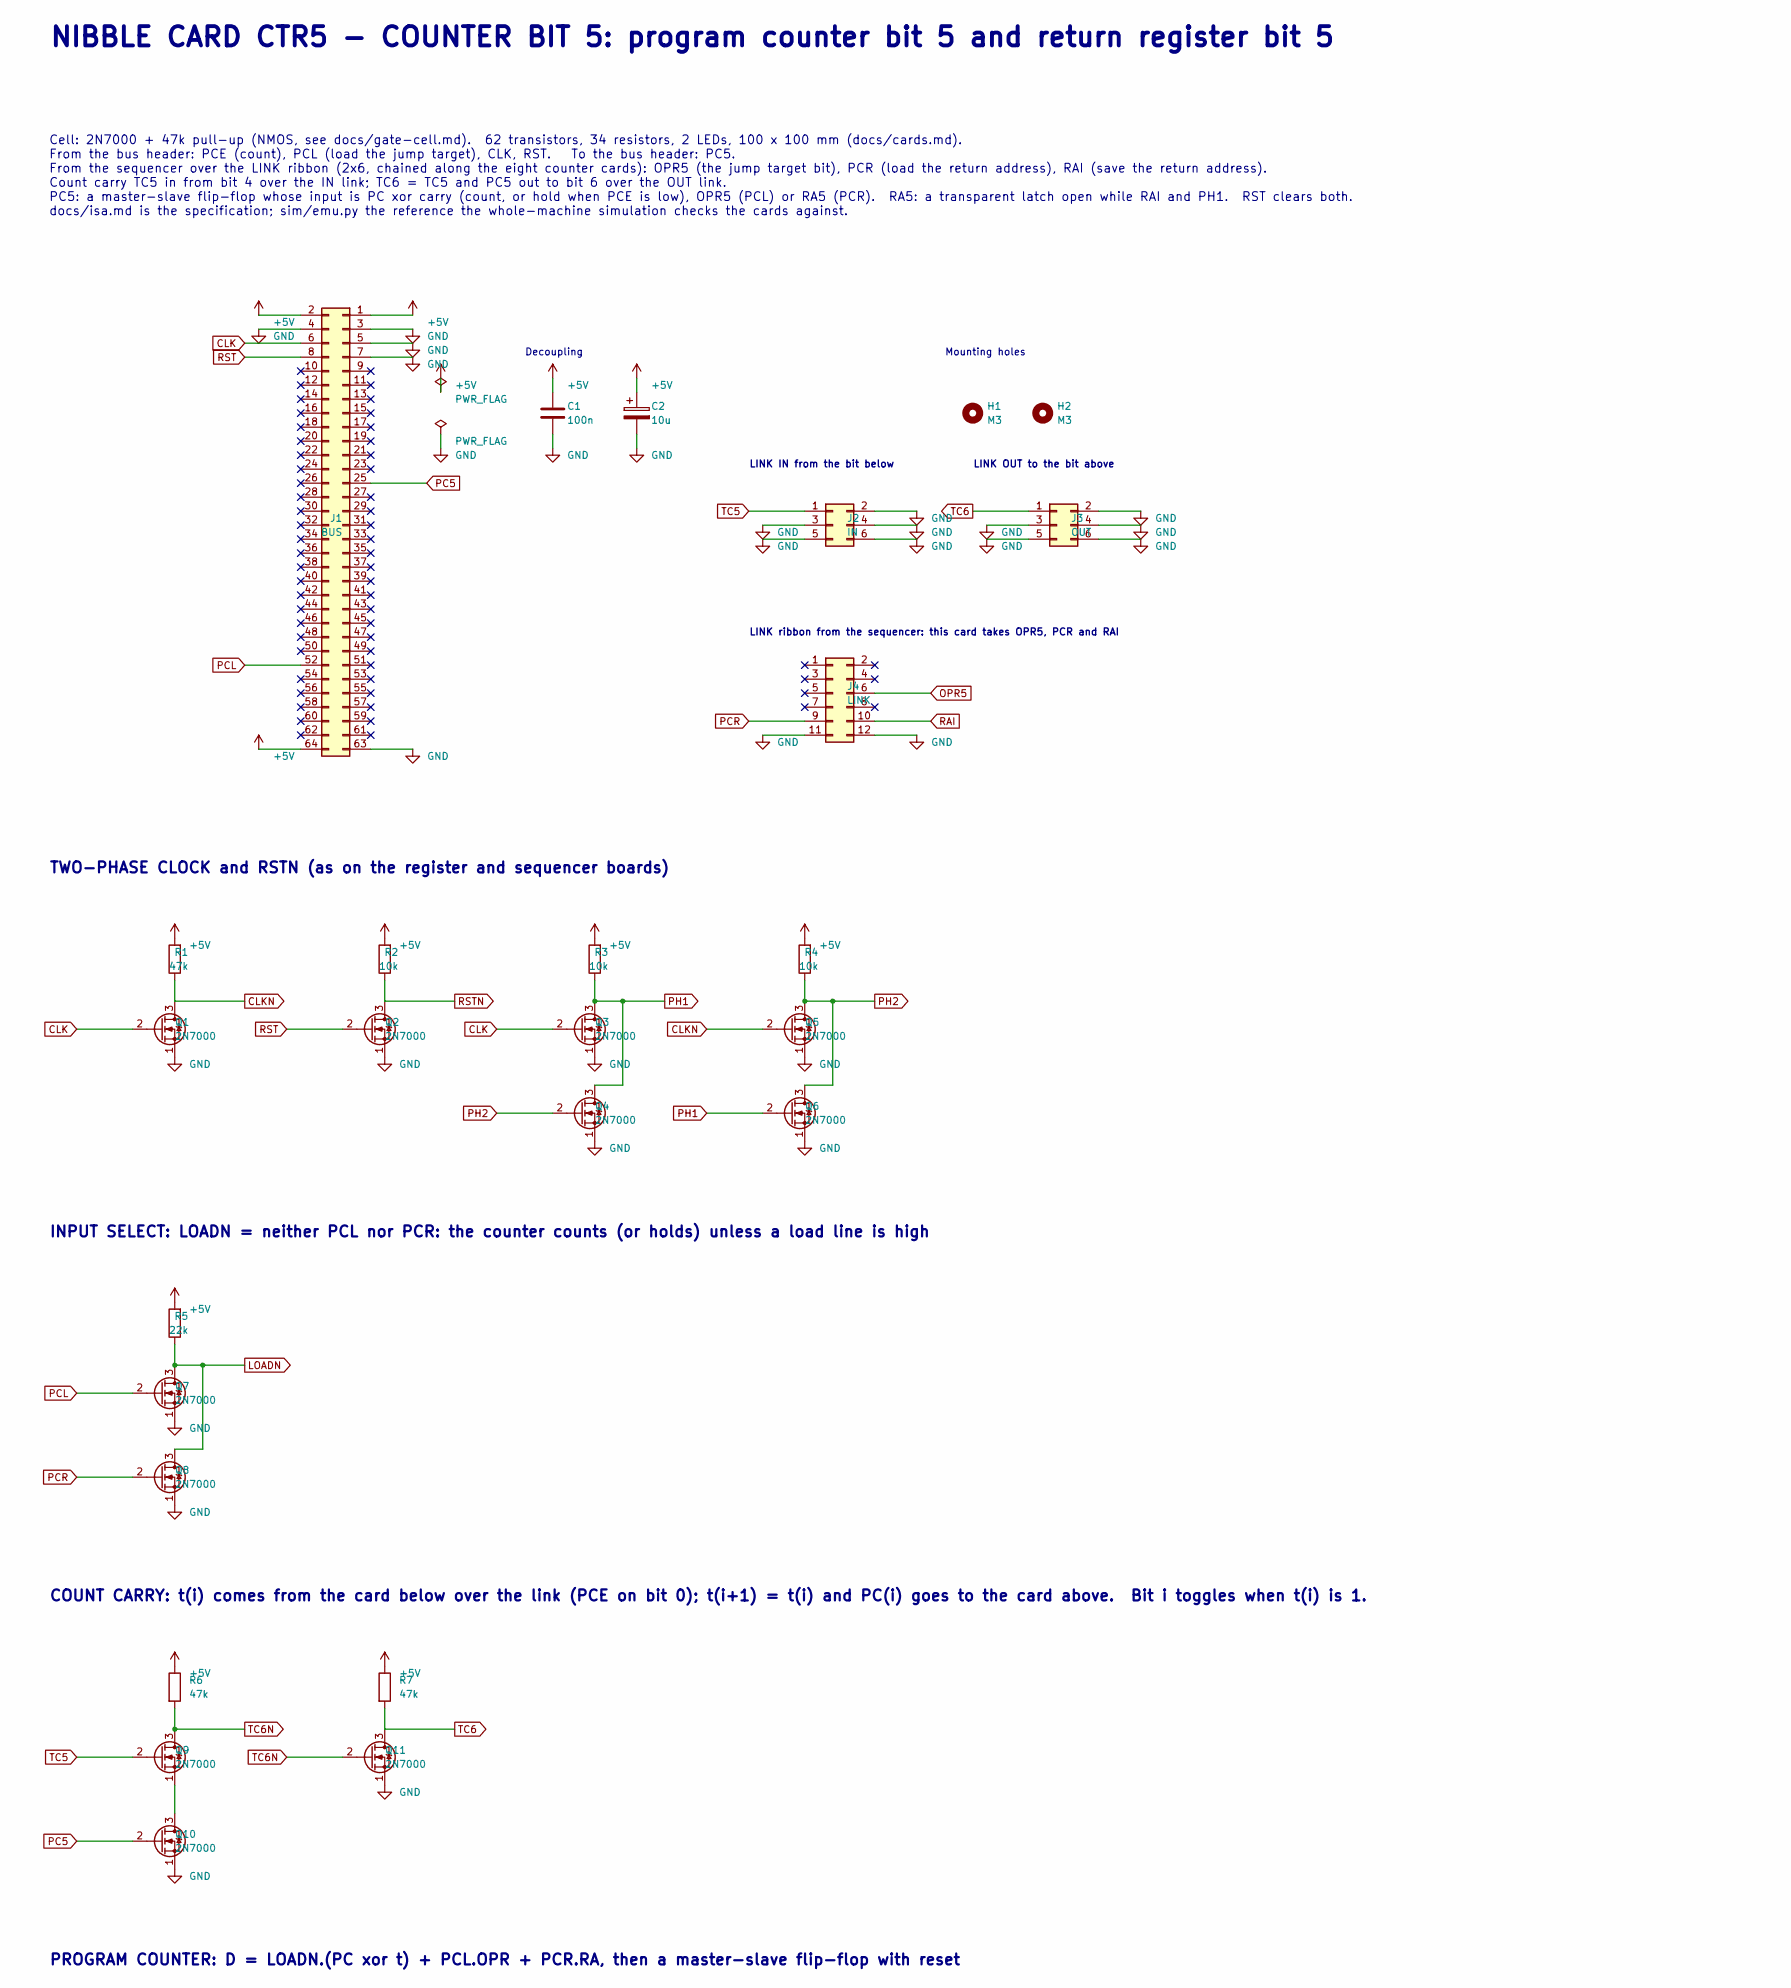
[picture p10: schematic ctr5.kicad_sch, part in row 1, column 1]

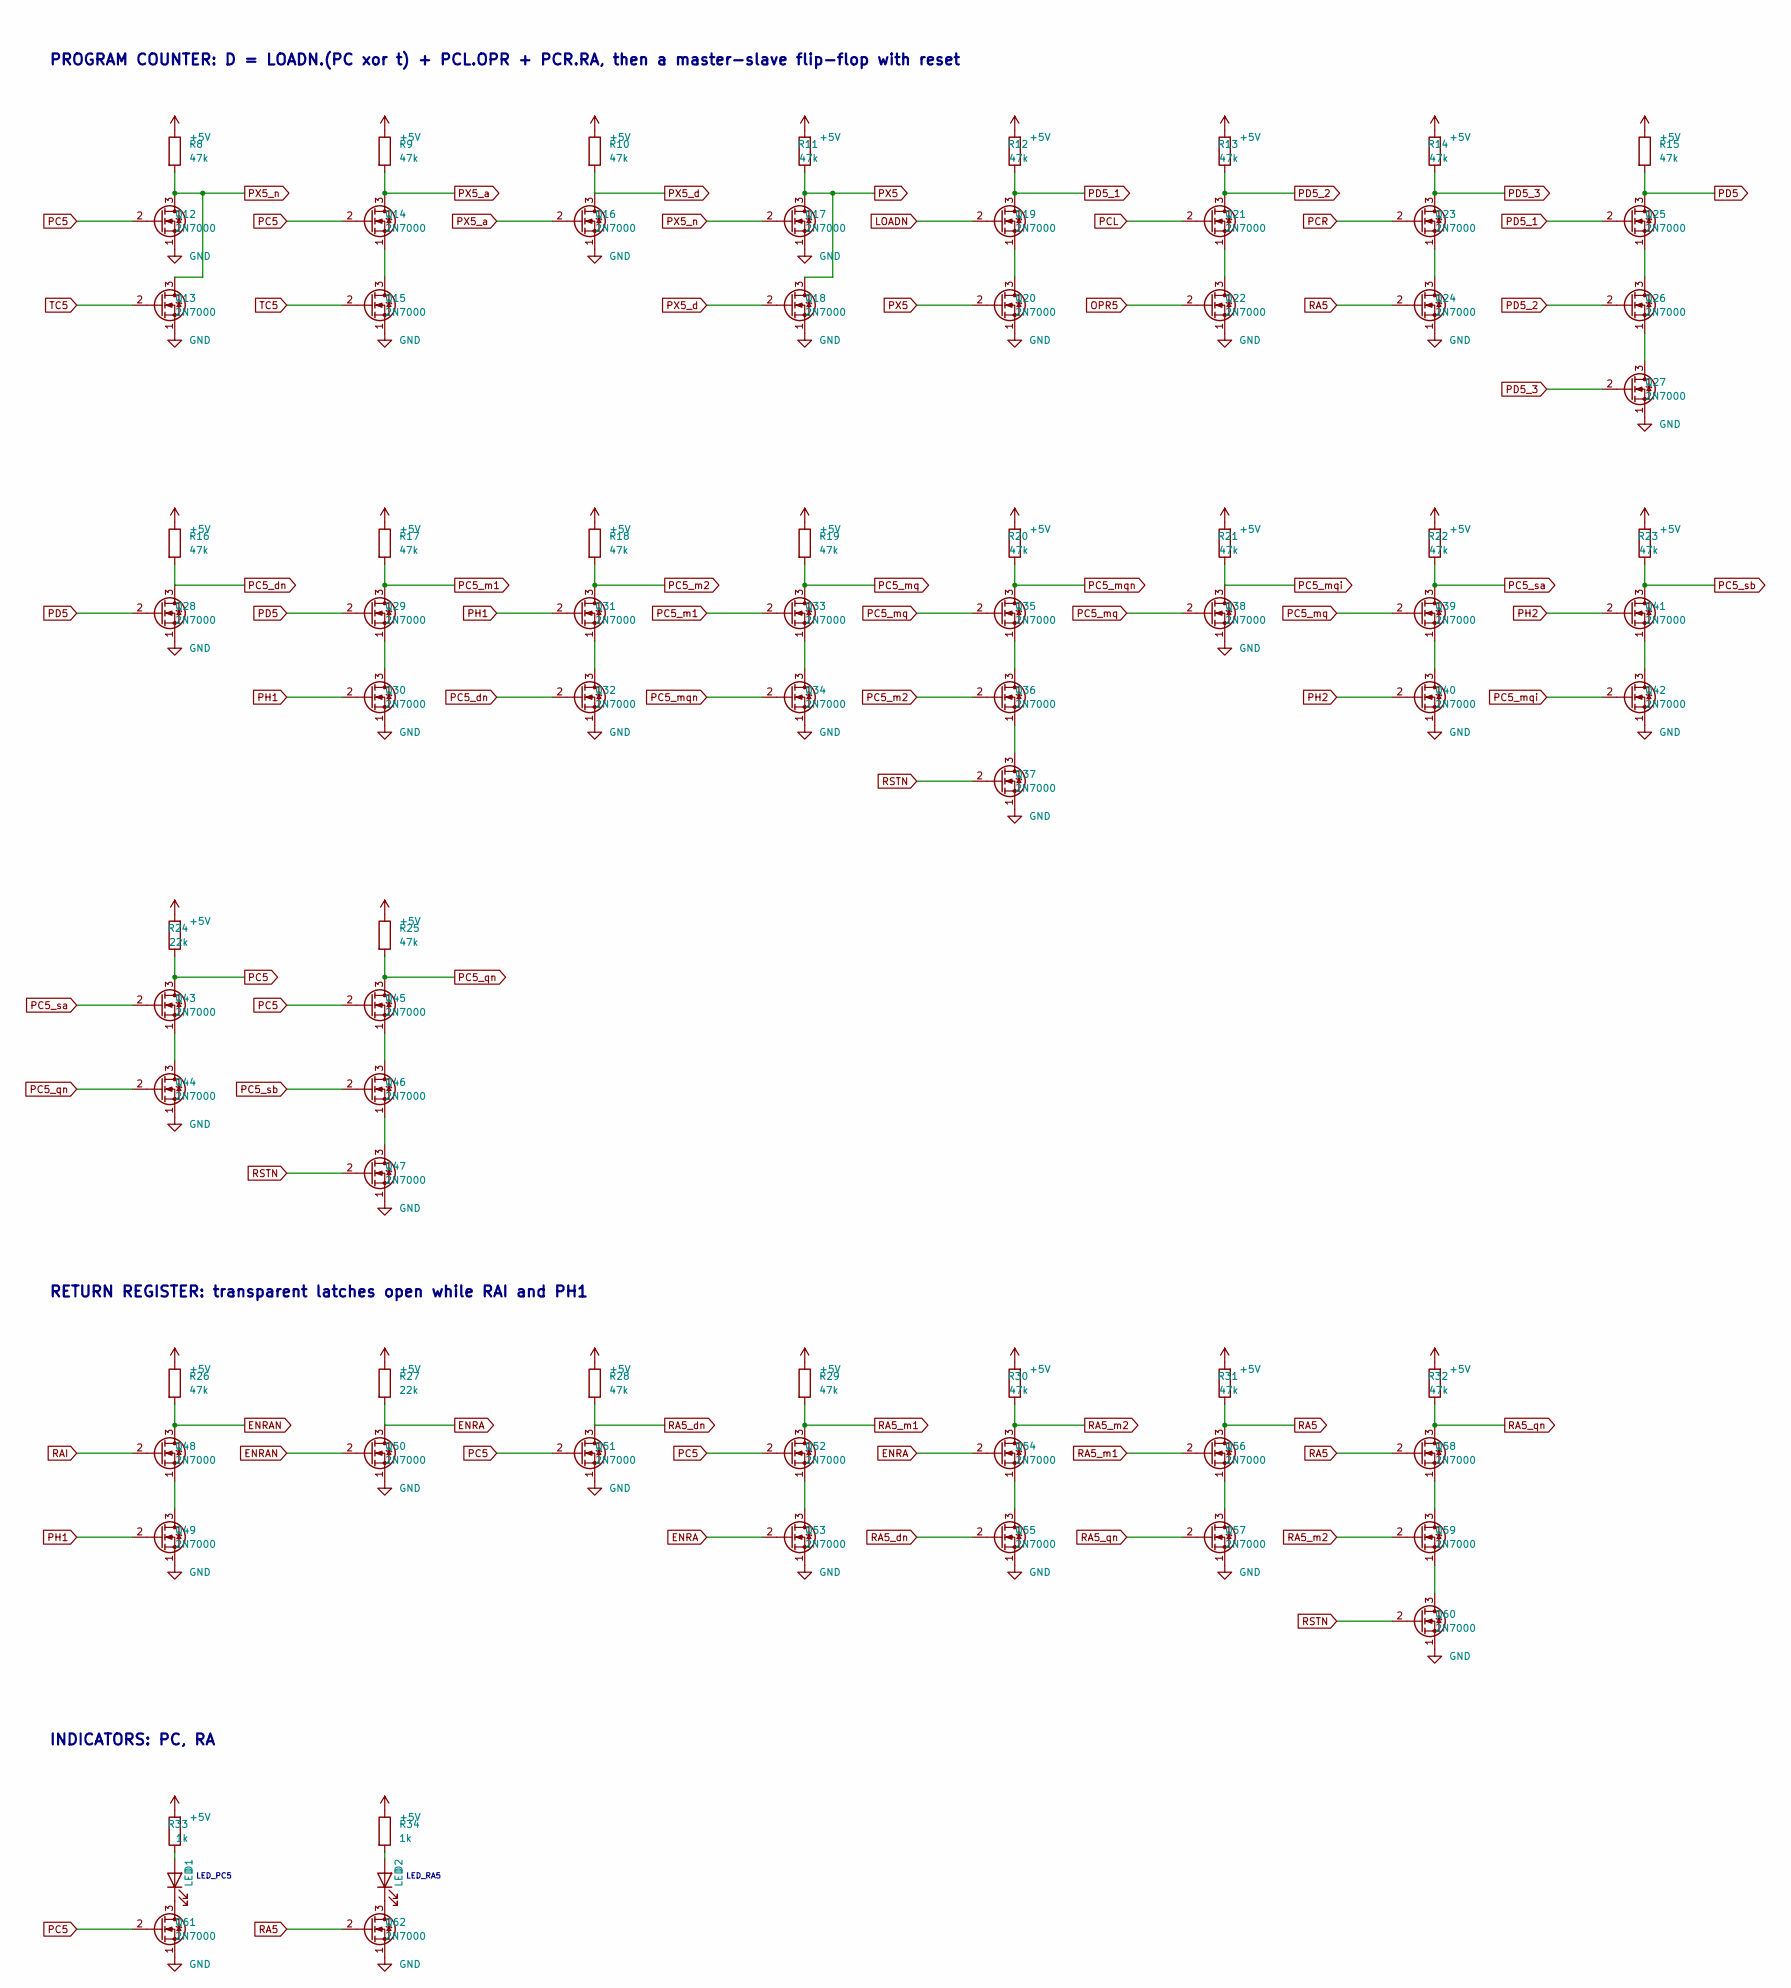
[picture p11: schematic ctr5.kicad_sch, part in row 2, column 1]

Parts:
C1: 100n; C_Disc_D5.0mm_W2.5mm_P2.50mm
C2: 10u; CP_Radial_D5.0mm_P2.00mm
D1, D2: LED; LED_D3.0mm
H1, H2: M3; MountingHole_3.2mm_M3_Pad
J1: BUS; IDC-Header_2x32_P2.54mm_Vertical
J2: IN; IDC-Header_2x03_P2.54mm_Vertical
J3: OUT; IDC-Header_2x03_P2.54mm_Vertical
J4: LINK; IDC-Header_2x06_P2.54mm_Vertical
Q1, Q2, Q3, Q4, Q5, Q6, Q7, Q8, Q9, Q10, Q11, Q12, Q13, Q14, Q15, Q16, Q17, Q18, Q19, Q20, Q21, Q22, Q23, Q24, Q25, Q26, Q27, Q28, Q29, Q30, Q31, Q32, Q33, Q34, Q35, Q36, Q37, Q38, Q39, Q40, Q41, Q42, Q43, Q44, Q45, Q46, Q47, Q48, Q49, Q50, Q51, Q52, Q53, Q54, Q55, Q56, Q57, Q58, Q59, Q60, Q61, Q62: 2N7000; TO-92_Inline_Wide
R1, R6, R7, R8, R9, R10, R11, R12, R13, R14, R15, R16, R17, R18, R19, R20, R21, R22, R23, R25, R26, R28, R29, R30, R31, R32: 47k; R_Axial_DIN0207_L6.3mm_D2.5mm_P5.08mm_Vertical
R2, R3, R4: 10k; R_Axial_DIN0207_L6.3mm_D2.5mm_P5.08mm_Vertical
R5, R24, R27: 22k; R_Axial_DIN0207_L6.3mm_D2.5mm_P5.08mm_Vertical
R33, R34: 1k; R_Axial_DIN0207_L6.3mm_D2.5mm_P5.08mm_Vertical

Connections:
+5V: C1.1, C2.1, J1.1, J1.2, J1.64, R1.2, R2.2, R3.2, R4.2, R5.2, R6.1, R7.1, R8.1, R9.1, R10.1, R11.2, R12.2, R13.2, R14.2, R15.1, R16.1, R17.1, R18.1, R19.1, R20.2, R21.2, R22.2, R23.2, R24.2, R25.1, R26.1, R27.1, R28.1, R29.1, R30.2, R31.2, R32.2, R33.2, R34.1
CLK: J1.6, Q1.2 (G), Q3.2 (G)
CLKN: Q1.3 (D), Q5.2 (G), R1.1
ENRA: Q50.3 (D), Q53.2 (G), Q54.2 (G), R27.2
ENRAN: Q48.3 (D), Q50.2 (G), R26.2
GND: C1.2, C2.2, J1.3, J1.4, J1.5, J1.7, J1.63, J2.2, J2.3, J2.4, J2.5, J2.6, J3.2, J3.3, J3.4, J3.5, J3.6, J4.11, J4.12, Q1.1 (S), Q2.1 (S), Q3.1 (S), Q4.1 (S), Q5.1 (S), Q6.1 (S), Q7.1 (S), Q8.1 (S), Q10.1 (S), Q11.1 (S), Q12.1 (S), Q13.1 (S), Q15.1 (S), Q16.1 (S), Q17.1 (S), Q18.1 (S), Q20.1 (S), Q22.1 (S), Q24.1 (S), Q27.1 (S), Q28.1 (S), Q30.1 (S), Q32.1 (S), Q34.1 (S), Q37.1 (S), Q38.1 (S), Q40.1 (S), Q42.1 (S), Q44.1 (S), Q47.1 (S), Q49.1 (S), Q50.1 (S), Q51.1 (S), Q53.1 (S), Q55.1 (S), Q57.1 (S), Q60.1 (S), Q61.1 (S), Q62.1 (S)
LOADN: Q7.3 (D), Q8.3 (D), Q19.2 (G), R5.1
unnamed: D1.2 (A), R33.1
unnamed: D1.1 (K), Q61.3 (D)
unnamed: D2.2 (A), R34.2
unnamed: D2.1 (K), Q62.3 (D)
unnamed: Q9.1 (S), Q10.3 (D)
unnamed: Q14.1 (S), Q15.3 (D)
unnamed: Q19.1 (S), Q20.3 (D)
unnamed: Q21.1 (S), Q22.3 (D)
unnamed: Q23.1 (S), Q24.3 (D)
unnamed: Q25.1 (S), Q26.3 (D)
unnamed: Q26.1 (S), Q27.3 (D)
unnamed: Q29.1 (S), Q30.3 (D)
unnamed: Q31.1 (S), Q32.3 (D)
unnamed: Q33.1 (S), Q34.3 (D)
unnamed: Q35.1 (S), Q36.3 (D)
unnamed: Q36.1 (S), Q37.3 (D)
unnamed: Q39.1 (S), Q40.3 (D)
unnamed: Q41.1 (S), Q42.3 (D)
unnamed: Q43.1 (S), Q44.3 (D)
unnamed: Q45.1 (S), Q46.3 (D)
unnamed: Q46.1 (S), Q47.3 (D)
unnamed: Q48.1 (S), Q49.3 (D)
unnamed: Q52.1 (S), Q53.3 (D)
unnamed: Q54.1 (S), Q55.3 (D)
unnamed: Q56.1 (S), Q57.3 (D)
unnamed: Q58.1 (S), Q59.3 (D)
unnamed: Q59.1 (S), Q60.3 (D)
OPR5: J4.6, Q22.2 (G)
PC5: J1.25, Q10.2 (G), Q12.2 (G), Q14.2 (G), Q43.3 (D), Q45.2 (G), Q51.2 (G), Q52.2 (G), Q61.2 (G), R24.1
PC5_dn: Q28.3 (D), Q32.2 (G), R16.2
PC5_m1: Q29.3 (D), Q33.2 (G), R17.2
PC5_m2: Q31.3 (D), Q36.2 (G), R18.2
PC5_mq: Q33.3 (D), Q35.2 (G), Q38.2 (G), Q39.2 (G), R19.2
PC5_mqi: Q38.3 (D), Q42.2 (G), R21.1
PC5_mqn: Q34.2 (G), Q35.3 (D), R20.1
PC5_qn: Q44.2 (G), Q45.3 (D), R25.2
PC5_sa: Q39.3 (D), Q43.2 (G), R22.1
PC5_sb: Q41.3 (D), Q46.2 (G), R23.1
PCL: J1.52, Q7.2 (G), Q21.2 (G)
PCR: J4.9, Q8.2 (G), Q23.2 (G)
PD5: Q25.3 (D), Q28.2 (G), Q29.2 (G), R15.2
PD5_1: Q19.3 (D), Q25.2 (G), R12.1
PD5_2: Q21.3 (D), Q26.2 (G), R13.1
PD5_3: Q23.3 (D), Q27.2 (G), R14.1
PH1: Q3.3 (D), Q4.3 (D), Q6.2 (G), Q30.2 (G), Q31.2 (G), Q49.2 (G), R3.1
PH2: Q4.2 (G), Q5.3 (D), Q6.3 (D), Q40.2 (G), Q41.2 (G), R4.1
PX5: Q17.3 (D), Q18.3 (D), Q20.2 (G), R11.1
PX5_a: Q14.3 (D), Q16.2 (G), R9.2
PX5_d: Q16.3 (D), Q18.2 (G), R10.2
PX5_n: Q12.3 (D), Q13.3 (D), Q17.2 (G), R8.2
RA5: Q24.2 (G), Q56.3 (D), Q58.2 (G), Q62.2 (G), R31.1
RA5_dn: Q51.3 (D), Q55.2 (G), R28.2
RA5_m1: Q52.3 (D), Q56.2 (G), R29.2
RA5_m2: Q54.3 (D), Q59.2 (G), R30.1
RA5_qn: Q57.2 (G), Q58.3 (D), R32.1
RAI: J4.10, Q48.2 (G)
RST: J1.8, Q2.2 (G)
RSTN: Q2.3 (D), Q37.2 (G), Q47.2 (G), Q60.2 (G), R2.1
TC5: J2.1, Q9.2 (G), Q13.2 (G), Q15.2 (G)
TC6: J3.1, Q11.3 (D), R7.2
TC6N: Q9.3 (D), Q11.2 (G), R6.2

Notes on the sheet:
NIBBLE CARD CTR5 - COUNTER BIT 5: program counter bit 5 and return register bit 5
Cell: 2N7000 + 47k pull-up (NMOS, see docs/gate-cell.md). 62 transistors, 34 resistors, 2 LEDs, 100 x 100 mm (docs/cards.md). From the bus header: PCE (count), PCL (load the jump target), CLK, RST. To the bus header: PC5. From the sequencer over the LINK ribbon (2x6, chained along the eight counter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
TWO-PHASE CLOCK and RSTN (as on the register and sequencer boards)
INPUT SELECT: LOADN = neither PCL nor PCR: the counter counts (or holds) unless a load line is high
COUNT CARRY: t(i) comes from the card below over the link (PCE on bit 0); t(i+1) = t(i) and PC(i) goes to the card above. Bit i toggles when t(i) is 1.
PROGRAM COUNTER: D = LOADN.(PC xor t) + PCL.OPR + PCR.RA, then a master-slave flip-flop with reset
RETURN REGISTER: transparent latches open while RAI and PH1
INDICATORS: PC, RA
LED_PC5
LED_RA5
Decoupling
Mounting holes
LINK IN from the bit below
LINK OUT to the bit above
LINK ribbon from the sequencer: this card takes OPR5, PCR and RAI

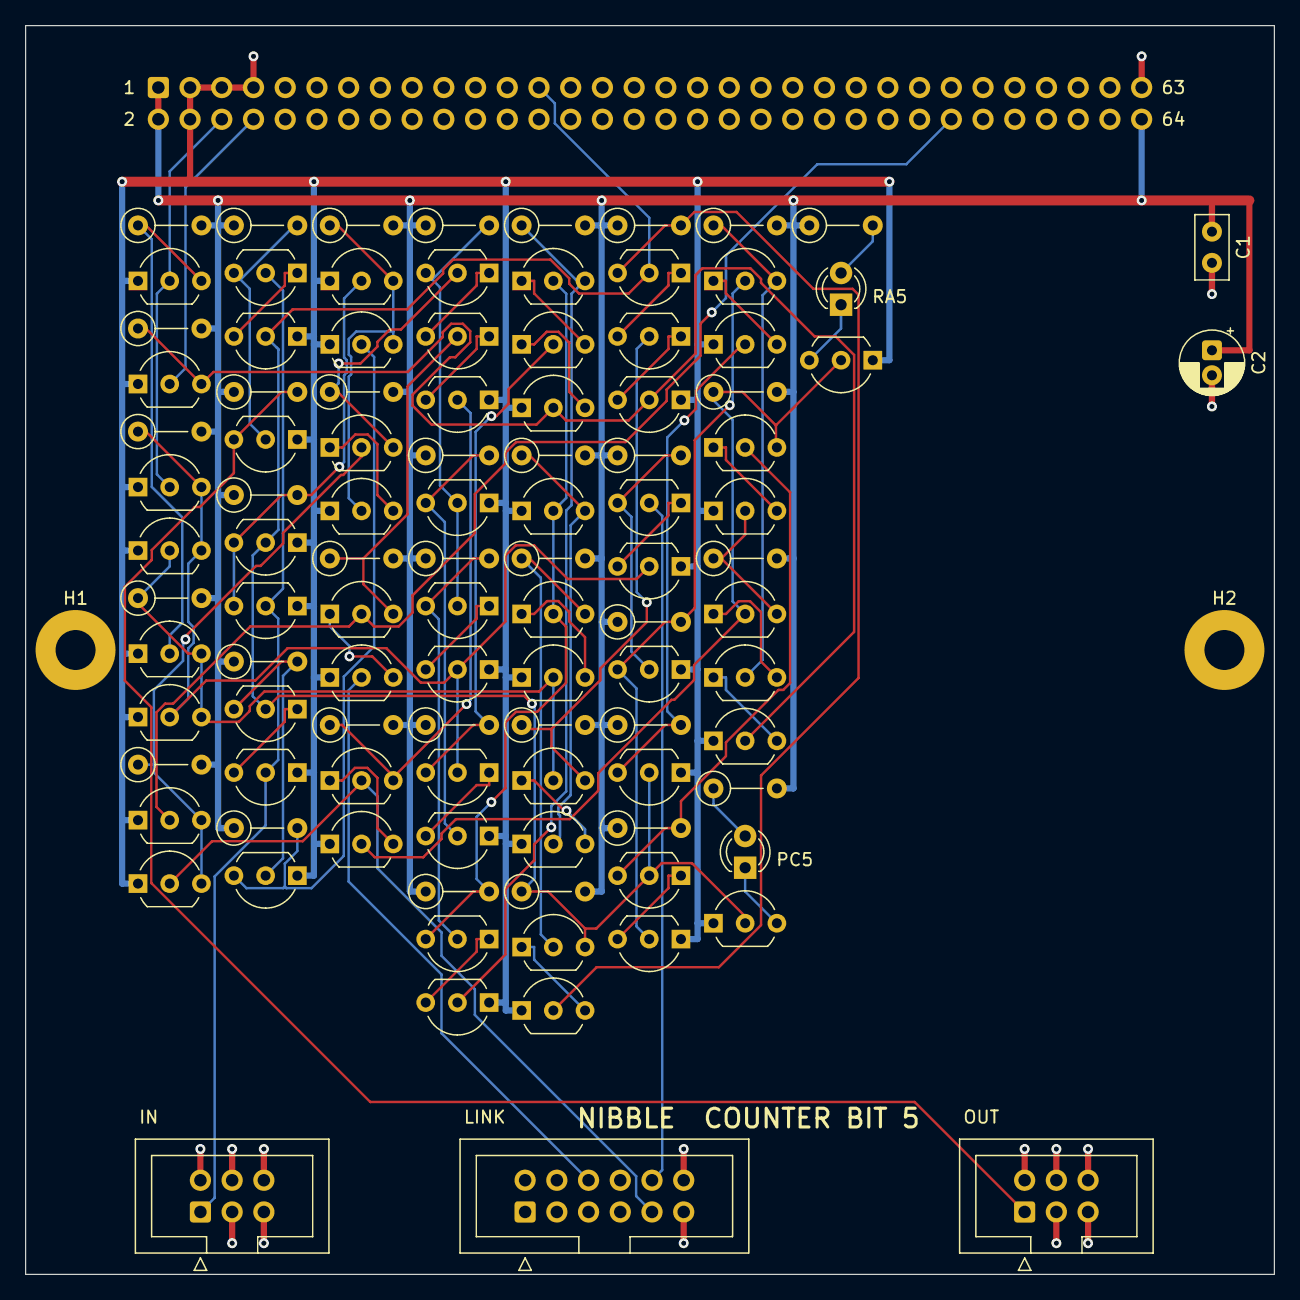
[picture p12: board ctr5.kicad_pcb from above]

Board: 2 copper layers, 100.0 x 100.0 mm, 106 parts (1 on the bottom side), 68 nets.

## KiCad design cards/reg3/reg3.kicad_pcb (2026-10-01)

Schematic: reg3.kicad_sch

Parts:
C1: 100n; C_Disc_D5.0mm_W2.5mm_P2.50mm
C2: 10u; CP_Radial_D5.0mm_P2.00mm
D1, D2, D3: LED; LED_D3.0mm
H1, H2: M3; MountingHole_3.2mm_M3_Pad
J1: BUS; IDC-Header_2x32_P2.54mm_Vertical
Q1, Q2, Q3, Q4, Q5, Q6, Q7, Q8, Q9, Q10, Q11, Q12, Q13, Q14, Q15, Q16, Q17, Q18, Q19, Q20, Q21, Q22, Q23, Q24, Q25, Q26, Q27, Q28, Q29, Q30, Q31, Q32, Q33, Q34, Q35, Q36, Q37, Q38, Q39, Q40, Q41, Q42, Q43, Q44, Q45, Q46, Q47, Q48, Q49, Q50, Q51, Q52, Q53, Q54, Q55, Q56, Q57, Q58, Q59, Q60, Q61, Q62, Q63, Q64, Q65, Q66, Q67, Q68, Q69, Q70, Q71, Q72, Q73, Q74, Q75, Q76, Q77, Q78, Q79, Q80, Q81, Q82, Q83, Q84, Q85, Q86, Q87, Q88, Q89, Q90, Q91, Q92, Q93, Q94, Q95, Q96, Q97, Q98, Q99: 2N7000; TO-92_Inline_Wide
R1, R4, R5, R6, R7, R8, R9, R10, R11, R12, R13, R14, R15, R16, R17, R19, R20, R21, R22, R23, R24, R25, R26, R27, R28, R29, R30, R31, R32, R34, R35, R36, R37, R38, R39, R40, R41, R42, R43, R44, R45, R46, R47, R48, R49, R50, R51: 47k; R_Axial_DIN0207_L6.3mm_D2.5mm_P5.08mm_Vertical
R2, R3: 10k; R_Axial_DIN0207_L6.3mm_D2.5mm_P5.08mm_Vertical
R18, R33: 22k; R_Axial_DIN0207_L6.3mm_D2.5mm_P5.08mm_Vertical
R52, R53, R54: 1k; R_Axial_DIN0207_L6.3mm_D2.5mm_P5.08mm_Vertical

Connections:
+5V: C1.1, C2.1, J1.1, J1.2, J1.64, R1.2, R2.2, R3.2, R4.2, R5.2, R6.2, R7.1, R8.1, R9.1, R10.1, R11.1, R12.1, R13.2, R14.2, R15.2, R16.2, R17.2, R18.2, R19.1, R20.1, R21.1, R22.1, R23.1, R24.2, R25.2, R26.2, R27.2, R28.2, R29.2, R30.1, R31.1, R32.1, R33.1, R34.1, R35.1, R36.2, R37.2, R38.2, R39.2, R40.2, R41.2, R42.1, R43.1, R44.1, R45.1, R46.1, R47.1, R48.2, R49.2, R50.2, R51.2, R52.2, R53.1, R54.1
A3: J1.15, Q14.2 (G), Q32.3 (D), Q34.2 (G), Q41.2 (G), Q91.2 (G), Q98.2 (G), R18.1
A3_dn: Q18.3 (D), Q22.2 (G), R10.2
A3_m1: Q19.3 (D), Q23.2 (G), R11.2
A3_m2: Q21.3 (D), Q26.2 (G), R12.2
A3_mq: Q23.3 (D), Q25.2 (G), Q27.2 (G), Q28.2 (G), R13.1
A3_mqi: Q27.3 (D), Q31.2 (G), R15.1
A3_mqn: Q24.2 (G), Q25.3 (D), R14.1
A3_qn: Q33.2 (G), Q34.3 (D), R19.2
A3_sa: Q28.3 (D), Q32.2 (G), R16.1
A3_sb: Q30.3 (D), Q35.2 (G), R17.1
AB: J1.45, Q8.2 (G), Q11.2 (G)
AI: J1.42, Q7.2 (G), Q9.2 (G)
AO: J1.41, Q90.2 (G)
AON3: Q90.3 (D), Q94.2 (G), R49.1
B3: J1.19, Q12.2 (G), Q43.2 (G), Q61.3 (D), Q63.2 (G), Q93.2 (G), Q99.2 (G), R33.2
B3_dn: Q47.3 (D), Q51.2 (G), R25.1
B3_m1: Q48.3 (D), Q52.2 (G), R26.1
B3_m2: Q50.3 (D), Q55.2 (G), R27.1
B3_mq: Q52.3 (D), Q54.2 (G), Q56.2 (G), Q57.2 (G), R28.1
B3_mqi: Q56.3 (D), Q60.2 (G), R30.2
B3_mqn: Q53.2 (G), Q54.3 (D), R29.1
B3_qn: Q62.2 (G), Q63.3 (D), R34.2
B3_sa: Q57.3 (D), Q61.2 (G), R31.2
B3_sb: Q59.3 (D), Q64.2 (G), R32.2
BA: J1.46, Q37.2 (G), Q40.2 (G)
BD3: Q94.3 (D), Q96.2 (G), R51.1
BI: J1.44, Q36.2 (G), Q38.2 (G)
BO: J1.43, Q92.2 (G)
BON3: Q92.3 (D), Q95.2 (G), R50.1
BUS3#: J1.11, Q6.2 (G), Q96.3 (D)
CLK: J1.6, Q1.2 (G), Q2.2 (G)
CLKN: Q1.3 (D), Q4.2 (G), R1.1
D3: Q6.3 (D), Q10.2 (G), Q39.2 (G), Q67.2 (G), R4.1
DA3: Q15.3 (D), Q18.2 (G), Q19.2 (G), R9.2
DA3_1: Q9.3 (D), Q15.2 (G), R6.1
DA3_2: Q11.3 (D), Q16.2 (G), R7.2
DA3_3: Q13.3 (D), Q17.2 (G), R8.2
DB3: Q44.3 (D), Q47.2 (G), Q48.2 (G), R24.1
DB3_1: Q38.3 (D), Q44.2 (G), R21.2
DB3_2: Q40.3 (D), Q45.2 (G), R22.2
DB3_3: Q42.3 (D), Q46.2 (G), R23.2
DO3: Q70.3 (D), Q72.2 (G), Q73.2 (G), R38.1
DO3_1: Q66.3 (D), Q70.2 (G), R36.1
DO3_2: Q68.3 (D), Q71.2 (G), R37.1
GND: C1.2, C2.2, J1.3, J1.4, J1.5, J1.7, J1.63, Q1.1 (S), Q2.1 (S), Q3.1 (S), Q4.1 (S), Q5.1 (S), Q6.1 (S), Q7.1 (S), Q8.1 (S), Q10.1 (S), Q12.1 (S), Q14.1 (S), Q17.1 (S), Q18.1 (S), Q20.1 (S), Q22.1 (S), Q24.1 (S), Q26.1 (S), Q27.1 (S), Q29.1 (S), Q31.1 (S), Q33.1 (S), Q35.1 (S), Q36.1 (S), Q37.1 (S), Q39.1 (S), Q41.1 (S), Q43.1 (S), Q46.1 (S), Q47.1 (S), Q49.1 (S), Q51.1 (S), Q53.1 (S), Q55.1 (S), Q56.1 (S), Q58.1 (S), Q60.1 (S), Q62.1 (S), Q64.1 (S), Q65.1 (S), Q67.1 (S), Q69.1 (S), Q71.1 (S), Q72.1 (S), Q74.1 (S), Q76.1 (S), Q78.1 (S), Q80.1 (S), Q81.1 (S), Q83.1 (S), Q85.1 (S), Q87.1 (S), Q89.1 (S), Q91.1 (S), Q93.1 (S), Q95.1 (S), Q96.1 (S), Q97.1 (S), Q98.1 (S), Q99.1 (S)
HOLDA: Q7.3 (D), Q8.3 (D), Q13.2 (G), R5.1
HOLDB: Q36.3 (D), Q37.3 (D), Q42.2 (G), R20.2
unnamed: D1.2 (A), R52.1
unnamed: D1.1 (K), Q97.3 (D)
unnamed: D2.2 (A), R53.2
unnamed: D2.1 (K), Q98.3 (D)
unnamed: D3.2 (A), R54.2
unnamed: D3.1 (K), Q99.3 (D)
unnamed: Q9.1 (S), Q10.3 (D)
unnamed: Q11.1 (S), Q12.3 (D)
unnamed: Q13.1 (S), Q14.3 (D)
unnamed: Q15.1 (S), Q16.3 (D)
unnamed: Q16.1 (S), Q17.3 (D)
unnamed: Q19.1 (S), Q20.3 (D)
unnamed: Q21.1 (S), Q22.3 (D)
unnamed: Q23.1 (S), Q24.3 (D)
unnamed: Q25.1 (S), Q26.3 (D)
unnamed: Q28.1 (S), Q29.3 (D)
unnamed: Q30.1 (S), Q31.3 (D)
unnamed: Q32.1 (S), Q33.3 (D)
unnamed: Q34.1 (S), Q35.3 (D)
unnamed: Q38.1 (S), Q39.3 (D)
unnamed: Q40.1 (S), Q41.3 (D)
unnamed: Q42.1 (S), Q43.3 (D)
unnamed: Q44.1 (S), Q45.3 (D)
unnamed: Q45.1 (S), Q46.3 (D)
unnamed: Q48.1 (S), Q49.3 (D)
unnamed: Q50.1 (S), Q51.3 (D)
unnamed: Q52.1 (S), Q53.3 (D)
unnamed: Q54.1 (S), Q55.3 (D)
unnamed: Q57.1 (S), Q58.3 (D)
unnamed: Q59.1 (S), Q60.3 (D)
unnamed: Q61.1 (S), Q62.3 (D)
unnamed: Q63.1 (S), Q64.3 (D)
unnamed: Q66.1 (S), Q67.3 (D)
unnamed: Q68.1 (S), Q69.3 (D)
unnamed: Q70.1 (S), Q71.3 (D)
unnamed: Q73.1 (S), Q74.3 (D)
unnamed: Q75.1 (S), Q76.3 (D)
unnamed: Q77.1 (S), Q78.3 (D)
unnamed: Q79.1 (S), Q80.3 (D)
unnamed: Q82.1 (S), Q83.3 (D)
unnamed: Q84.1 (S), Q85.3 (D)
unnamed: Q86.1 (S), Q87.3 (D)
unnamed: Q88.1 (S), Q89.3 (D)
unnamed: Q90.1 (S), Q91.3 (D)
unnamed: Q92.1 (S), Q93.3 (D)
unnamed: Q94.1 (S), Q95.3 (D)
OI: J1.48, Q65.2 (G), Q66.2 (G)
OIN: Q65.3 (D), Q68.2 (G), R35.2
OUT3: Q69.2 (G), Q86.3 (D), Q88.2 (G), Q97.2 (G), R47.2
OUT3_dn: Q72.3 (D), Q76.2 (G), R39.1
OUT3_m1: Q73.3 (D), Q77.2 (G), R40.1
OUT3_m2: Q75.3 (D), Q80.2 (G), R41.1
OUT3_mq: Q77.3 (D), Q79.2 (G), Q81.2 (G), Q82.2 (G), R42.2
OUT3_mqi: Q81.3 (D), Q85.2 (G), R44.2
OUT3_mqn: Q78.2 (G), Q79.3 (D), R43.2
OUT3_qn: Q87.2 (G), Q88.3 (D), R48.1
OUT3_sa: Q82.3 (D), Q86.2 (G), R45.2
OUT3_sb: Q84.3 (D), Q89.2 (G), R46.2
PH1: Q2.3 (D), Q3.3 (D), Q5.2 (G), Q20.2 (G), Q21.2 (G), Q49.2 (G), Q50.2 (G), Q74.2 (G), Q75.2 (G), R2.1
PH2: Q3.2 (G), Q4.3 (D), Q5.3 (D), Q29.2 (G), Q30.2 (G), Q58.2 (G), Q59.2 (G), Q83.2 (G), Q84.2 (G), R3.1

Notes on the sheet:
NIBBLE CARD REG3 - REGISTER BIT 3: bit 3 of A, B and OUT
Cell: 2N7000 + 47k pull-up (NMOS, see docs/gate-cell.md). 99 transistors, 54 resistors, 3 LEDs, 100 x 100 mm (docs/cards.md). From the bus header: BUS3# (data, active low), CLK, and the control lines AI AO BI BO BA AB OI (docs/isa.md). To the bus header: A3 and B3 (for the ALU and the panel); BUS3#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
TWO-PHASE CLOCK (one per card): PH1 = NOR(CLK, PH2) opens the masters while CLK is low, PH2 = NOR(CLKN, PH1) opens the slaves while CLK is high. The cross-coupling means a phase cannot start rising until the other is fully low, so a flip-flop is never transparent.
BUS INPUT: D = NOT BUS# (the bus is active low)
REGISTER A INPUT MUX: DA = AI.D + AB.B + HOLDA.A, HOLDA = NOR(AI, AB). NAND-NAND form: three 2-input NANDs into a 3-input NAND
REGISTER A: master-slave D flip-flop, 22k pull-up on Q (A feeds the ALU, the panel, both muxes and the bus driver)
REGISTER B INPUT MUX: DB = BI.D + BA.A + HOLDB.B
REGISTER B
OUT REGISTER INPUT MUX: DO = OI.D + OIN.OUT
OUT REGISTER (the display)
BUS DRIVER: pull BUS# low when AO.A or BO.B
INDICATORS: OUT, A, B
LED_OUT3
LED_A3
LED_B3
Decoupling
Mounting holes

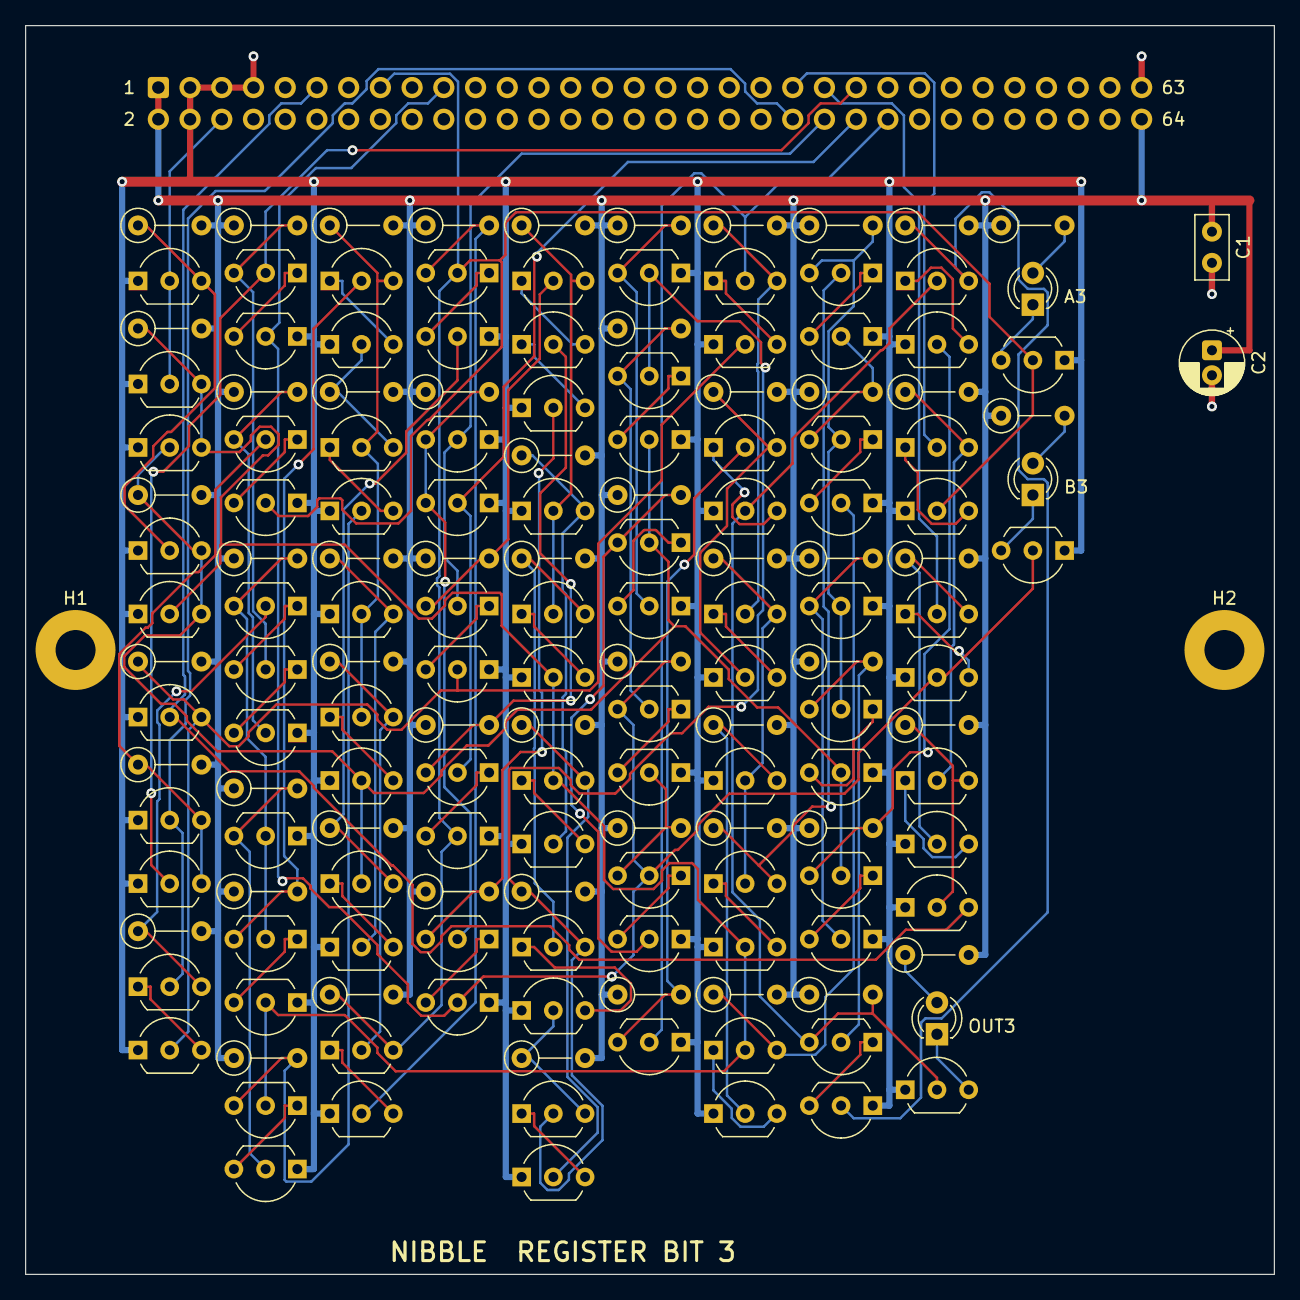
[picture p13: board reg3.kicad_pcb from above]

Board: 2 copper layers, 100.0 x 100.0 mm, 161 parts (1 on the bottom side), 108 nets.

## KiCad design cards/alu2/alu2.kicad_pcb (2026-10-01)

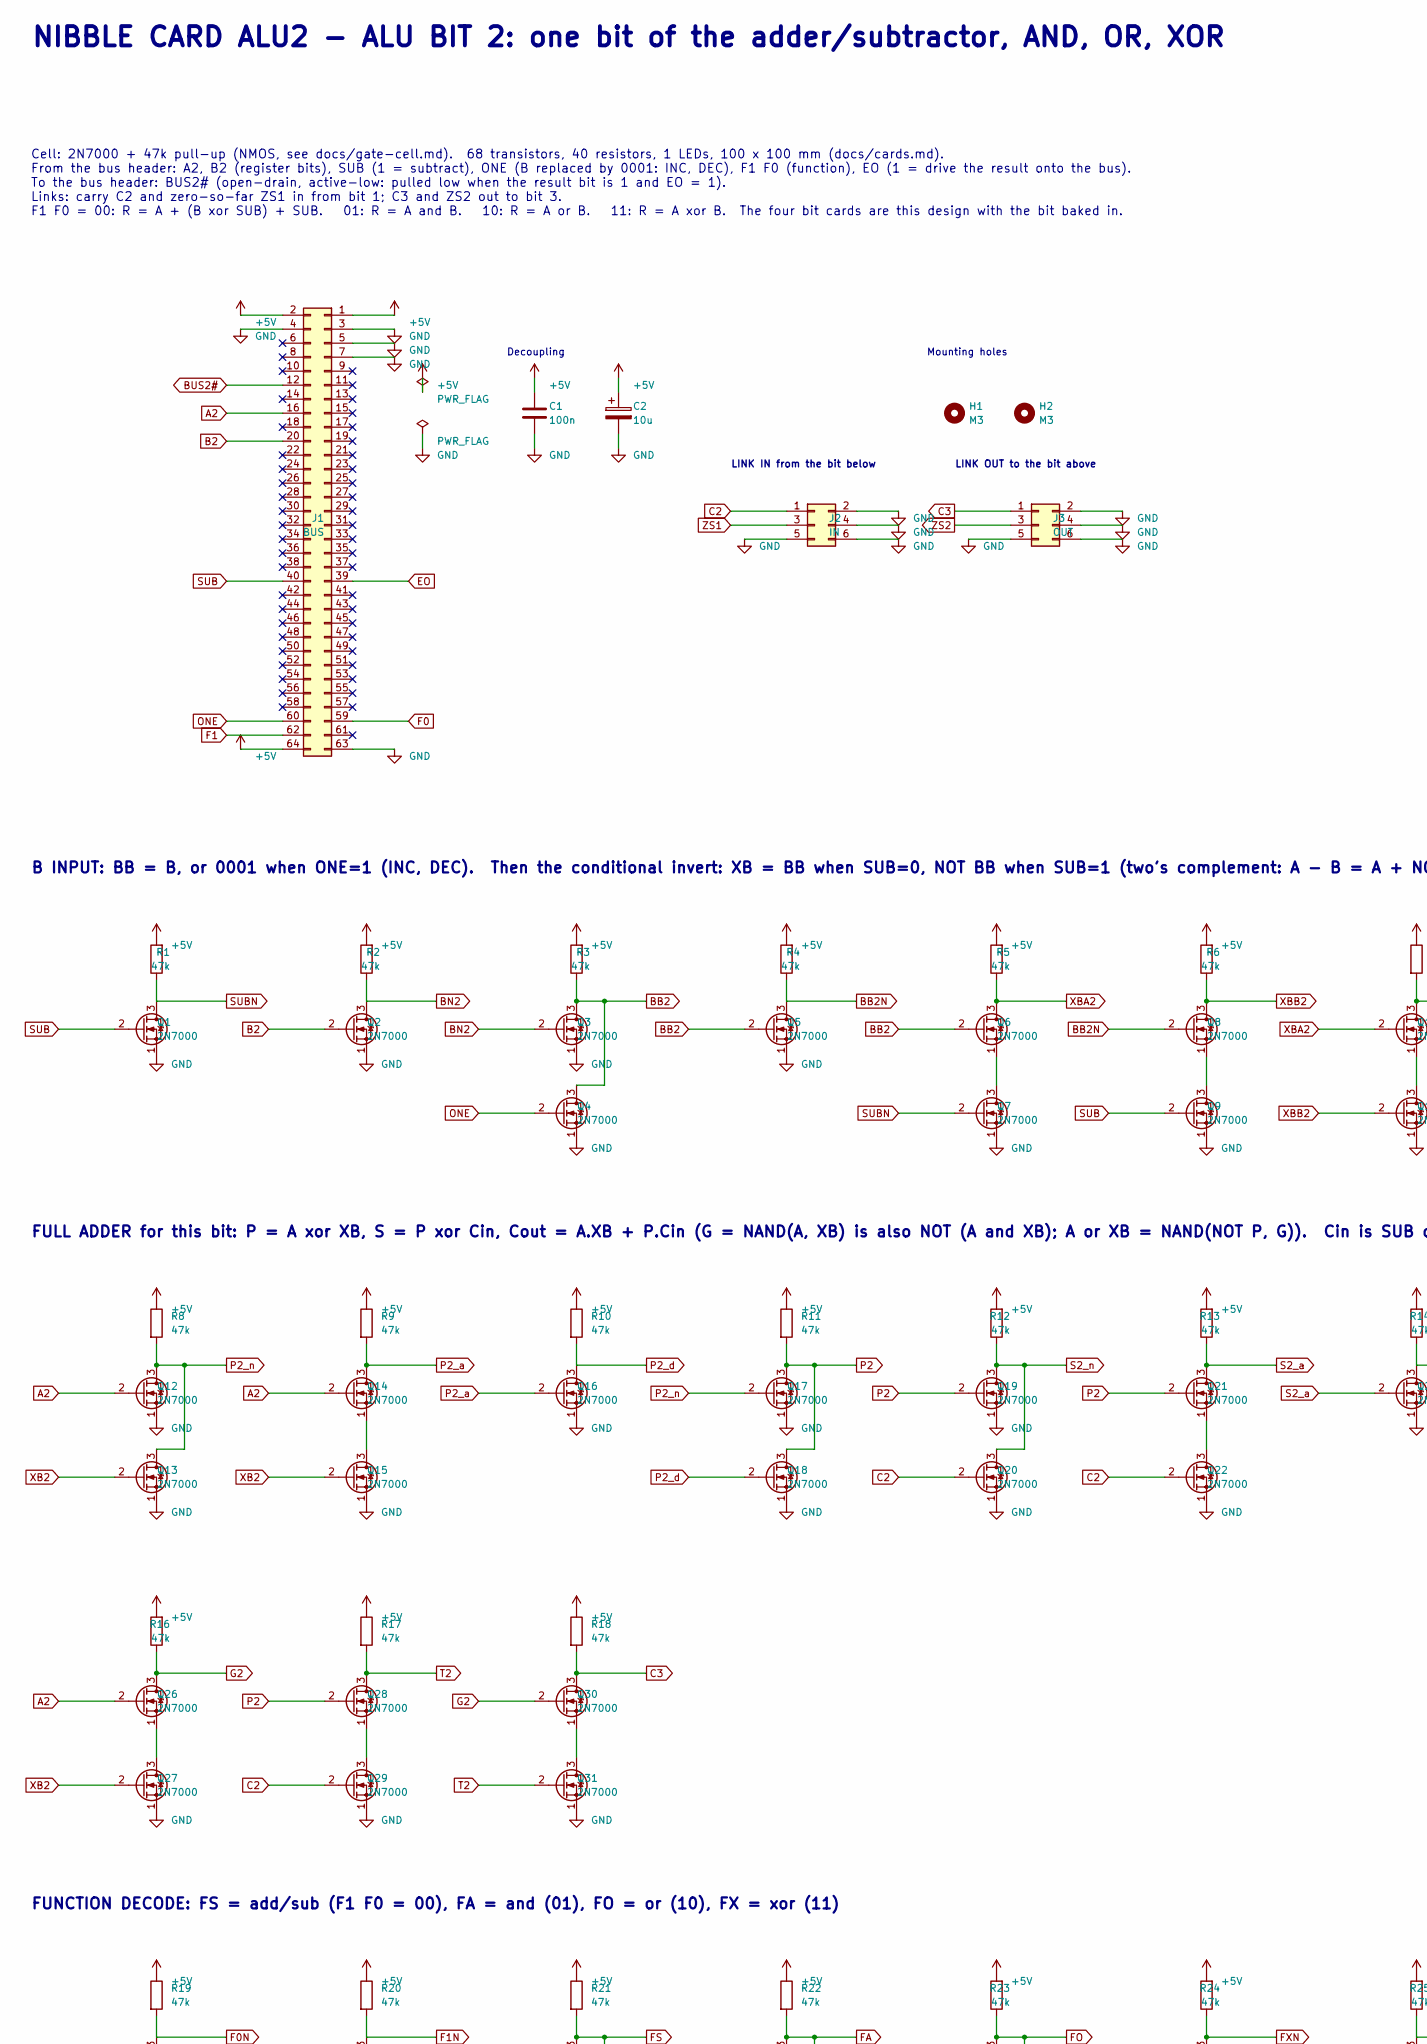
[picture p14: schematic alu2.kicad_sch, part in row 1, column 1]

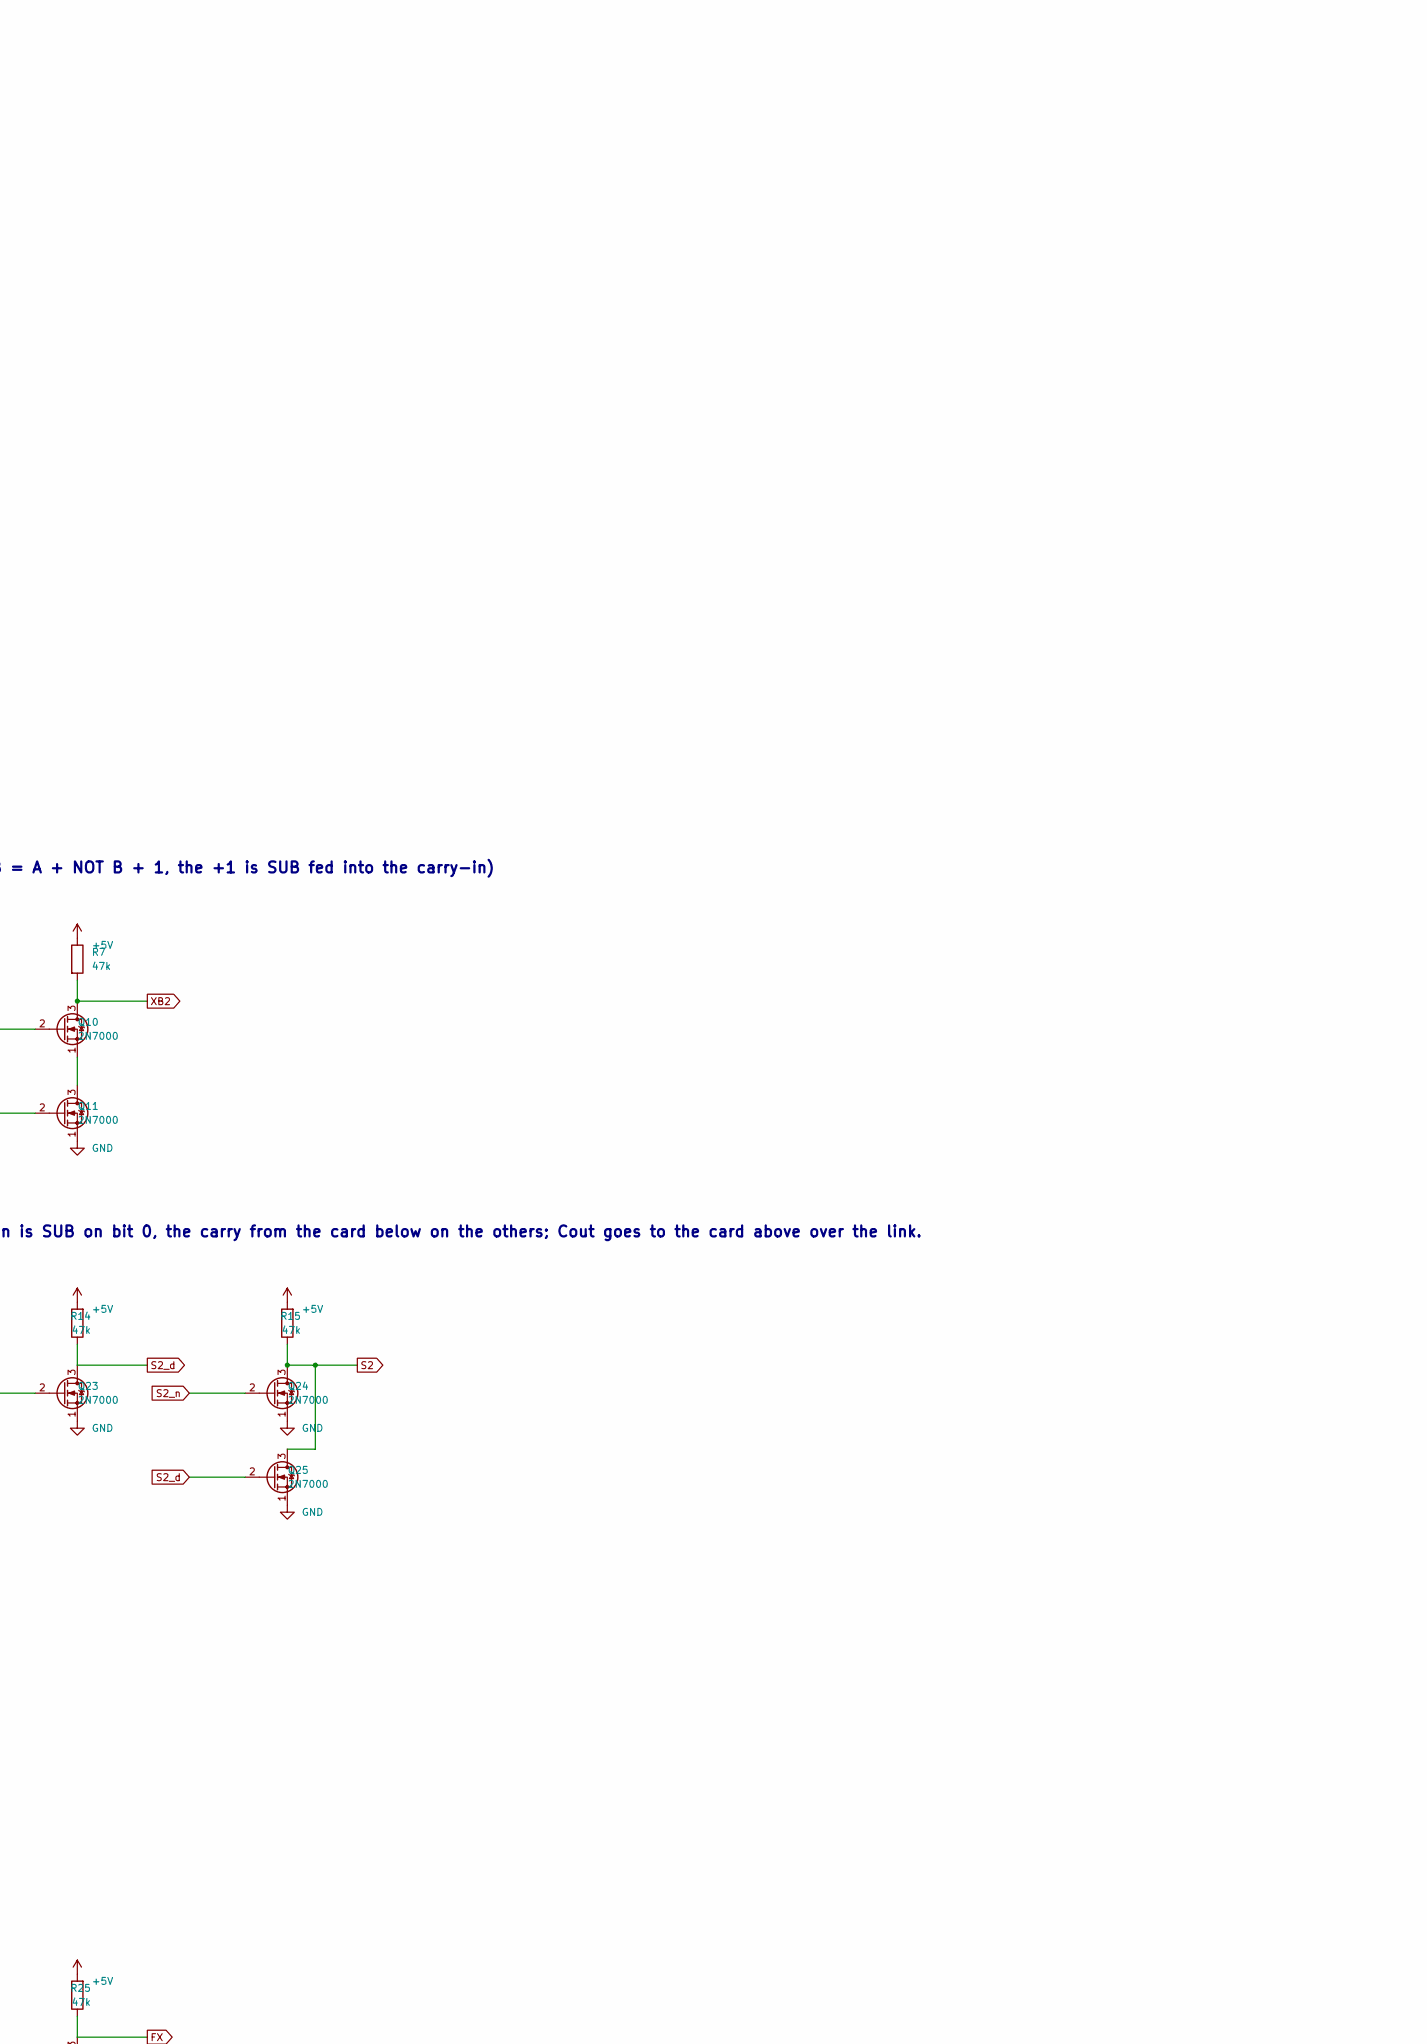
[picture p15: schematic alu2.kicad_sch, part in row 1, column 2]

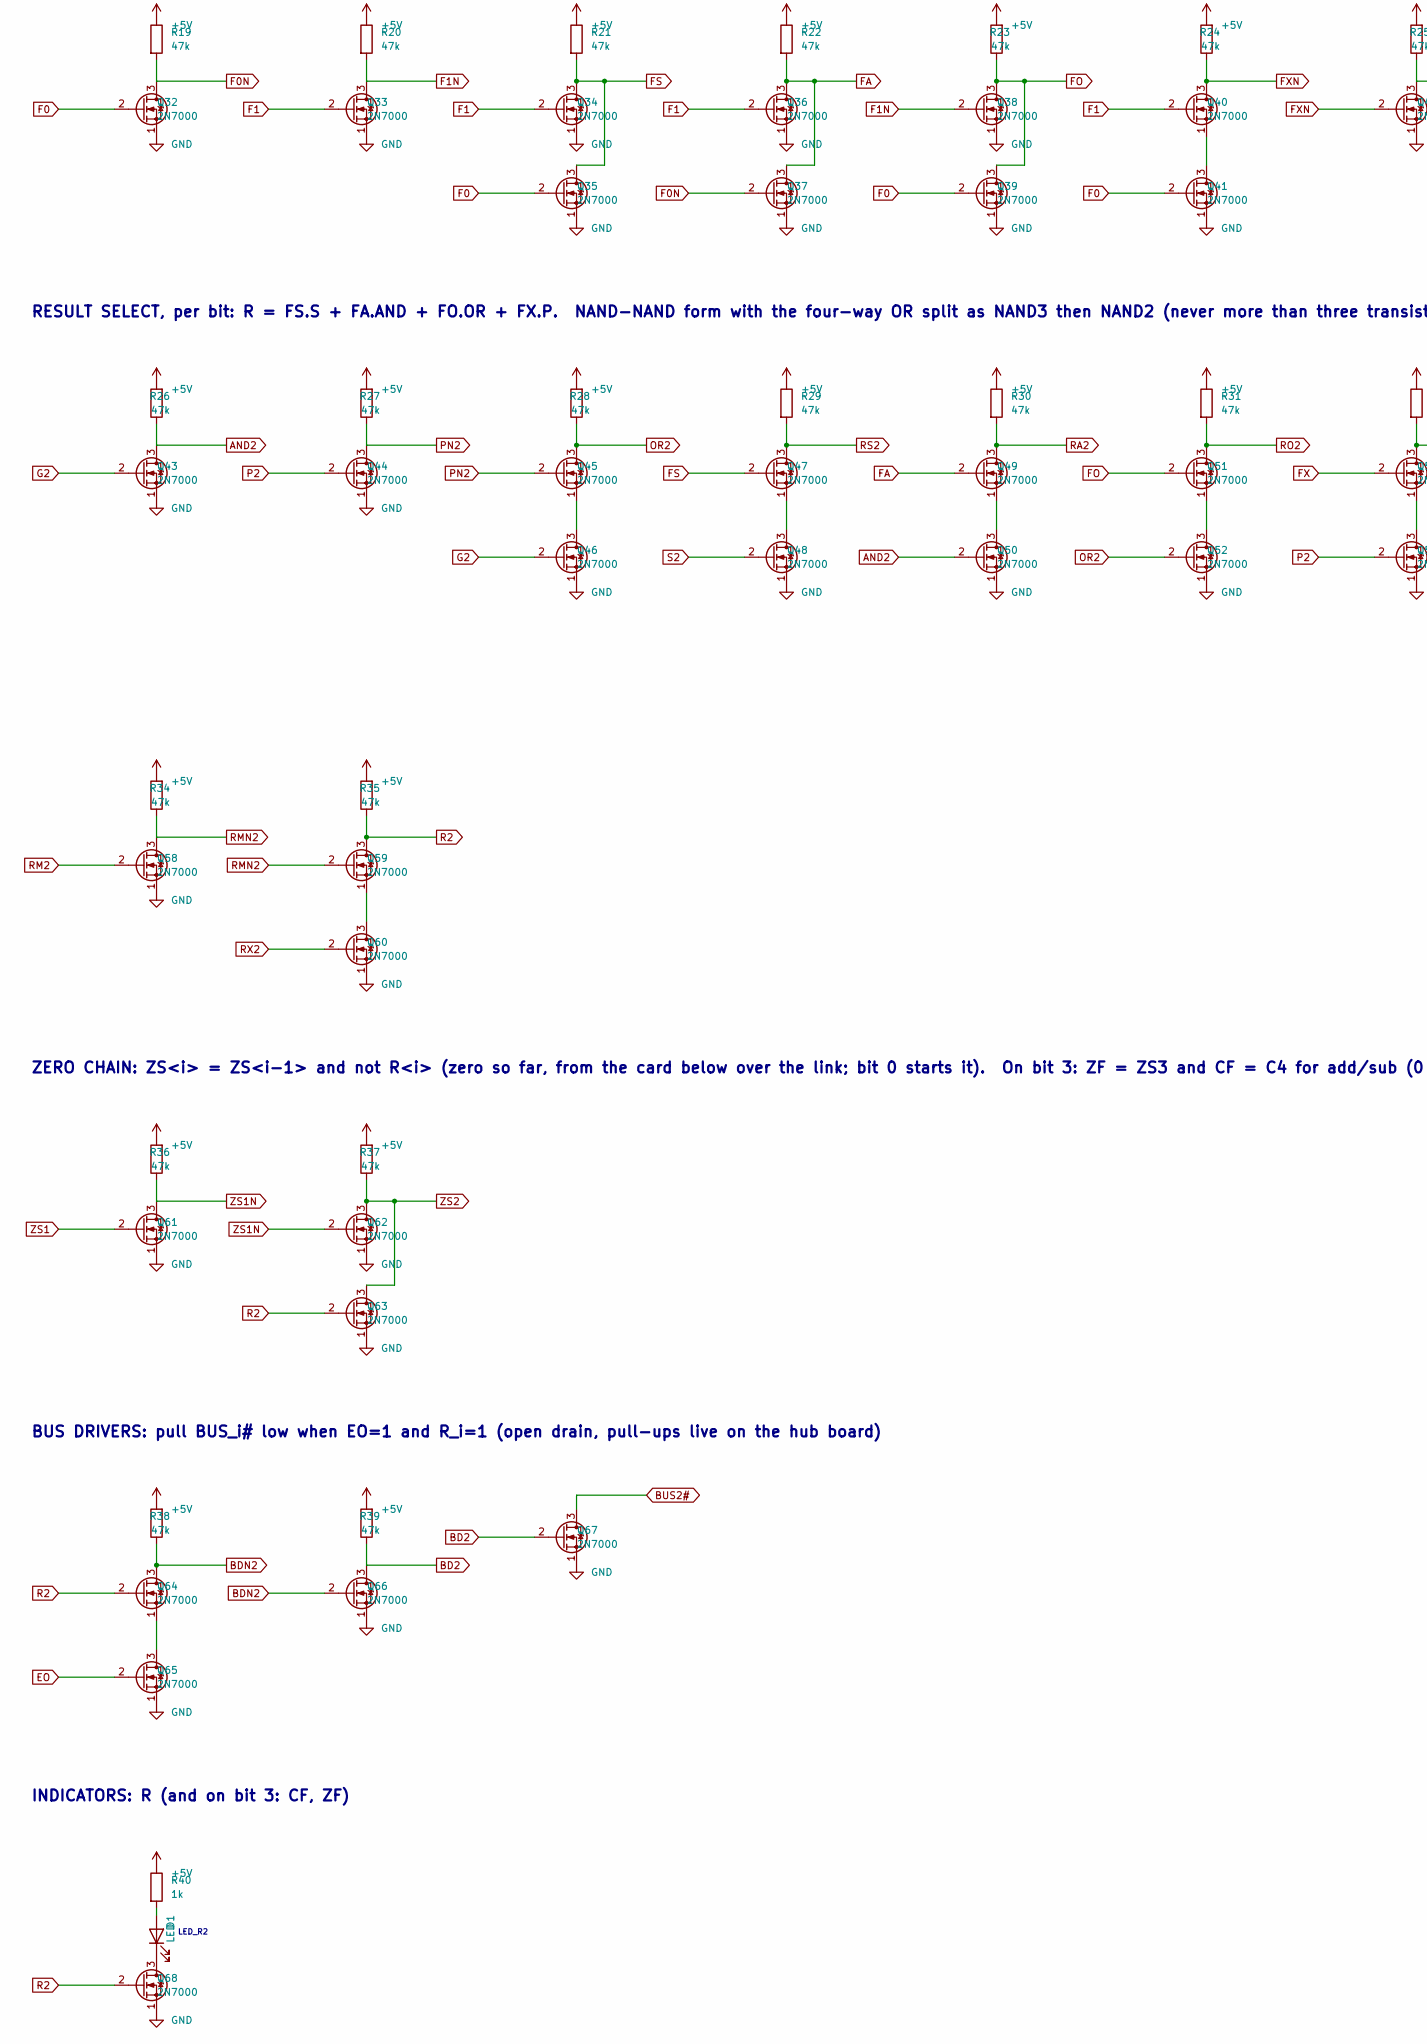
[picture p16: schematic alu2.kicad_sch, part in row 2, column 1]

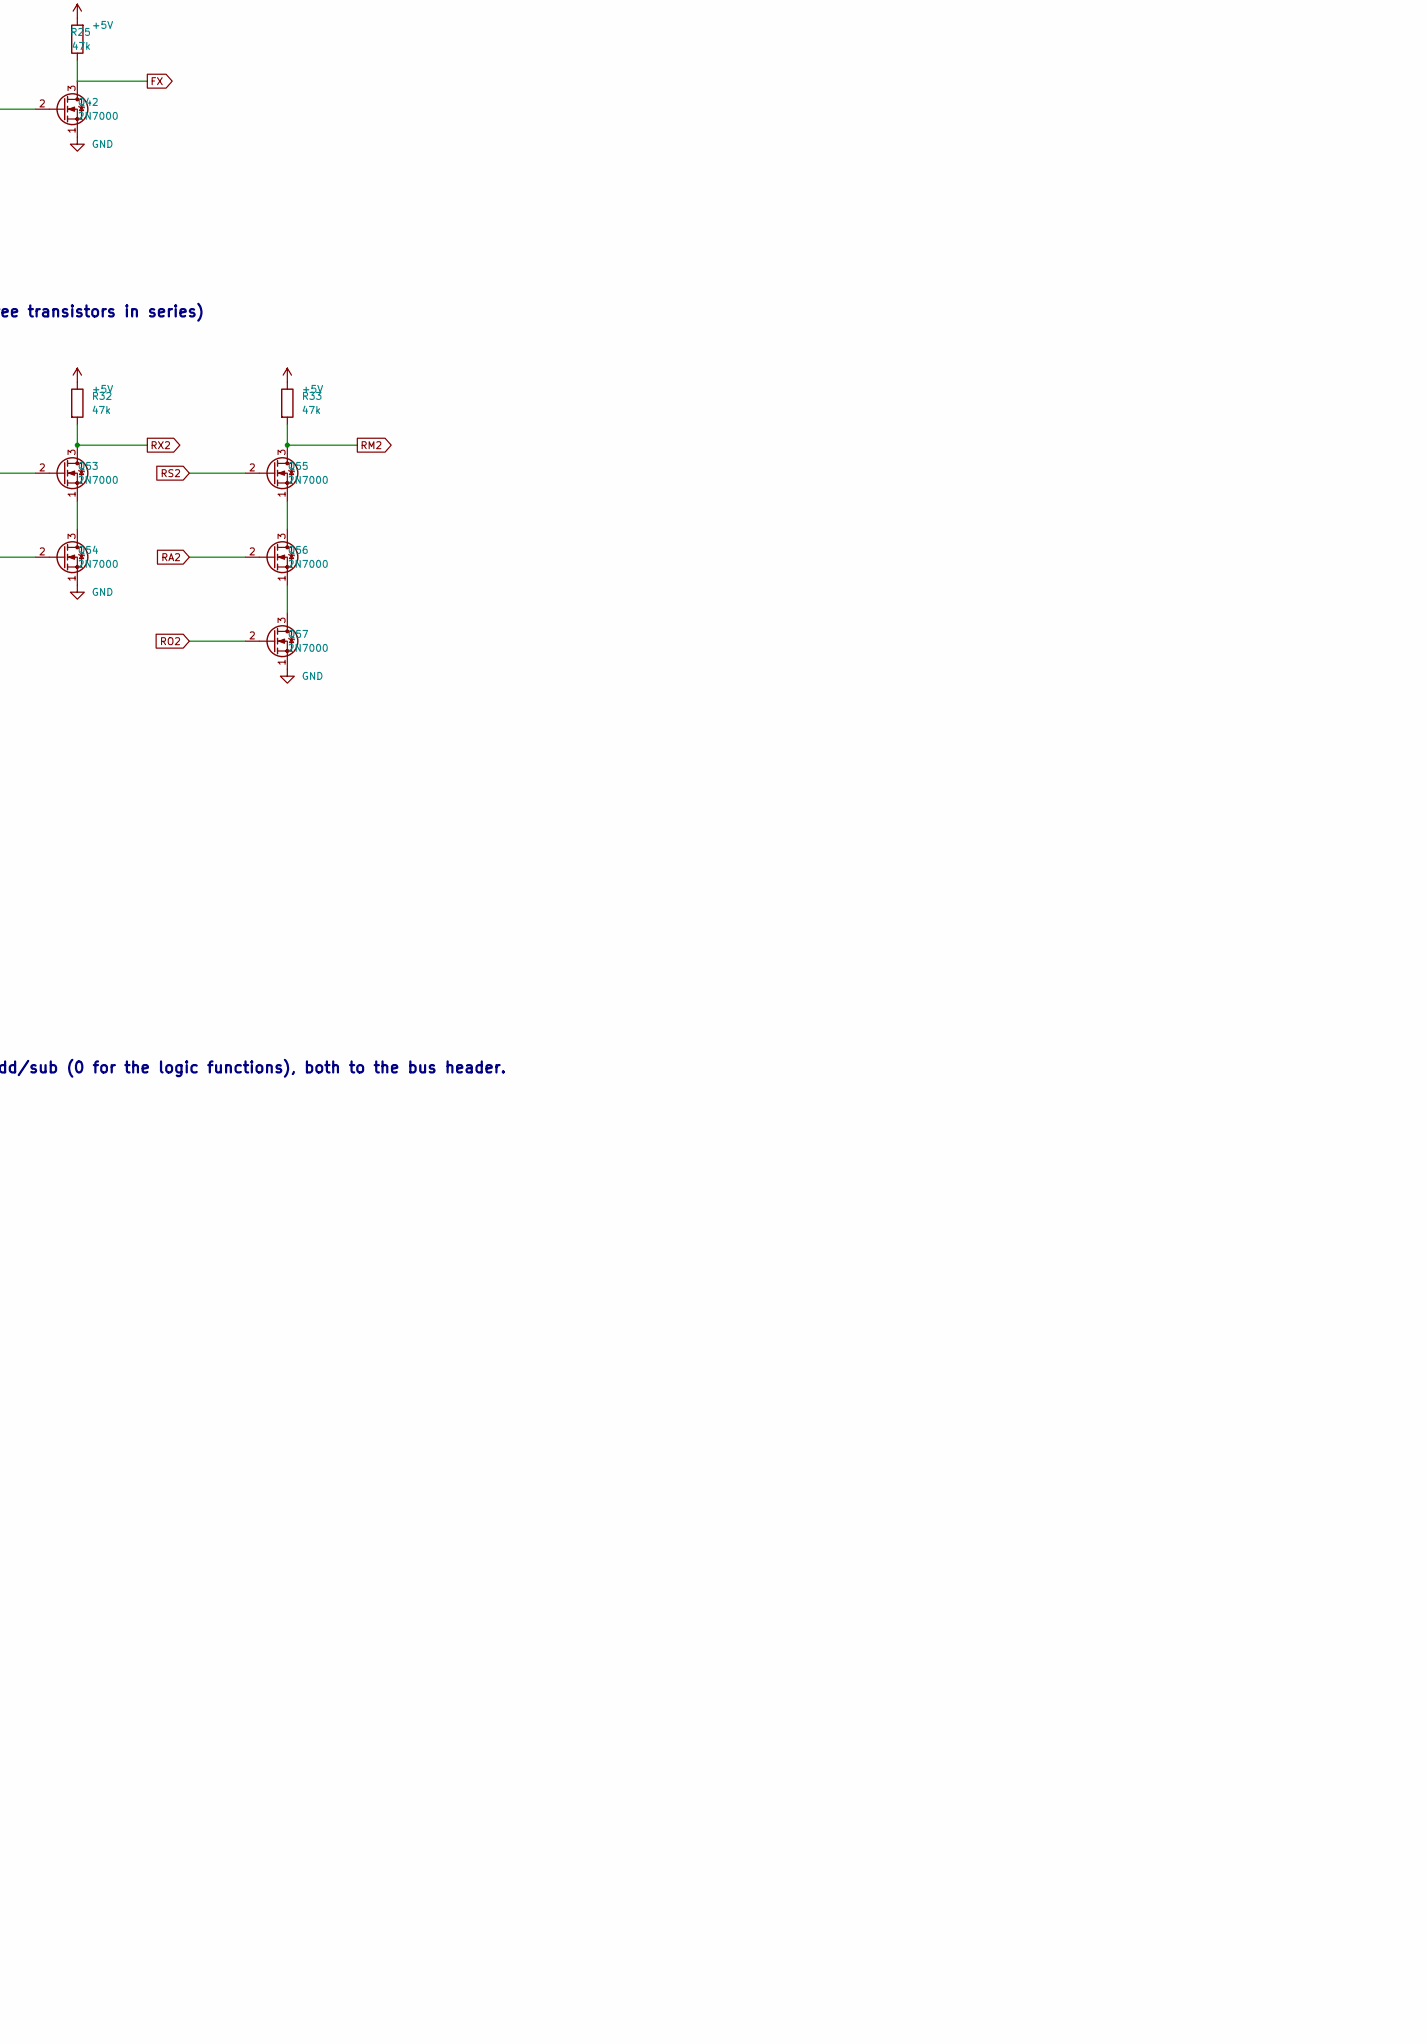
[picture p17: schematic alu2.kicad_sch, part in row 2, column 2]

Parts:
C1: 100n; C_Disc_D5.0mm_W2.5mm_P2.50mm
C2: 10u; CP_Radial_D5.0mm_P2.00mm
D1: LED; LED_D3.0mm
H1, H2: M3; MountingHole_3.2mm_M3_Pad
J1: BUS; IDC-Header_2x32_P2.54mm_Vertical
J2: IN; IDC-Header_2x03_P2.54mm_Vertical
J3: OUT; IDC-Header_2x03_P2.54mm_Vertical
Q1, Q2, Q3, Q4, Q5, Q6, Q7, Q8, Q9, Q10, Q11, Q12, Q13, Q14, Q15, Q16, Q17, Q18, Q19, Q20, Q21, Q22, Q23, Q24, Q25, Q26, Q27, Q28, Q29, Q30, Q31, Q32, Q33, Q34, Q35, Q36, Q37, Q38, Q39, Q40, Q41, Q42, Q43, Q44, Q45, Q46, Q47, Q48, Q49, Q50, Q51, Q52, Q53, Q54, Q55, Q56, Q57, Q58, Q59, Q60, Q61, Q62, Q63, Q64, Q65, Q66, Q67, Q68: 2N7000; TO-92_Inline_Wide
R1, R2, R3, R4, R5, R6, R7, R8, R9, R10, R11, R12, R13, R14, R15, R16, R17, R18, R19, R20, R21, R22, R23, R24, R25, R26, R27, R28, R29, R30, R31, R32, R33, R34, R35, R36, R37, R38, R39: 47k; R_Axial_DIN0207_L6.3mm_D2.5mm_P5.08mm_Vertical
R40: 1k; R_Axial_DIN0207_L6.3mm_D2.5mm_P5.08mm_Vertical

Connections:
+5V: C1.1, C2.1, J1.1, J1.2, J1.64, R1.2, R2.2, R3.2, R4.2, R5.2, R6.2, R7.1, R8.1, R9.1, R10.1, R11.1, R12.2, R13.2, R14.2, R15.2, R16.2, R17.1, R18.1, R19.1, R20.1, R21.1, R22.1, R23.2, R24.2, R25.2, R26.2, R27.2, R28.2, R29.1, R30.1, R31.1, R32.1, R33.1, R34.2, R35.2, R36.2, R37.2, R38.2, R39.2, R40.1
A2: J1.16, Q12.2 (G), Q14.2 (G), Q26.2 (G)
AND2: Q43.3 (D), Q50.2 (G), R26.1
B2: J1.20, Q2.2 (G)
BB2: Q3.3 (D), Q4.3 (D), Q5.2 (G), Q6.2 (G), R3.1
BB2N: Q5.3 (D), Q8.2 (G), R4.1
BD2: Q66.3 (D), Q67.2 (G), R39.1
BDN2: Q64.3 (D), Q66.2 (G), R38.1
BN2: Q2.3 (D), Q3.2 (G), R2.1
BUS2#: J1.12, Q67.3 (D)
C2: J2.1, Q20.2 (G), Q22.2 (G), Q29.2 (G)
C3: J3.1, Q30.3 (D), R18.2
EO: J1.39, Q65.2 (G)
F0: J1.59, Q32.2 (G), Q35.2 (G), Q39.2 (G), Q41.2 (G)
F0N: Q32.3 (D), Q37.2 (G), R19.2
F1: J1.62, Q33.2 (G), Q34.2 (G), Q36.2 (G), Q40.2 (G)
F1N: Q33.3 (D), Q38.2 (G), R20.2
FA: Q36.3 (D), Q37.3 (D), Q49.2 (G), R22.2
FO: Q38.3 (D), Q39.3 (D), Q51.2 (G), R23.1
FS: Q34.3 (D), Q35.3 (D), Q47.2 (G), R21.2
FX: Q42.3 (D), Q53.2 (G), R25.1
FXN: Q40.3 (D), Q42.2 (G), R24.1
G2: Q26.3 (D), Q30.2 (G), Q43.2 (G), Q46.2 (G), R16.1
GND: C1.2, C2.2, J1.3, J1.4, J1.5, J1.7, J1.63, J2.2, J2.4, J2.5, J2.6, J3.2, J3.4, J3.5, J3.6, Q1.1 (S), Q2.1 (S), Q3.1 (S), Q4.1 (S), Q5.1 (S), Q7.1 (S), Q9.1 (S), Q11.1 (S), Q12.1 (S), Q13.1 (S), Q15.1 (S), Q16.1 (S), Q17.1 (S), Q18.1 (S), Q19.1 (S), Q20.1 (S), Q22.1 (S), Q23.1 (S), Q24.1 (S), Q25.1 (S), Q27.1 (S), Q29.1 (S), Q31.1 (S), Q32.1 (S), Q33.1 (S), Q34.1 (S), Q35.1 (S), Q36.1 (S), Q37.1 (S), Q38.1 (S), Q39.1 (S), Q41.1 (S), Q42.1 (S), Q43.1 (S), Q44.1 (S), Q46.1 (S), Q48.1 (S), Q50.1 (S), Q52.1 (S), Q54.1 (S), Q57.1 (S), Q58.1 (S), Q60.1 (S), Q61.1 (S), Q62.1 (S), Q63.1 (S), Q65.1 (S), Q66.1 (S), Q67.1 (S), Q68.1 (S)
unnamed: D1.2 (A), R40.2
unnamed: D1.1 (K), Q68.3 (D)
unnamed: Q6.1 (S), Q7.3 (D)
unnamed: Q8.1 (S), Q9.3 (D)
unnamed: Q10.1 (S), Q11.3 (D)
unnamed: Q14.1 (S), Q15.3 (D)
unnamed: Q21.1 (S), Q22.3 (D)
unnamed: Q26.1 (S), Q27.3 (D)
unnamed: Q28.1 (S), Q29.3 (D)
unnamed: Q30.1 (S), Q31.3 (D)
unnamed: Q40.1 (S), Q41.3 (D)
unnamed: Q45.1 (S), Q46.3 (D)
unnamed: Q47.1 (S), Q48.3 (D)
unnamed: Q49.1 (S), Q50.3 (D)
unnamed: Q51.1 (S), Q52.3 (D)
unnamed: Q53.1 (S), Q54.3 (D)
unnamed: Q55.1 (S), Q56.3 (D)
unnamed: Q56.1 (S), Q57.3 (D)
unnamed: Q59.1 (S), Q60.3 (D)
unnamed: Q64.1 (S), Q65.3 (D)
ONE: J1.60, Q4.2 (G)
OR2: Q45.3 (D), Q52.2 (G), R28.1
P2: Q17.3 (D), Q18.3 (D), Q19.2 (G), Q21.2 (G), Q28.2 (G), Q44.2 (G), Q54.2 (G), R11.2
P2_a: Q14.3 (D), Q16.2 (G), R9.2
P2_d: Q16.3 (D), Q18.2 (G), R10.2
P2_n: Q12.3 (D), Q13.3 (D), Q17.2 (G), R8.2
PN2: Q44.3 (D), Q45.2 (G), R27.1
R2: Q59.3 (D), Q63.2 (G), Q64.2 (G), Q68.2 (G), R35.1
RA2: Q49.3 (D), Q56.2 (G), R30.2
RM2: Q55.3 (D), Q58.2 (G), R33.2
RMN2: Q58.3 (D), Q59.2 (G), R34.1
RO2: Q51.3 (D), Q57.2 (G), R31.2
RS2: Q47.3 (D), Q55.2 (G), R29.2
RX2: Q53.3 (D), Q60.2 (G), R32.2
S2: Q24.3 (D), Q25.3 (D), Q48.2 (G), R15.1
S2_a: Q21.3 (D), Q23.2 (G), R13.1
S2_d: Q23.3 (D), Q25.2 (G), R14.1
S2_n: Q19.3 (D), Q20.3 (D), Q24.2 (G), R12.1
SUB: J1.40, Q1.2 (G), Q9.2 (G)
SUBN: Q1.3 (D), Q7.2 (G), R1.1
T2: Q28.3 (D), Q31.2 (G), R17.2
XB2: Q10.3 (D), Q13.2 (G), Q15.2 (G), Q27.2 (G), R7.2
XBA2: Q6.3 (D), Q10.2 (G), R5.1
XBB2: Q8.3 (D), Q11.2 (G), R6.1
ZS1: J2.3, Q61.2 (G)
ZS1N: Q61.3 (D), Q62.2 (G), R36.1
ZS2: J3.3, Q62.3 (D), Q63.3 (D), R37.1

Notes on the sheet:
NIBBLE CARD ALU2 - ALU BIT 2: one bit of the adder/subtractor, AND, OR, XOR
Cell: 2N7000 + 47k pull-up (NMOS, see docs/gate-cell.md). 68 transistors, 40 resistors, 1 LEDs, 100 x 100 mm (docs/cards.md). From the bus header: A2, B2 (register bits), SUB (1 = subtract), ONE (B replaced by 0001: INC, DEC), F1 F0 (function), EO (1 = drive the result onto the bus). To the bus hea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
B INPUT: BB = B, or 0001 when ONE=1 (INC, DEC). Then the conditional invert: XB = BB when SUB=0, NOT BB when SUB=1 (two's complement: A - B = A + NOT B + 1, the +1 is SUB fed into the carry-in)
FULL ADDER for this bit: P = A xor XB, S = P xor Cin, Cout = A.XB + P.Cin (G = NAND(A, XB) is also NOT (A and XB); A or XB = NAND(NOT P, G)). Cin is SUB on bit 0, the carry from the card below on the others; Cout goes to the card above over the link.
FUNCTION DECODE: FS = add/sub (F1 F0 = 00), FA = and (01), FO = or (10), FX = xor (11)
RESULT SELECT, per bit: R = FS.S + FA.AND + FO.OR + FX.P. NAND-NAND form with the four-way OR split as NAND3 then NAND2 (never more than three transistors in series)
ZERO CHAIN: ZS<i> = ZS<i-1> and not R<i> (zero so far, from the card below over the link; bit 0 starts it). On bit 3: ZF = ZS3 and CF = C4 for add/sub (0 for the logic functions), both to the bus header.
BUS DRIVERS: pull BUS_i# low when EO=1 and R_i=1 (open drain, pull-ups live on the hub board)
INDICATORS: R (and on bit 3: CF, ZF)
LED_R2
Decoupling
Mounting holes
LINK IN from the bit below
LINK OUT to the bit above

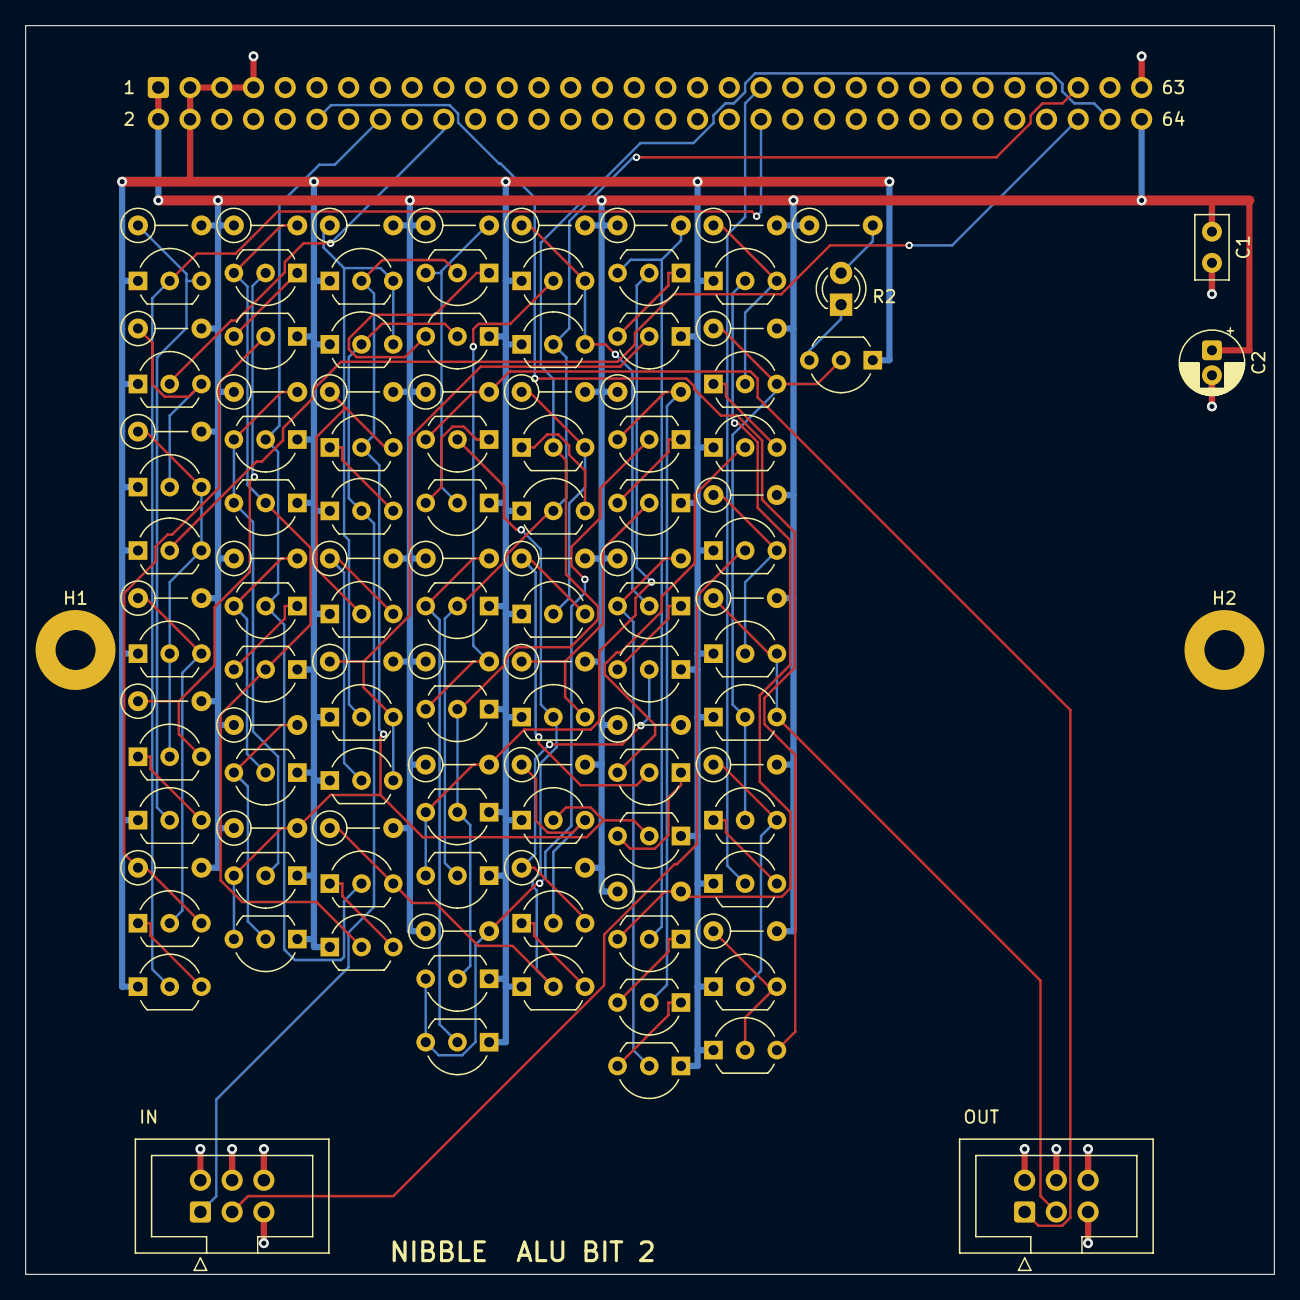
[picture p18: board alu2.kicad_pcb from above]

Board: 2 copper layers, 100.0 x 100.0 mm, 116 parts (1 on the bottom side), 71 nets.

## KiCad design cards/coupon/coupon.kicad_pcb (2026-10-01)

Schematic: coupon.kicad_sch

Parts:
C1: 100n; C_Disc_D5.0mm_W2.5mm_P2.50mm
C2: 10u; CP_Radial_D5.0mm_P2.00mm
C3: 47n; C_Disc_D5.0mm_W2.5mm_P2.50mm
D1: LED; LED_D3.0mm
D2, D3: 1N4148; D_DO-35_SOD27_P7.62mm_Horizontal
H1, H2: M3; MountingHole_3.2mm_M3_Pad
J1: IN N1 N2 N3 RST GND; PinHeader_1x06_P2.54mm_Vertical
J2: +5V GND; PinHeader_1x02_P2.54mm_Vertical
J3: BUS; IDC-Header_2x32_P2.54mm_Vertical
Q1, Q2, Q3, Q4, Q5, Q6, Q7, Q8, Q9, Q10, Q11, Q12, Q13, Q14, Q15, Q16, Q17, Q18, Q19, Q20, Q21, Q22, Q23, Q24, Q25, Q26, Q27, Q28, Q29, Q30, Q31, Q32, Q33, Q34, Q35, Q36, Q37, Q38, Q39, Q40, Q41, Q42, Q43, Q44, Q45, Q46, Q47, Q48, Q49, Q50, Q51, Q52, Q53, Q54, Q55, Q56, Q57: 2N7000; TO-92_Inline_Wide
R1, R48, R52: 10k; R_Axial_DIN0207_L6.3mm_D2.5mm_P5.08mm_Vertical
R2, R3, R4, R5, R6, R7, R8, R9, R10, R11, R12, R13, R14, R15, R16, R17, R18, R19, R20, R21, R23, R24, R25, R26, R27, R28, R29, R30, R31, R32, R33, R34, R35, R36, R37, R47: 47k; R_Axial_DIN0207_L6.3mm_D2.5mm_P5.08mm_Vertical
R22, R39: 4.7k; R_Axial_DIN0207_L6.3mm_D2.5mm_P5.08mm_Vertical
R38, R41, R49: 1k; R_Axial_DIN0207_L6.3mm_D2.5mm_P5.08mm_Vertical
R40: 3.3k; R_Axial_DIN0207_L6.3mm_D2.5mm_P5.08mm_Vertical
R42, R43, R44, R45, R46: 1Meg; R_Axial_DIN0207_L6.3mm_D2.5mm_P5.08mm_Vertical
R50: 100k; R_Axial_DIN0207_L6.3mm_D2.5mm_P5.08mm_Vertical
R51: 100; R_Axial_DIN0207_L6.3mm_D2.5mm_P5.08mm_Vertical
R53: 220k; R_Axial_DIN0207_L6.3mm_D2.5mm_P5.08mm_Vertical
TP1: TP_RING; TestPoint_Loop_D2.50mm_Drill1.0mm
TP2: RING0; TestPoint_Loop_D2.50mm_Drill1.0mm
TP3: TP_FO1; TestPoint_Loop_D2.50mm_Drill1.0mm
TP4: TP_FO10; TestPoint_Loop_D2.50mm_Drill1.0mm
TP5: TP_NAND; TestPoint_Loop_D2.50mm_Drill1.0mm
TP6: TP_NOR; TestPoint_Loop_D2.50mm_Drill1.0mm
TP7: TP_BUS; TestPoint_Loop_D2.50mm_Drill1.0mm
TP8: TP_VTO; TestPoint_Loop_D2.50mm_Drill1.0mm
TP9: X; TestPoint_Loop_D2.50mm_Drill1.0mm
TP10: TP_OSC; TestPoint_Loop_D2.50mm_Drill1.0mm
TP11: TP_Q; TestPoint_Loop_D2.50mm_Drill1.0mm
TP12: TP_DRV; TestPoint_Loop_D2.50mm_Drill1.0mm
TP13: TP_ROM; TestPoint_Loop_D2.50mm_Drill1.0mm
TP14: GND; TestPoint_Loop_D2.50mm_Drill1.0mm
TP15: +5V; TestPoint_Loop_D2.50mm_Drill1.0mm

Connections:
+5V: C1.1, C2.1, J2.1, J3.1, J3.2, J3.64, R1.1, R2.2, R3.1, R4.2, R5.1, R6.2, R7.1, R8.2, R9.1, R10.2, R11.1, R12.2, R13.1, R14.2, R15.1, R16.2, R17.1, R18.2, R19.1, R20.2, R21.1, R22.1, R23.2, R24.1, R25.2, R26.1, R27.2, R28.1, R29.2, R30.1, R31.2, R32.2, R33.1, R34.1, R35.2, R36.2, R37.1, R38.1, R39.2, R40.1, R41.1, R47.1, R48.1, TP15.1
DRVN: Q52.3 (D), R38.2, R51.1
GND: C1.2, C2.2, C3.2, J1.6, J2.2, J3.3, J3.4, J3.5, J3.7, J3.63, Q1.1 (S), Q2.1 (S), Q3.1 (S), Q4.1 (S), Q5.1 (S), Q6.1 (S), Q7.1 (S), Q8.1 (S), Q9.1 (S), Q10.1 (S), Q11.1 (S), Q12.1 (S), Q13.1 (S), Q14.1 (S), Q15.1 (S), Q16.1 (S), Q17.1 (S), Q18.1 (S), Q21.1 (S), Q22.1 (S), Q23.1 (S), Q24.1 (S), Q25.1 (S), Q26.1 (S), Q27.1 (S), Q28.1 (S), Q29.1 (S), Q30.1 (S), Q31.1 (S), Q33.1 (S), Q35.1 (S), Q37.1 (S), Q40.1 (S), Q41.1 (S), Q43.1 (S), Q45.1 (S), Q47.1 (S), Q50.1 (S), Q51.1 (S), Q52.1 (S), Q53.1 (S), Q54.1 (S), Q55.1 (S), R42.1, R43.2, R44.1, R45.2, R46.1, R49.2, R52.2, R53.2, TP14.1
IN: J1.1, Q7.2 (G), Q25.2 (G), Q54.2 (G), Q55.2 (G), R42.2
LOAD0: Q9.3 (D), R10.1
LOAD1: Q10.3 (D), R11.2
LOAD2: Q11.3 (D), R12.1
LOAD3: Q12.3 (D), R13.2
LOAD4: Q13.3 (D), R14.1
LOAD5: Q14.3 (D), R15.2
LOAD6: Q15.3 (D), R16.1
LOAD7: Q16.3 (D), R17.2
LOAD8: Q17.3 (D), R18.1
LOAD9: Q18.3 (D), R19.2
N1: J1.2, Q19.2 (G), Q22.2 (G), R43.1
N2: J1.3, Q20.2 (G), Q23.2 (G), R44.2
N3: J1.4, Q21.2 (G), Q24.2 (G), R45.1
unnamed: D1.2 (A), R41.2
unnamed: D1.1 (K), Q55.3 (D)
unnamed: D2.2 (A), R51.2
unnamed: Q19.1 (S), Q20.3 (D)
unnamed: Q20.1 (S), Q21.3 (D)
unnamed: Q32.1 (S), Q33.3 (D)
unnamed: Q34.1 (S), Q35.3 (D)
unnamed: Q36.1 (S), Q37.3 (D)
unnamed: Q38.1 (S), Q39.3 (D)
unnamed: Q39.1 (S), Q40.3 (D)
unnamed: Q42.1 (S), Q43.3 (D)
unnamed: Q44.1 (S), Q45.3 (D)
unnamed: Q46.1 (S), Q47.3 (D)
unnamed: Q48.1 (S), Q49.3 (D)
unnamed: Q49.1 (S), Q50.3 (D)
unnamed: Q56.3 (D), Q57.2 (G), R47.2
QN: Q31.2 (G), Q32.2 (G), Q51.3 (D), R37.2
RING0: Q1.2 (G), Q5.3 (D), Q6.2 (G), R6.1, TP2.1
RING1: Q1.3 (D), Q2.2 (G), R2.1
RING2: Q2.3 (D), Q3.2 (G), R3.2
RING3: Q3.3 (D), Q4.2 (G), R4.1
RING4: Q4.3 (D), Q5.2 (G), R5.2
ROW: D3.2 (A), Q54.3 (D), R40.2
RST: J1.5, Q28.2 (G), R46.2
RSTN: Q28.3 (D), Q40.2 (G), Q50.2 (G), R24.2
SA: Q26.3 (D), Q27.2 (G), R22.2, R50.1
TP_BUS: Q25.3 (D), R1.2, TP7.1
TP_DRV: D2.1 (K), R52.1, TP12.1
TP_FO1: Q7.3 (D), Q8.2 (G), R8.1, TP3.1
TP_FO10: Q8.3 (D), Q9.2 (G), Q10.2 (G), Q11.2 (G), Q12.2 (G), Q13.2 (G), Q14.2 (G), Q15.2 (G), Q16.2 (G), Q17.2 (G), Q18.2 (G), R9.2, TP4.1
TP_NAND: Q19.3 (D), R20.1, TP5.1
TP_NOR: Q22.3 (D), Q23.3 (D), Q24.3 (D), R21.2, TP6.1
TP_OSC: Q27.3 (D), Q29.2 (G), Q52.2 (G), R23.1, TP10.1
TP_Q: Q46.3 (D), Q48.2 (G), Q51.2 (G), R35.1, TP11.1
TP_Q_ckb: Q30.3 (D), Q43.2 (G), Q44.2 (G), R26.2
TP_Q_ckn: Q29.3 (D), Q30.2 (G), Q33.2 (G), Q34.2 (G), R25.1
TP_Q_dn: Q31.3 (D), Q35.2 (G), R27.1
TP_Q_m1: Q32.3 (D), Q36.2 (G), R28.2
TP_Q_m2: Q34.3 (D), Q39.2 (G), R29.1
TP_Q_mq: Q36.3 (D), Q38.2 (G), Q41.2 (G), Q42.2 (G), R30.2
TP_Q_mqi: Q41.3 (D), Q45.2 (G), R32.1
TP_Q_mqn: Q37.2 (G), Q38.3 (D), R31.1
TP_Q_qn: Q47.2 (G), Q48.3 (D), R36.1
TP_Q_sa: Q42.3 (D), Q46.2 (G), R33.2
TP_Q_sb: Q44.3 (D), Q49.2 (G), R34.2
TP_RING: Q6.3 (D), R7.2, TP1.1
TP_ROM: D3.1 (K), R53.1, TP13.1
TP_VTO: Q53.2 (G), Q53.3 (D), R39.1, TP8.1
VD2: Q26.2 (G), Q57.3 (D), R48.2
VS: Q56.1 (S), Q57.1 (S), R49.1
X: C3.1, Q56.2 (G), R50.2, TP9.1

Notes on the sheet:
NIBBLE CARD COUPON: every cell of the machine in copper, measured before any card is trusted
57 transistors, 100 x 100 mm (docs/cards.md). Power: 5 V on the 2-pin header from the bench supply (limit 300 mA), or the bus header (the hub; no other bus line is used). Drive IN, N1, N2, N3, RST from the 6-pin header (each has a 1Meg pull-down, so open = 0; RST open lets the flip-flop run). Measu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
Bench supply in, 5.0 V, current limit 300 mA
TEST LOOPS
hub pull-up
RING OSCILLATOR: 5 inverters in a loop, buffered to TP_RING. Period = 10 gate delays.
FAN-OUT: IN -> INV_A (drives 1 gate, TP_FO1) -> INV_B (drives 10 gates, TP_FO10). Compare rise times.
3-INPUT NAND (three in series, TP_NAND) and 3-INPUT NOR (three in parallel, TP_NOR) on N1..N3. Measure output low.
BUS DRIVER: open drain on IN, 10k pull-up as on the hub, TP_BUS.
OSCILLATOR BUFFERS (the clock card's): SA = NOT VD2 (VD2 is the Schmitt pair's output, drawn below) with a 4.7k pull-up drives 100k back to X; SB = NOT SA is the clock, TP_OSC.
TOGGLE FLIP-FLOP: the NAND master-slave D flip-flop (nmos.ff) with D = NOT Q, clocked by SB, reset by RSTN = NOT RST. TP_Q runs at half the oscillator rate while RST is low; RST high holds it at 0.
LINE DRIVER (D053): DRVN = NOT SB with a 1k pull-up, through 100 ohm and a diode (drawn below) into TP_DRV with a 10k pull-down. Clip 3.3 nF on TP_DRV: the CLK edge every card sees.
THRESHOLD: gate tied to drain, 4.7k pull-up. TP_VTO settles about 0.1 V above this transistor's threshold (0.6 mA).
PROGRAM ROW: ROW = NOT IN with a 3.3k pull-up, through a 1N4148 (drawn below) into TP_ROM with the hub's 220k pull-down. TP_ROM high = 5 V less a diode.
INDICATOR: LED on IN.
LED_IN
Decoupling
Mounting holes
SCHMITT TRIGGER (the clock card's, cards/clock): Q1 (gate X) and Q2 (gate = Q1's drain) share RS = 1k. Q2 on: source at 0.45 V (RD2 10k); Q1 on: source at 0.1 V (RD1 47k). VD2, Q2's drain, is the output: 0.5 V with X low, 5 V with X high.
TIMING: SA -> 100k -> X, 47n from X to GND: the clock card at its fastest setting (its pot at zero), about 500 Hz. X swings only between the two trip points, about half a volt around Vth.
LINE DRIVER (D053): DRVN (1k pull-up) through 100 ohm and a diode into TP_DRV with a 10k pull-down, as the clock card drives CLK and RST and the panel its buttons. Clip 3.3 nF from TP_DRV to GND: the ribbon and the cards' gates.
PROGRAM ROW: ROW (3.3k pull-up) through a 1N4148 into TP_ROM with the hub's 220k pull-down (D048): the M line's high is 5 V less a diode drop.


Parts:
V9001: 5
V9002: VPULSE
V9003, V9004, V9005, V9006: VPWL

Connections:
unnamed: V9001.2, V9002.2, V9003.2, V9004.2, V9005.2, V9006.2

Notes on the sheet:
TESTBENCH: IN toggles at 1 kHz, N1..N3 are stepped through 000,100,110,111, RST is high for the first millisecond. Excluded from the board; sim/tb_coupon.py is the measured bench.
.tran 0.5u 12m
.ic v(RING0)=0 v(X)=0
5 V supply (the hub board / bench supply)


Board: 2 copper layers, 100.0 x 100.0 mm, 136 parts (1 on the bottom side), 68 nets.

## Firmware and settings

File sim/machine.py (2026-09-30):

"""Whole-machine simulation (docs/plan.md): every board's kicad-cli SPICE export
in one ngspice deck, running a real program, checked tick for tick against emu.py.

    python3 machine.py programs/fib.asm --boards alu,panel,hub [--corner TYP|LO|HI|MIX] [--seed N] [--ticks N]

A board given as name@dev uses the gate list's own netlist instead of the
schematic export (for trying a design before drawing it). Corner MIX gives every
transistor a random threshold from the three models: the test that catches
latches which are only correct when all parts match.

Boards that exist are included as subcircuits. Boards that do not exist yet are
played by the emulator: the sequencer's control lines and PC, the registers' A
and B lines, come from piecewise-linear sources that reproduce the emulator's trace. So the
same deck tests the ALU alone today, ALU + registers next, and the full machine
once the sequencer exists, and a board is always judged against the hardware
around it, real or virtual.

Program memory is a behavioural model (M = f(PC) through a diode, like the
switch boards) until the memory board exists. The clock is a pulse source
gated by HLT until the clock board exists.
"""
import os, re, random, subprocess, sys
import numpy as np
import spicedat
import bus, asm, emu

HERE=os.path.dirname(os.path.abspath(__file__)); BOARDS=os.path.join(HERE,'..','boards'); OUT=os.path.join(HERE,'out')
KICAD_CLI='/Applications/KiCad/KiCad.app/Contents/MacOS/kicad-cli'
T=1e-3          # clock period
T0=2e-3         # first rising edge
STEP_DELAY=20e-6   # virtual sequencer: control lines change this long after the edge
CONTROL=['SUB','EO','AI','AO','BI','BO','BA','AB','OI','IO','II','PCE','PCL','FI','HLT','MAI','MI','MO','ONE','F0','F1','INP']
CABLE_PF=int(os.environ.get('CABLE_PF','300'))      # ribbon capacitance per header line, all cables together (see docs/mounting.md); CABLE_PF=500 in the environment for the margin rerun
CROSS_PF=int(os.environ.get('CROSS_PF','0'))        # coupling capacitance between ribbon neighbours (consecutive header pins), 0 = not modelled; about 100 pF for 3 m of 1.27 mm ribbon
VDD=float(os.environ.get('VDD','5'))                 # the supply at the hub; VDD=4.5 for a USB port at its minimum less the polyfuse and the ribbon
POR_V0=float(os.environ.get('POR_V0','0'))           # volts on the clock card's power-on reset capacitor at t=0: the release comes earlier by 220 ms * ln(VDD/(VDD-POR_V0)),
                                                     # 44 us per mV, so a sweep of POR_V0 walks the reset release across a clock period (the release is asynchronous to the clock)
HOLD=os.environ.get('HOLD','0')=='1'                  # the clock card's hold-off, on trial in the deck before it is on the card: 100 ohm and a transistor from the timing node X to ground,
                                                     # gate on RST, so the clock stands still while RST is high and its first edge comes milliseconds after the release (tb_reset_release.py)
RST_PRESS=[float(x) for x in os.environ.get('RST_PRESS','').split(',') if x]      # a finger on the panel's RST button: down at the first time, up at the second (seconds); the ticks are counted from the last release
END_AFTER_RELEASE=os.environ.get('END_AFTER_RELEASE','0')=='1'      # a --ticks 12 run ends itself 47 ms after RST fell for the last time, whenever that is (a corner whose release time is not known beforehand)
RESET_S=float(os.environ.get('RESET_S','0.2'))       # the run's allowance for the power-on reset before the ticks are budgeted (0.2 s covers the 236 ms release at MIX seed 2 for a
                                                     # full run; a t12 run there needs more); sweep_por.py, which pulls the release to about 20 ms with POR_V0, sets it to 0.03
SW=[f'SW{i}' for i in range(4)]   # the panel's data switch levels, ports of the panel subcircuit so the deck can set them
LINK=[f'OPR{i}' for i in range(8)]+['PCR','RAI']   # the sequencer-to-counter link header (D035); PCL is on the bus header
ALINK=['C1','C2','C3','ZS0','ZS1','ZS2']             # the ALU cards' carry and zero-so-far chain (2x3 links between neighbours)
CLINK=[f'TC{i}' for i in range(1,8)]                  # the counter cards' count carry (2x3 links between neighbours)
MLINK=[s for s in __import__("memory").MLINK if s!="GND"]   # the memory control card's ribbon to the slot cards
PC=[f'PC{i}' for i in range(8)]; M=[f'M{i}' for i in range(8)]
# per board: schematic path, the design module for a dev netlist (board@dev), and the internal nets to probe
BOARD={'alu':('01-alu/alu.kicad_sch','alu',[]),
       'reg':('02-registers/registers.kicad_sch','registers',['OUT0','OUT1','OUT2','OUT3']),
       'seq':('03-sequencer/sequencer.kicad_sch','sequencer',['T0','T1','T2','T3','T4','CFQ','ZFQ']),
       'ctr':('09-counter/counter.kicad_sch','counter',[]),
       'mem':('08-memory/memory.kicad_sch','memory',[]),
       'prog':('04-program/program.kicad_sch','program',[]),
       'panel':('06-panel/panel.kicad_sch','panel',[]),
       'hub':('07-hub/hub.kicad_sch',None,[]),
       'hubc':('../cards/hub/hub.kicad_sch',None,[]),
       'panela':('../cards/panela/panela.kicad_sch',('panel','build_a'),[]),
       'panelb':('../cards/panelb/panelb.kicad_sch',('panel','build_b'),[]),
       'panelc':('../cards/panelc/panelc.kicad_sch',('panel','build_c'),[]),
       'clk':('05-clock/clock.kicad_sch','clock',[]),
       'clkc':('../cards/clock/clock.kicad_sch','clock',[])}       # the clock card: the same design on a 100 x 100 card
for _i in range(4):     # the bit cards (docs/cards.md): each is a slice of its board with the bit baked in
    BOARD[f'reg{_i}']=(f'../cards/reg{_i}/reg{_i}.kicad_sch',('registers','build_bit',_i),[f'OUT{_i}'])
    BOARD[f'alu{_i}']=(f'../cards/alu{_i}/alu{_i}.kicad_sch',('alu','build_bit',_i),[])
for _i in range(8):
    BOARD[f'ctr{_i}']=(f'../cards/ctr{_i}/ctr{_i}.kicad_sch',('counter','build_bit',_i),[])
BOARD['memctl']=('../cards/memctl/memctl.kicad_sch',('memory','build_ctl'),[])
BOARD['progc']=('../cards/prog/prog.kicad_sch',('program','build_card'),[])            # the program card: one copy per four words, jumpered to its addresses
BOARD['memslot']=('../cards/memslot/memslot.kicad_sch',('memory','build_slot'),[])      # one design, eight copies with their pair jumpers set
GROUPS={'regc':[f'reg{i}' for i in range(4)],'aluc':[f'alu{i}' for i in range(4)],'ctrc':[f'ctr{i}' for i in range(8)],'memc':['memctl','memslot'],'pnl':['panela','panelb','panelc']}     # a group name on --boards stands for its cards (regc@dev: all four from the gate list)
def expand(boards):
    out=[]
    for spec in boards:
        b,_,dev=spec.partition('@')
        out+=[f'{c}@{dev}' if dev else c for c in GROUPS[b]] if b in GROUPS else [spec]
    return out
def has(boards,kind): return any(b.partition('@')[0].startswith(kind) for b in boards)     # the board, or its cards
def has_reg(boards): return has(boards,'reg')

def export(board,dev=False):
    """A board's netlist: the kicad-cli SPICE export of its schematic, or (dev) the gate list's own flat netlist."""
    if dev:
        import importlib; spec=BOARD[board][1]
        d=getattr(importlib.import_module(spec[0]),spec[1])(*spec[2:]) if isinstance(spec,tuple) else importlib.import_module(spec).build()
        assert not d.check(), d.check()
        return d.spice(vdd='+5V')
    # each process exports to its own file and reads that back: two decks built at once (gate.py -j 2, a queue's parallel runs)
    # once raced on the shared file, and one of them read alu1..alu3 while kicad-cli was still writing them (empty subcircuits,
    # an ALU with only bit 0, "ngspice aborted" and a false carry finding). The shared copy stays for inspection.
    sch=os.path.join(BOARDS,BOARD[board][0]); cir=os.path.join(OUT,f'{board}_kicad.cir'); mine=f'{cir}.{os.getpid()}'
    r=subprocess.run([KICAD_CLI,'sch','export','netlist','--format','spice','-o',mine,sch],capture_output=True,text=True)
    if not os.path.exists(mine): raise SystemExit(r.stdout+r.stderr)
    lines=[l.rstrip() for l in open(mine) if l.strip()]; os.replace(mine,cir)
    if not any(l[0] in 'MRCDQ' for l in lines): raise SystemExit(f"{board}: the export has no components\n"+r.stdout+r.stderr)
    return lines

def hold_off(l):
    """The clock card's hold-off transistor (D064): the one with its gate on the RST line."""
    w=l.split(); return l[0] in 'Mm' and len(w)>3 and w[2]=='RST'

MIX_ORDER_FILE=os.path.join(HERE,'mix_order.json')
def mix_order(write=False):
    """The order in which a board's transistors draw their models at a mixed corner: the order of its export on 2026-09-29,
    kept in mix_order.json. kicad-cli lists the symbols in the order of their ids and the builders draw the ids at random,
    so a card built again comes out in another order, and the same seed would give every transistor another threshold:
    another machine than the one the earlier runs proved. `python3 machine.py --mix-order` writes the file from the
    schematics as they are; it is run once, before a card is changed, not after."""
    import json
    if write:
        o={b:[l.split()[0] for l in export(b) if l[0] in 'Mm' and int(re.sub(r'\D','',l.split()[0]) or 0)<9000] for b in sorted(BOARD) if os.path.exists(os.path.join(BOARDS,BOARD[b][0]))}
        json.dump(o,open(MIX_ORDER_FILE,'w'),indent=0); return o
    return json.load(open(MIX_ORDER_FILE)) if os.path.exists(MIX_ORDER_FILE) else {}
MIX_ORDER=None

def subckt(board,lines,corner,rng=None,seed=1):
    """Wrap a board's export as .subckt <board> <bus ports>. Drops directives and testbench parts (refs >= 9000).
    corner TYP/LO/HI gives every transistor that model; MIX gives each transistor a random one (threshold spread between parts):
    the transistors draw in the order mix_order.json has for the board, whatever order the export lists them in; one the
    file does not know (added to the card since) draws from a generator of its own, so the others keep their models. The
    clock card's hold-off transistor (D064) is the first of those: seed + 1000, as in the decks that tried it with HOLD=1."""
    global MIX_ORDER
    assert any(l[0] in 'MRCDQ' for l in lines), f"{board}: empty netlist"      # an empty card never reaches ngspice (the export race of 2026-09-17)
    models={'TYP':'2N7000','LO':'2N7000_LO','HI':'2N7000_HI'}
    body=[]
    for l in lines:
        if l.startswith(('.','*')): continue
        ref=l.split()[0]; num=re.sub(r'\D','',ref)
        if num and int(num)>=9000: continue
        body.append(l)
    if corner=='MIX':
        if MIX_ORDER is None: MIX_ORDER=mix_order()
        refs=[l.split()[0] for l in body if l[0] in 'Mm']; num=lambda r:int(re.sub(r'\D','',r) or 0)
        order=MIX_ORDER.get(board) or sorted(refs,key=num)      # (a board the file does not have: by reference)
        if not set(order)&set(refs): order=refs                  # (the gate list's own netlist, @dev, has other references: in the order it lists them, as before)
        drawn={r:rng.choice(['LO','TYP','HI']) for r in order}                                            # a transistor the card has lost still draws: the ones after it keep theirs
        for k,r in enumerate(sorted((r for r in refs if r not in drawn),key=num)): drawn[r]=random.Random(seed+1000+k).choice(['LO','TYP','HI'])
    body=[l.replace(' 2N7000',' '+models[drawn[l.split()[0]] if corner=='MIX' else corner]) if l[0] in 'Mm' else l for l in body]
    ports=ports_of(body)
    return ports, [f".subckt {board} "+" ".join(ports)]+body+[".ends"]

def ports_of(body):
    """The bus and link signals a subcircuit body touches, in the deck's port order (recompute after adding jumper bodies)."""
    nodes=set(tok for l in body for tok in l.split()[1:])
    return [s for s in bus.SIGNALS+SW+LINK+ALINK+CLINK+MLINK if s in nodes]

def od(en,x,i,tag):
    """An ideal open-drain driver on BUS<i>#: a switch to ground closed when both en and x are high (ngspice's SW model converges where a stepping B-source does not)."""
    return [f"Ben{tag}{i} en{tag}{i} 0 V = V({en})>2.5 && V({x})>2.5 ? 5 : 0", f"S{tag}{i} BUS{i}# 0 en{tag}{i} 0 ODRV"]

def pwl(times,values,delay):
    pts=[(0,values[0])]
    for t,v in zip(times,values): pts.append((t+delay-1e-6,pts[-1][1])); pts.append((t+delay+1e-6,v))
    return "PWL("+" ".join(f"{t:.7g} {5*v}" for t,v in pts)+")"

def switch_counter(tbl):
    """The panel operator as a digital circuit (XSPICE): the switch lines follow the input list tbl, one step per fall of INP."""
    L=["Rinp INP inp_s 100k","Cinp inp_s 0 1n",
       "Aadc_inp [ inp_s ] [ d_inp ] sw_adc",f".model sw_adc adc_bridge(in_low={0.4*VDD:.3g} in_high={0.6*VDD:.3g} rise_delay=1n fall_delay=1n)",
       "Aadc_rst [ RST ] [ d_rst ] rst_adc",f".model rst_adc adc_bridge(in_low={0.6*VDD:.3g} in_high={0.7*VDD:.3g} rise_delay=1n fall_delay=1n)",
       "Ainv_inp d_inp d_inpn sw_inv",".model sw_inv d_inverter(rise_delay=10n fall_delay=10n)",
       ".model sw_dff d_dff(clk_delay=10n set_delay=10n reset_delay=10n ic=0 rise_delay=10n fall_delay=10n)",
       ".model sw_and d_and(rise_delay=10n fall_delay=10n)",".model sw_or d_or(rise_delay=10n fall_delay=10n)",
       ".model sw_dac dac_bridge(out_low=0 out_high=5 t_rise=1u t_fall=1u)"]
    for k in range(3): L.append(f"Aff{k} d_q{k}n {'d_inpn' if k==0 else f'd_q{k-1}n'} NULL d_rst d_q{k} d_q{k}n sw_dff")     # bit k toggles when bit k-1 falls
    L.append("Adac_cnt [ d_q0 d_q1 d_q2 ] [ cnt0 cnt1 cnt2 ] sw_dac")
    val=lambda n: tbl[min(n,len(tbl)-1)]
    for i in range(4):
        ones=[n for n in range(8) if (val(n)>>i)&1]
        if len(ones) in (0,8): L.append(f"Vsw{i} sw{i}_src 0 {5 if ones else 0}")
        else:
            for n in ones: L.append(f"Amin{i}_{n} [ "+" ".join(f"d_q{k}"+("" if (n>>k)&1 else "n") for k in range(3))+f" ] d_m{i}_{n} sw_and")
            if len(ones)>1: L.append(f"Aor{i} [ "+" ".join(f"d_m{i}_{n}" for n in ones)+f" ] d_sw{i} sw_or")     # a d_or wants two inputs at least
            L.append(f"Adac{i} [ {f'd_sw{i}' if len(ones)>1 else f'd_m{i}_{ones[0]}'} ] [ sw{i}_src ] sw_dac")
        L.append(f"Rsw{i} sw{i}_src SW{i} 10")
    return L
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

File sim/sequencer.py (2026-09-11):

"""Board 03: the sequencer. Step counter, instruction and operand registers, flags, two decoders and the diode
control matrix (docs/isa.md). The program counter and the return register live on board 09 (counter.py) and get
OPR7..0, PCR and RAI from this board over a link header (D035); PCL is on the bus header.

Header in : M0..M7 (program memory word), CF, ZF (from the ALU), CLK, RST.
Header out: II, PCE and the 19 matrix-driven control lines SUB EO AI AO BI BO BA AB OI IO FI HLT MAI MI MO ONE F0 F1 INP.
Bus       : BUS0..3# driven (open drain) with OPR3..0 while IO is high.
Link out  : OPR0..7, PCR, RAI (PCL goes over the bus header, pin 51).

Steps (one-hot T0..T4, master-slave flip-flops with asynchronous reset): S0 II, S1 PCE, S2 OPI+PCE (two-word
instructions only), S3 and S4 the matrix rows; DONE returns to S0. IR (4) and OPR (8) are transparent latches open
while their load line and PH1 are both high, so they capture the memory word during the low half of the clock and
are closed before the rising edge. The flags are the same kind of latch, open during FI.
"""
import nmos

COLS=['SUB','EO','AI','AO','BI','BO','BA','AB','OI','IO','FI','HLT','MAI','MI','MO','ONE','F0','F1','INP','PCL','PCR','RAI','DONE']
OPCODE={1:'LDI',2:'JMP',3:'JC',4:'JZ',5:'LOAD',6:'STORE',7:'CALL',8:'JNZ',9:'JNC'}
FAMILY={0:'NOP',1:'MOV',2:'XCH',3:'ADD',4:'SUB',5:'OUT',6:'HLT',7:'DEC',8:'INC',9:'LOADB',10:'STOREB',11:'IN',12:'RET',13:'AND',14:'OR',15:'XOR'}
TWO_WORD=(2,3,4,7,8,9)
# the matrix, exactly as docs/isa.md: instruction -> (S3 lines, S4 lines). The conditional jumps put PCL on their flag-gated rows.
RECIPE={'NOP':({'DONE'},set()),'MOV':({'BA','DONE'},set()),'XCH':({'AB','BA','DONE'},set()),
        'ADD':({'EO','AI','FI','DONE'},set()),'SUB':({'SUB','EO','AI','FI','DONE'},set()),'OUT':({'AO','OI','DONE'},set()),
        'HLT':({'HLT'},set()),'DEC':({'ONE','SUB','EO','AI','FI','DONE'},set()),'INC':({'ONE','EO','AI','FI','DONE'},set()),
        'LOADB':({'BO','MAI'},{'MO','AI','DONE'}),'STOREB':({'BO','MAI'},{'AO','MI','DONE'}),'IN':({'INP','AI','DONE'},set()),
        'RET':({'PCR','DONE'},set()),'AND':({'F0','EO','AI','FI','DONE'},set()),'OR':({'F1','EO','AI','FI','DONE'},set()),
        'XOR':({'F0','F1','EO','AI','FI','DONE'},set()),'LDI':({'IO','AI','DONE'},set()),'JMP':({'PCL','DONE'},set()),
        'JC':({'DONE'},set()),'JZ':({'DONE'},set()),'LOAD':({'IO','MAI'},{'MO','AI','DONE'}),'STORE':({'IO','MAI'},{'AO','MI','DONE'}),
        'CALL':({'RAI','PCL','DONE'},set()),'JNZ':({'DONE'},set()),'JNC':({'DONE'},set())}
LINK=['OPR0','OPR1','OPR2','OPR3','OPR4','OPR5','OPR6','OPR7','PCR','RAI']     # PCL is a header line (pin 51)

GROUP_TITLES={
 'clock':'TWO-PHASE CLOCK (as on the register board): PH1 opens masters and latches while CLK is low, PH2 copies to slaves while CLK is high.  RSTN for the asynchronous resets.',
 'steps':'STEP COUNTER, one-hot: T0N (0 = step S0, so reset lands in S0), T1..T4.  Next state: S0 -> S1; S1 -> S2 if the opcode is two-word (TWO) else S3; S2 -> S3; S3 -> S4 unless DONE; S4 or DONE -> S0.  II = T0, PCE = T1 or T2, OPI = T2.',
 'ir':'INSTRUCTION REGISTER (4 bits, the opcode) and OPERAND REGISTER (8 bits): transparent latches.  IR and OPR3..0 open while II and PH1; OPR7..4 open while OPI and PH1.  They close before the rising edge.',
 'opdec':'OPCODE DECODER: IR3..0 -> OP0#..OP15# (active low), through a pair of 2-to-4 predecoders so no NAND has more than two transistors in series.  TWO = JMP or JC or JZ or CALL or JNZ or JNC.',
 'famdec':'FAMILY DECODER: OPR3..0 -> F0#..F15#, the member of the opcode-0000 family.',
 'flags':'FLAGS: CFQ, ZFQ latched from the ALU while FI and PH1.  Only ADD SUB INC DEC AND OR XOR assert FI.',
 'rows':'MATRIX ROWS: one per instruction for S3, and for S4 where the instruction uses it (the four memory accesses) and for every free opcode.  Row = NOR(OPn#, T3N) or NOR(OPn#, T4N); family rows also include F#.  JC/JZ have a conditional row for PCL: NOR(OP#, T3N, flag-not); JNZ/JNC (D044) the same with the flag itself.  10k pull-ups: a row drives up to ten diodes into 1 Meg column pull-downs.',
 'matrix':'THE CONTROL MATRIX: a diode from a row to a column pulls that control line high while the row is active.  Every crossing has a diode pad pair on the board (D040); the ones drawn DNP are empty.  A new one-word instruction on the free rows OP8..OP15 (S3 and S4) is diodes soldered in; a conditional jump needs a flag-gated row, i.e. a new board.',
 'cols':'COLUMN BUFFERS (D041): the diode node of each column has a 1 Meg pull-down and feeds one inverter; a second inverter (22k) drives the control line, so the line falls through a transistor in microseconds instead of decaying through 1 Meg into every board and the ribbons.',
 'outs':'STEP OUTPUTS to the header: II = T0, PCE = T1 or T2.',
 'bus':'BUS DRIVERS: OPR3..0 onto BUS3#..BUS0# while IO (LDI, LOAD n, STORE n).',
 'leds':'INDICATORS: steps T0..T4, IR3..0, OPR7..0, CF, ZF.',
}

def decoder(d,prefix,bits,outp):
    """4-to-16 decoder, active-low outputs outp0#..outp15#, from bits [b0,b1,b2,b3]."""
    b0,b1,b2,b3=bits
    for b in bits: d.inv(f'{prefix}{b}N',b)
    d.nor(f'{prefix}L0',b1,b0); d.nor(f'{prefix}L1',b1,f'{prefix}{b0}N'); d.nor(f'{prefix}L2',f'{prefix}{b1}N',b0); d.nor(f'{prefix}L3',f'{prefix}{b1}N',f'{prefix}{b0}N')
    d.nor(f'{prefix}H0',b3,b2); d.nor(f'{prefix}H1',b3,f'{prefix}{b2}N'); d.nor(f'{prefix}H2',f'{prefix}{b3}N',b2); d.nor(f'{prefix}H3',f'{prefix}{b3}N',f'{prefix}{b2}N')
    for n in range(16): d.nand(f'{outp}{n}#',f'{prefix}H{n>>2}',f'{prefix}L{n&3}',pu='10k' if (outp,n)==('OP',0) else nmos.PU_DEFAULT)   # OP0# feeds 32 family rows
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

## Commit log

2026-09-09 Origin: hand-made 3-bit RTL add/subtract calculator, as of 2026-08-17
    The KiCad project exactly as Nikola built it by hand: 419 x 2N3904, 1,087
    resistors, keypad encoders, sign-magnitude adder/subtractor, result register,
    4-to-16 decoder, reference gates. Untouched, bugs included; see
    docs/KNOWN-ISSUES.md in a later commit. The 2N3904 SPICE model the project
    uses is added under lib/.
    Design entirely by Nikola. Commit made by Claude on Nikola's behalf.
    Claude-Session: https://claude.ai/code/session_019vcbW37ERmrjZaWq55Er3J
    [Untitled.kicad_pcb, Untitled.kicad_sch]
2026-09-09 Experiment: sequential multiplier/divider on the RTL calculator (simulation only)
    480 extra 2N3904s on a generated sheet, a testbench sheet, generator and
    verification tooling, and the results: 16/16 scripted operations and 256/256
    exhaustive cases pass on the kicad-cli exported netlist. Also carries the two
    origin bug fixes on its copy of the root sheet. Not built.
    Designed and verified by Claude; constraints and review by Nikola.
    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
    [Untitled.kicad_sch, muldiv.kicad_sch, testbench.kicad_sch]
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2026-09-09 Board 01 ALU: 4-bit two's-complement adder/subtractor in NMOS, generated and verified
    sim/: NMOS cell library (2N7000 + 47k), KiCad schematic writer, bus pinout,
    ALU logic, testbench, plots. lib/: 2N7000 VDMOS model with 0.8 V and 3.0 V
    threshold corners, LED model.
    boards/01-alu: 137 transistors, 78 resistors, 6 LEDs, 50-pin bus header.
    ERC clean. kicad-cli export simulated exhaustively: 512/512 at all three
    threshold corners, worst settle 73 us. Plots and JSON in sim_results/.
    Fixes #1, fixes #2 (structurally: no sign-magnitude converter exists).
    Fixes #3 (no bipolar fan-out limit in NMOS). Fixes #4 (stimulus derived
    from simulated gate delay).
    Designed and verified by Claude; architect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
    [alu-testbench.kicad_sch, alu.kicad_sch]
2026-09-09 Coupon, front panel and bus hub schematics (order 1), all ERC clean
    coupon/: ring oscillator, fan-out 1 vs 10, NAND3/NOR3, bus driver, LED, test loops.
    boards/06-panel: DIP switches through 10k, DIP-4 bus data switches, RC + Schmitt
    debounced CLK/RST buttons with diode outputs, 1Meg pull-downs, 42 LEDs.
    boards/07-hub: USB-B + polyfuse, bus pull-ups, bulk caps, 8 headers, test loops.
    Debounce verified with contact bounce at three threshold corners; panel export simulated.
    Decisions D013-D015. tools/: freerouting jars (2.1 runs headless on Java 21).
    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
    [coupon-testbench.kicad_sch, coupon.kicad_sch, hub.kicad_sch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]
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2026-09-09 Coupon, ALU and hub PCBs routed and DRC clean; fab outputs
    pcb.py: power pre-routed as per-column rails from the tile geometry, fixed in
    the DSN so the router cannot move them; GND pour before routing; DRC-verified
    ground stitching; inset outline while routing; retries until zero unconnected.
    Coupon 112x94, ALU 156x214, hub 130x98 mm. docs/bring-up.md and docs/order-1.md.
    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
    [alu-B_Courtyard.gbr, alu-B_Cu.gbl, alu-B_Fab.gbr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]
2026-09-10 Front panel PCB routed and DRC clean; all four order-1 boards complete
    Panel 200x222 mm: LED rows labelled A3..B0 / D3..PC0 / M7..M0 / flags+control,
    DIP switches with silk labels, CLK/RST buttons, pull-down grid, header at the
    bottom. pcb.py: pre-routed power fixed in the DSN, keep-best across attempts,
    DRC-verified ground stitching. Decision D016.
    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
    [panel-B_Courtyard.gbr, panel-B_Cu.gbl, panel-B_Fab.gbr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]
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2026-09-10 Design v2, instruction set: opcode family, indirect memory access, IN, CALL/RET, INC/DEC, bit operations
    Opcode 0000 becomes a family whose operand nibble selects one of sixteen
    operand-free instructions, freeing eight opcodes. New instructions:
    LOAD [B] and STORE [B] (B as a pointer, what makes the memory board worth
    building), DEC and INC (loops that do not clobber B), IN (the panel's data
    switches as an input port), CALL and RET (one return register), AND, OR,
    XOR. The four spare header pins become ONE, F0, F1 and INP.
    The data memory board moves into the main build and everything ships in one
    fab order once every board passes the machine gate (D030 to D033). WRL/WRH
    replace PWL/PWH beca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
    [asm.py, bus.py, emu.py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]
2026-09-10 64-pin header in the generators; hub M pull-downs; panel switch rows; register board design; MIX corner
    sim/bus.py, frame.py and ksch.py move to the 2x32 header (pin 1 at y-38.1 on
    the symbol, pin 64 ground pre-routed). The hub gains the eight 1 Meg M-line
    pull-downs and grows to 136 x 115 mm; the panel gains a DIP-4 for MI, MO,
    WRL, WRH, LED rows for PC7..4 and the new lines, and grows to 200 x 240 mm.
    The ALU's decoupling moves right to clear the longer header.
    sim/registers.py is board 02: A, B, OUT as master-slave flip-flops behind
    AND-OR input muxes, 366 transistors, with a two-phase non-overlapping clock
    (D033). nmos.ff() takes a shared clock pair. First machine-deck run of the
    regist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
    [build_alu.py, build_hub.py, build_panel.py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]
2026-09-10 Cell library: flip-flop slave nodes renamed, series-node collision check, ideal open-drain switch model
    The register board's Q outputs read 15 in every state: the flip-flop's slave
    NAND was named <q>_s1, the same name the q NAND uses for its internal series
    node. nmos.check() now refuses any net that collides with a series node.
    spicedat.py reads ngspice wrdata files with numpy in seconds instead of minutes.
    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
    [nmos.py]
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2026-09-10 Machine deck: ideal open-drain drivers, registers compared from first write (D034), gate batch runner
    The B-source drivers made the LO corner abort with 'timestep too small';
    switch-model drivers do not. Hardware A, B and OUT power on at 15 while the
    emulator says 0, so a register is compared only from the tick after the
    program first writes it. gate.py runs every program at every corner in a
    thread pool and writes one summary table.
    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
    [gate.py, machine.py]
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2026-09-10 PCB flow: every pre-routed rail is fixed, freerouting log per board, --passes; ngspice options for the LO corner
    Any net drawn in a plan's rails is marked fixed in the DSN, not only power.
    freerouting's output goes to <board>.freerouting.log so a long run can be
    watched; its -mp flag does not cap passes, so pcb.py has its own --passes.
    The big boards use track 0.2 mm and clearance 0.15 mm. The testbenches use
    gear integration with cshunt, abstol and chgtol set, which is what stops the
    LO corner aborting.
    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
    [registers-testbench.kicad_sch, registers.kicad_sch]
2026-09-10 Sequencer board 03: step counter, IR and operand latches, two decoders, 37-row diode matrix, flags (D035)
    524 transistors and 83 diodes. Five steps with rstn flip-flops; IR, OPR and
    the flags are transparent latches. Every instruction has one S3 row and the
    four memory accesses have an S4 row. The first attempt was one 1,045
    transistor board, half a metre square: the sequencer is now this board plus
    the counter board 09, joined by a 12-pin link. The isa.md matrix text is the
    37 rows as built.
    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
    [sequencer.kicad_sch]
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2026-09-10 Clock board 05: source-coupled Schmitt RC oscillator, RUN/STEP, halt gate, power-on reset (D036)
    Three oscillators failed in simulation before this one: two inverters around
    an RC settle at an operating point, a MOSFET astable falls into its both-on
    state, and reading the Schmitt pair at the first drain lets the loop settle
    half way. The shared source resistor moves both trip points with one
    transistor. tb_clock.py passes at TYP, LO, HI and six mixed seeds, 390 to
    610 Hz.
    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
    [clock.kicad_sch]
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2026-09-10 Machine deck: real sequencer, counter, program pages, data memory and clock boards
    The deck picks up each board's export when asked for it and plays the rest:
    virtual sequencer, PC and link, data memory and input port. Program boards
    are one subcircuit per 16-word page with the jumpers and switches closed
    from the map. With the clock board the tick is found from CLK edges rather
    than assumed. Flag compare is skipped while FI holds the latch transparent.
    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
    [machine.py]
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2026-09-10 Data memory testbench: three fills of every slot, read back, interleaved writes
    The memory board had no schematic gate of its own, only the list program at
    TYP on the machine deck. The bench changes the bus and the control lines at
    the same instant, the worst case the machine only approaches at some corners,
    and the board as designed fails 47 of 217 steps at every corner: the write
    stacks see the next tick's bus data while the write line is still dropping.
    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
    [tb_memory.py]
2026-09-10 Data memory: the write ends at the clock edge (D037)
    The write lines were WR = slot AND MI. At the tick boundary the bus data
    changes while MI is still dropping through a 22k pull-up, so the write
    stacks saw the next tick's bus with the write still on and flipped cells:
    TYP passed, the mixed-threshold corner failed (list.asm lost bit 1 on every
    read at seed 2), and the new testbench failed 47 of 217 steps at every
    corner. Now MIN = NAND(MI, PH1) with a 4.7k pull-up: the write runs in the
    second half of the tick and drops within microseconds of the edge, like the
    address latch. One more transistor (747). The regenerated export passes
    217/217 at TYP, LO, HI and three mixed seeds.
    Co-Authored-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
    [memory.kicad_sch]
2026-09-10 PCB flow: freerouting 1.9 instead of 2.1; design rules re-synced after the last save
    Headless, freerouting 2.1.0 ignores -mp, router.max_passes and job_timeout:
    a board it cannot finish runs for hours and never writes the SES, so the
    blocked nets cannot be seen. 1.9.0 stops after the passes and writes what it
    has. pcbnew.SaveBoard rewrites the project file with KiCad's defaults, so
    DRC judged every board at 0.2 mm clearance; the rules are written again
    after the final save.
    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
    [pcb.py]
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2026-09-10 Machine deck: retry an aborted transient with ten times the shunt capacitance
    list.asm at the mixed corner with the memory export aborted at the first
    clock edge ('timestep too small' on a low-threshold transistor); the same
    deck runs with cshunt=1e-11.
    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
    [machine.py]
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2026-09-10 ALU routed: DRC zero, nothing unconnected
    Freerouting 1.9.0, 40 passes; the project rules are re-synced after the
    final save so DRC runs at the board's own clearance.
    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
    [alu-B_Courtyard.gbr, alu-B_Cu.gbl, alu-B_Fab.gbr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]
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2026-09-10 Clock routed: DRC zero, nothing unconnected
    Three hand-placed parts sat on their neighbours' courtyards: the two
    oscillator pull-ups moved 6 mm above their transistors and the STEP diode
    moved clear of the RUN switch.
    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
    [clock-B_Courtyard.gbr, clock-B_Cu.gbl, clock-B_Fab.gbr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]
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2026-09-10 Silkscreen out from under the connectors; testbench parts kept off the board
    The renders showed the 'BUS (pin 1 left)' label under every top-edge
    header shroud and the clock's name half under its header; the registers
    board name ran into a mounting hole, and the registers testbench's four
    bus-driver diodes were being loaded onto the board and parked off its
    edge. Testbench symbols (refs 9000 and up) are now written with on_board
    and in_bom off and pcb.py skips them too. pcb.py --silk replaces a routed
    board's silk from the plan without re-routing; ALU and clock done that
    way, DRC still zero. The program board's caps move beside the second
    header so its label fits below it.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
    [alu-B_Courtyard.gbr, alu-B_Cu.gbl, alu-B_Fab.gbr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]
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2026-09-10 Sequencer: buffered matrix columns (D041); S4 rows and pads at every crossing (D040)
    list.asm at MIX seeds 2 and 3 failed on the whole machine: a control line
    falls only through its 1 Meg column pull-down into every board's gates
    and the ribbons, 350 to 440 us to 1 V bare and 800 us with cables, most
    of a tick, so a register mux sat half open across a clock edge. Each
    column's diode node now feeds one inverter and a second inverter (22k)
    drives the line. 46 transistors.
    The matrix draws a diode at every crossing, DNP where the design has
    none, so the pads are on the board; the eight free opcodes get S4 rows;
    row pitch 2.54 mm; the pull-downs' GND rail moved beside them (it ran
    through their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
    [sequencer.kicad_sch]
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2026-09-11 ISA: JNZ and JNC (D044), opcodes 1000 and 1001
    Jump if zero clear and jump if carry clear, two-word like the other jumps.
    The emulator gets the two opcodes (the assembler follows it), the sequencer
    two more flag-gated rows (45 rows, 87 diodes, 592 transistors), the ISA doc
    the rows and the corrected row and diode counts, and programs/loops.asm
    exercises both: test_emu passes all twelve programs.
    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
    [emu.py, sequencer.py]
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2026-09-11 Cards: memory control and slot pair cards, 217/217 on their exports at TYP, LO, HI and MIX
    memctl (MAR, MIN, MON on a chained 2x6 ribbon) and memslot (two 4-bit
    slots of the pair three jumpers select, one design, eight cards). Both
    route DRC clean in one pass. tb_memory cards: the control card and eight
    jumpered slot cards from the kicad-cli exports, three fills, interleaved
    writes and bus noise, 217/217 at TYP, LO, HI and MIX seed 1.
    The jumpers bring MAR1..3 or their complements onto a slot card, so the
    deck makes them ports of the slot subcircuit (machine.ports_of); left
    inside they floated and every read came from pair 7. machine.py also
    learns the card names for the program, clock, hub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
    [memctl-B_Courtyard.gbr, memctl-B_Cu.gbl, memctl-B_Fab.gbr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]
2026-09-14 Sequencer: routed on four layers at the card pitch, 0 unconnected, DRC clean, proven in the machine gate
    boards/03-sequencer at 245 x 255 mm (D051): layer 2 a ground pour around a
    few routed tracks, layer 3 a third routing layer, the tiles at 7.68 mm. The
    ninth route closed it, with freerouting 2.4.1 headless. The rules that got it
    there, now in D051's amendment and the board README: the power nets out of
    the router's network (their copper fixed), the ground layer a signal layer
    the router may use (marked as a power plane it cannot join even one tile;
    fenced off it plateaued near 40 open), the matrix column tails ending on a
    fixed via with a stub on layer 3, the +5V feed along the top edge a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
    [sequencer-B_Courtyard.gbr, sequencer-B_Cu.gbl, sequencer-B_Fab.gbr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]
2026-09-14 Cards: the eight counter bit cards, count carry over the chained link ribbon, proven in the machine gate
    ctr0..7 from counter.build_bit: the program counter bit with its load,
    count and clear, the count carry TC<i+1> = TC<i> and PC<i> handed on
    over the 2x3 links (IN, LINK, OUT; bit 7 ends the chain). All eight
    route DRC clean, 0 unconnected. Machine gate with the counter cards in
    the deck (aluc, hubc, regc, seq, ctrc, memc, progc, pnl): eleven of
    twelve programs at TYP, 0 mismatches (lfsr failed on the testbench's
    virtual reset, rerun queued); fib, alu, gcd, list, logic and call at LO,
    HI, MIX1 and MIX2, 24 of 24, 0 mismatches; fib, list, calc at TYP and LO
    and logic at TYP with 500 pF on e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
    [ctr0-B_Courtyard.gbr, ctr0-B_Cu.gbl, ctr0-B_Fab.gbr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]
2026-09-14 Cards: the bus hub, one header per face, the 64 lines pre-routed, pull-downs at 220k (D047, D048)
    cards/hub: a 2x32 header top and bottom, one per column face, the 64
    lines carried straight through as pre-routed copper; ground a wired ring
    instead of a pour (D047); USB 5 V in with a 750 mA fuse, the bus
    pull-ups for BUS3..0 and the M-line pull-downs. The pull-downs are 220k,
    not 1 Meg (D048): with 1 Meg an M line fell through in 0.59 ms and calc
    read wrong words. Routed DRC clean, 0 unconnected. Proven in the machine
    gate as hubc in the card deck: eleven of twelve programs at TYP, 24 of 24
    corner runs, the 500 pF margin runs, 0 mismatches.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
    [hub-B_Courtyard.gbr, hub-B_Cu.gbl, hub-B_Fab.gbr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]
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2026-09-14 Cards: the gate coupon as a 100 x 100 card, powered from the bus header
    cards/coupon: the 2N7000 + 47k cell in copper to measure before any card
    is trusted: a ring oscillator (gate delay = period / 10), fan-out 1 against
    fan-out 10, NAND and NOR output lows, driven from a 4-pin header with 1 Meg
    pull-downs, read at test loops. Power from the bus header, so it sits in a
    column like any card. Routed DRC clean, 0 unconnected; its testbench
    schematic is the same gate list.
    Claude-Session: https://claude.ai/code/session_01RktbhdQjDu7SpFpvkevyUU
    [coupon-B_Courtyard.gbr, coupon-B_Cu.gbl, coupon-B_Fab.gbr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]
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2026-09-14 Cards: the clock card, HLT delayed 0.22 ms into the gate (D050), tb_clock passes on its export at TYP, LO and HI
    cards/clock: the RC oscillator with the 1 Meg pot, the fast/slow jumper
    (47 nF / 2.2 uF), the RUN switch, the STEP button line and the power-on
    reset. HLT reaches the clock gate through 100k into 2.2 nF (D050): in the
    card machine's calc deck the run ended one count short because HLT rose
    microseconds after the last rising edge and the gate cut the pulse the
    counter cards were still copying through their master-slave latches. With
    the delay the pulse that started the halt step completes. Routed DRC
    clean, 0 unconnected. tb_clock on the kicad-cli export: TYP 610 Hz duty
    0.55, LO 40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
    [clock-B_Courtyard.gbr, clock-B_Cu.gbl, clock-B_Fab.gbr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]
2026-09-14 machine.py: sample each tick before the real clock's edge starts; fib passes on the card deck with the clock card
    The clock card's rising edge takes 35 us from 0.5 V to 3.5 V and the
    cards step at about 2.4 V, so sampling 5 us before the 3.5 V crossing read
    the state after the step (fib: 232 mismatches on a run that halted
    correctly after 126 edges). sample() now times an edge where CLK leaves
    1.5 V; rescored, fib on aluc+hubc+regc+seq+ctrc+memc+progc+pnl+clkc at
    TYP: 127 ticks, 0 mismatches.
    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
    [machine.py]
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2026-09-14 Hub: bench-supply screw terminal and a 1.5 A polyfuse (D052)
    The machine as built draws up to about 1.2 A (281 LEDs behind 1k, plus
    the pull-ups), more than the 750 mA fuse and a computer's USB port were
    ever going to carry. The hub now takes 5 V from a 5.08 mm screw terminal
    on its left edge (the Kungber bench supply, 5.0 V with the limit at
    1.5 A) as well as from the USB-B socket, both through a Bel 0ZRE0150FF
    1.5 A polyfuse.
    Routed with freerouting 2.4.1: 1.9 put an M5 via inside the 0.35 mm
    bundle of the 64 bus lines and shorted M4/M5/M7 on two runs. KiCad DRC
    and the JLCPCB-minimum DRC (0.127 track/space, 0.3/0.5 via, 0.5
    hole-to-hole) both report no errors and nothing unconnected. Ren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
    [hub-B_Courtyard.gbr, hub-B_Cu.gbl, hub-B_Fab.gbr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]
2026-09-14 Harness: the clock card resets the simulated machine, ticks aligned to its release
    Until now every whole-machine run was reset by the testbench (a 100 ohm
    pulse source on RST), and with the clock card in the deck its power-on
    capacitor started charged, so the card's own reset never fired in
    simulation. With a real clock machine.py now adds no reset source, starts
    the clock card's oscillator and POR capacitors empty, and runs 0.2 s plus
    3.5 ms per tick.
    That exposed how the card's RST lets go: it drifts from 4 V to 2.4 V over
    8 ms (five clock periods at 610 Hz) before the Schmitt pair's hysteresis
    pulls it down, so which clock edge first moves the machine depends on the
    transistors' threshol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
    [machine.py]
2026-09-15 Harness: climb the ngspice ladder on an operating-point failure too
    fib at the mixed corner, seed 2, with the clock card resetting the
    machine: ngspice could not find the starting operating point (gmin,
    source stepping and the transient op all failed, "trouble with
    m.xalu0.mq20"), wrote no data, and machine.py gave up because the ladder
    only retried a transient that had aborted mid-run. An operating-point
    failure now climbs the same ladder; the third rung (gmin 1e-10, itl4 50)
    converges and the run passes: 127 ticks, 0 mismatches. Seed 1 passed on
    the first rung. So the slow release of the card's reset, which lets
    transistors of different thresholds let go on different clock edges, has
    not d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
    [machine.py]
2026-09-17 Gate: a smoke mode (--ticks) that reports on a whole deck in half an hour
    Every harness fault of the last three days showed within the first
    twelve ticks of a program (the reset alignment at tick 1, the switch
    timetable at tick 2, the counter's convergence at the first IN), yet
    each was found a day later because a whole-machine deck reports only
    when it finishes. gate.py --ticks N now runs the first N ticks of every
    program, keeps the files apart under a _tN suffix, and says in the row
    when a run needed the ngspice retry ladder. Proven on the virtual deck
    (fib and gcd, twelve ticks, 21 s). The card deck with the clock card
    takes about half an hour per program: run it before every long queue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
    [gate.py, machine.py]
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2026-09-21 Harness audit: a run ends at the halt, a gate resumes where it was cut
    After three harness faults in a week, machine.py and gate.py were read
    end to end before any more multi-day runs. What changed:
    - A deck with the clock card ends itself about 9 ms after HLT rises,
    enough to see the clock stop. The oscillator keeps swinging behind
    the gate, so the idle tail after a halt cost as much solver time as
    running (40 % of fib's run). ngspice evaluates a stop condition only
    on a saved node, so the stop node is in the .save list.
    - The time budget is 5 ms a tick (3.5 was too tight for a 4.25 V
    supply; measured periods: 1.64 ms TYP, 2.47 LO, 1.72 HI) and a run
    that ends with fewer clock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
    [gate.py, machine.py]
2026-09-22 Harness: the panel switches follow the machine, one input per IN
    With the clock card in the deck the harness no longer knows when each
    tick happens (the card's 121 ms power-on reset, then 400 to 600 Hz),
    yet the panel's data switches were still stepped from the emulator's
    timetable. Every program that reads its inputs (calc, gcd, sort) read
    the last value of its list at the first IN and failed the TYP gate; it
    read as a fault in the input port.
    The switches now follow the machine the way an operator does: the next
    input is set once each IN instruction has finished. INP is debounced
    through 100k/1n, squared up by a tanh (a zero-time step does not
    converge: "timestep too small" on every rung)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
    [machine.py]
2026-09-22 Harness: the switch counter is smooth everywhere
    gcd at LO aborted on every rung of the ngspice ladder ("timestep too
    small"), each time at a quiet moment with nothing switching, each time
    naming the first transistor of the netlist. The same deck without the
    switch counter ran through, and one with the counter's max(0,x) pump
    replaced by a smooth knee still aborted, in a different quiet moment.
    The pump sat on its kink whenever the input line was idle, and the
    pwl() lookup of the input list had kinks of its own; a Newton solver
    sitting on a kink fails at random. The hardware is not implicated.
    The pump is now 0.025 x (1 + tanh(1000 x)), the lookup a staircase of
    tanh steps 0.1 V wide centre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
    [machine.py]
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
